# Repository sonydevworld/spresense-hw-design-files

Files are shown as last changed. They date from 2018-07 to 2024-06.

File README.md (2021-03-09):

# HW Informations.

Here you will find information about Spresense HW that you need if you would like to design your own boards.

| Product Name | User Friendly Name |
| --- |:---:|
| CXD5602PWBMAIN1 | Spresense main board |
| CXD5602PWBEXT1 | Spresense extension board |
| CXD5602PWBLM1 | Spresense LTE extension board|
| CXD5602PWBCAM1 | Spresense camera board |

The datasheets for the chipset is available from [Sony Semiconductor Solutions Corporation Website](https://www.sony-semicon.co.jp/e/products/smart-sensing/spresense/)

## Reference informations are here.

GNSS: GNSS chip antenna information <br>
Pin: Pin information <br>
main_board_addon_board: Add-on board design guideline <br>
Case: case design samples <br>

## License
These files are licensed under a [Creative Commons Attribution Share-Alike license](LICENSE.txt).

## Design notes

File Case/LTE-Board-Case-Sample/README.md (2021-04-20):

# The sample case for Spresense LTE extension board

Spresense LTE拡張 & Mainボード向けのケースのサンプルCADです。

 - LTE拡張ボード+Mainボードの組み合わせ
 - Mainボードのみ

で、ネジ止めできて使えます。

（ネジ情報）
https://developer.sony.com/develop/spresense/docs/hw_docs_ja.html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

ご自由にお使いください！

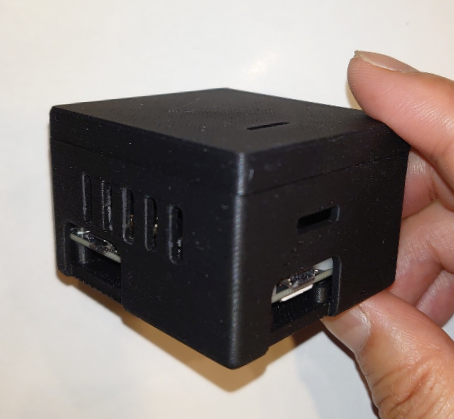
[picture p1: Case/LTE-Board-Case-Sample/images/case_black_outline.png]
black_outline


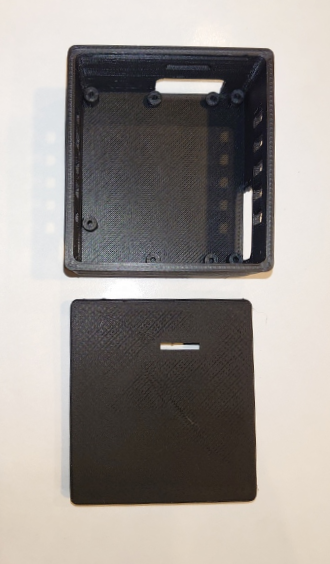
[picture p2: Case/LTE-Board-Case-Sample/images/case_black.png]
black


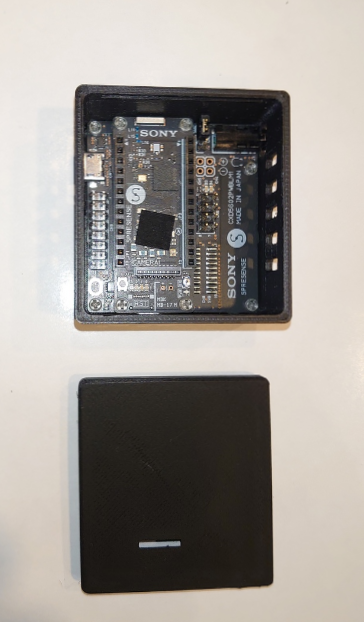
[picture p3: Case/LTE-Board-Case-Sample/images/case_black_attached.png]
black_attached


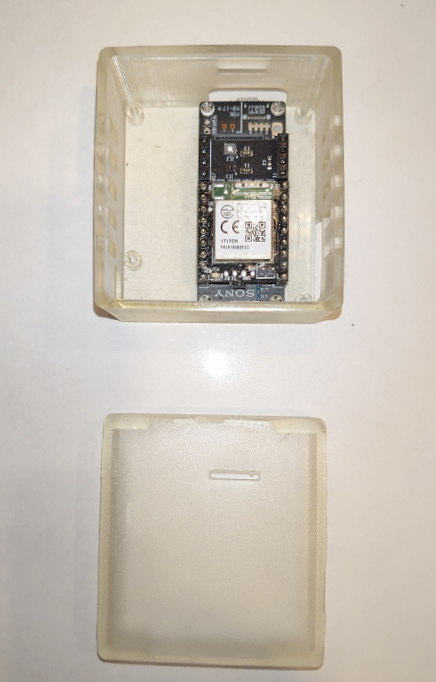
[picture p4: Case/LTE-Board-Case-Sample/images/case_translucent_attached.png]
translucent_attached


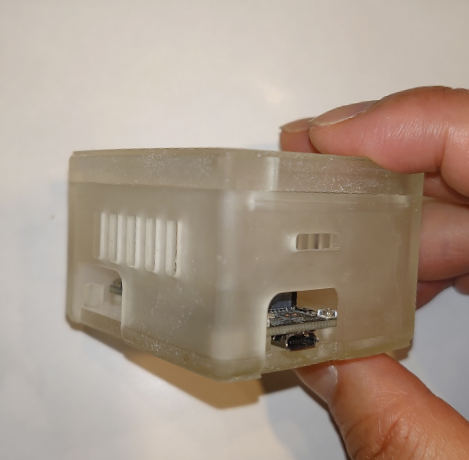
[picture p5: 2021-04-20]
Case/LTE-Board-Case-Sample/images/case_translucent_outline.png

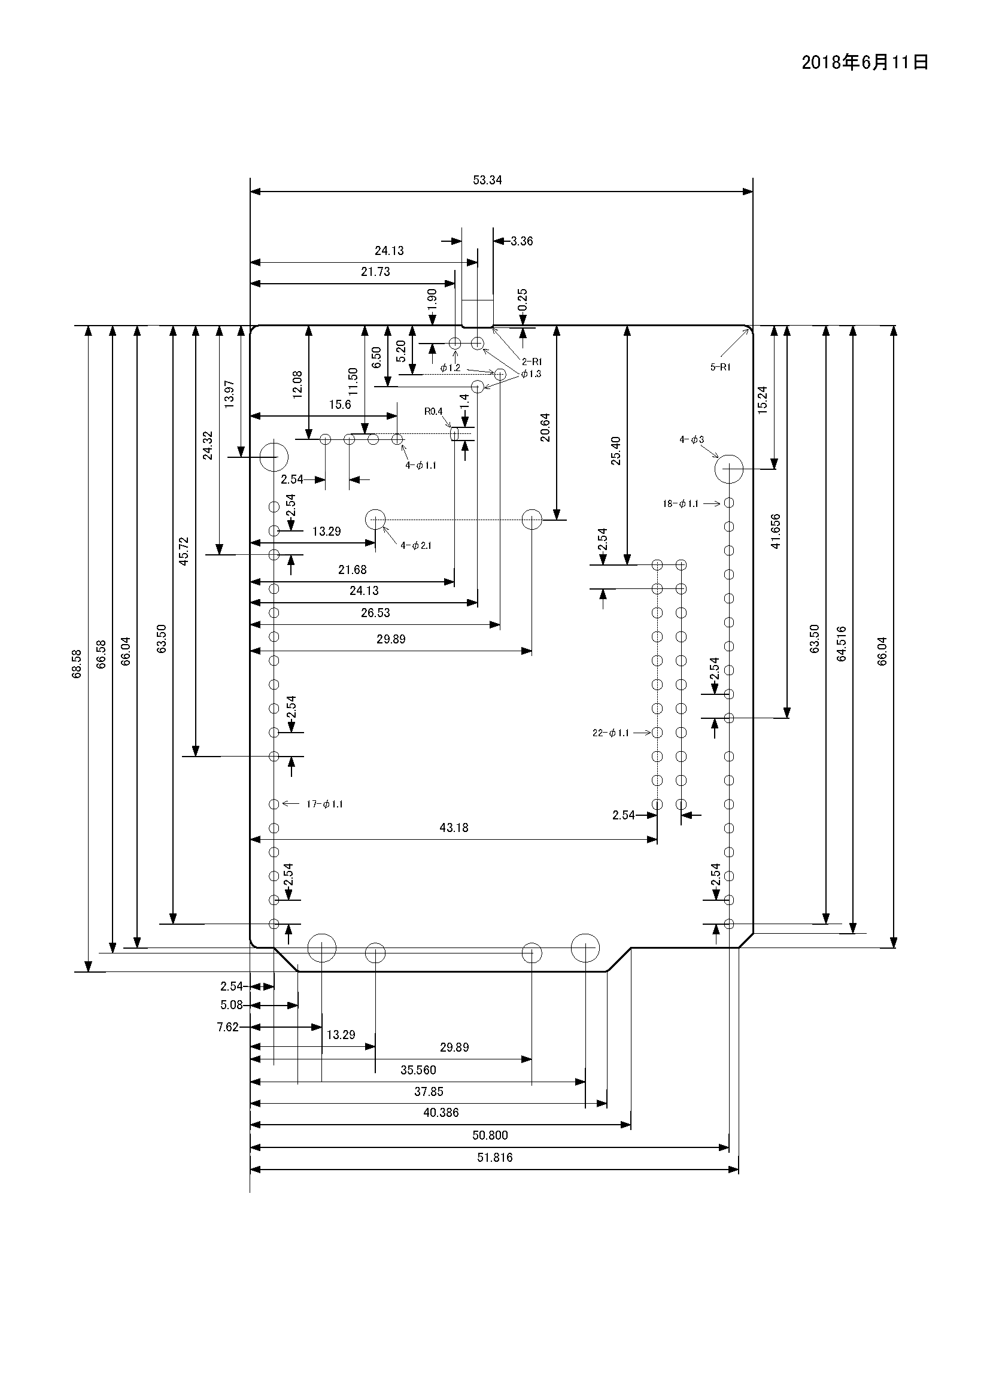
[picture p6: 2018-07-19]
CXD5602PWBEXT1/board_dimensions/CXD5602PWBEXT1_board_dimensions_ja.png

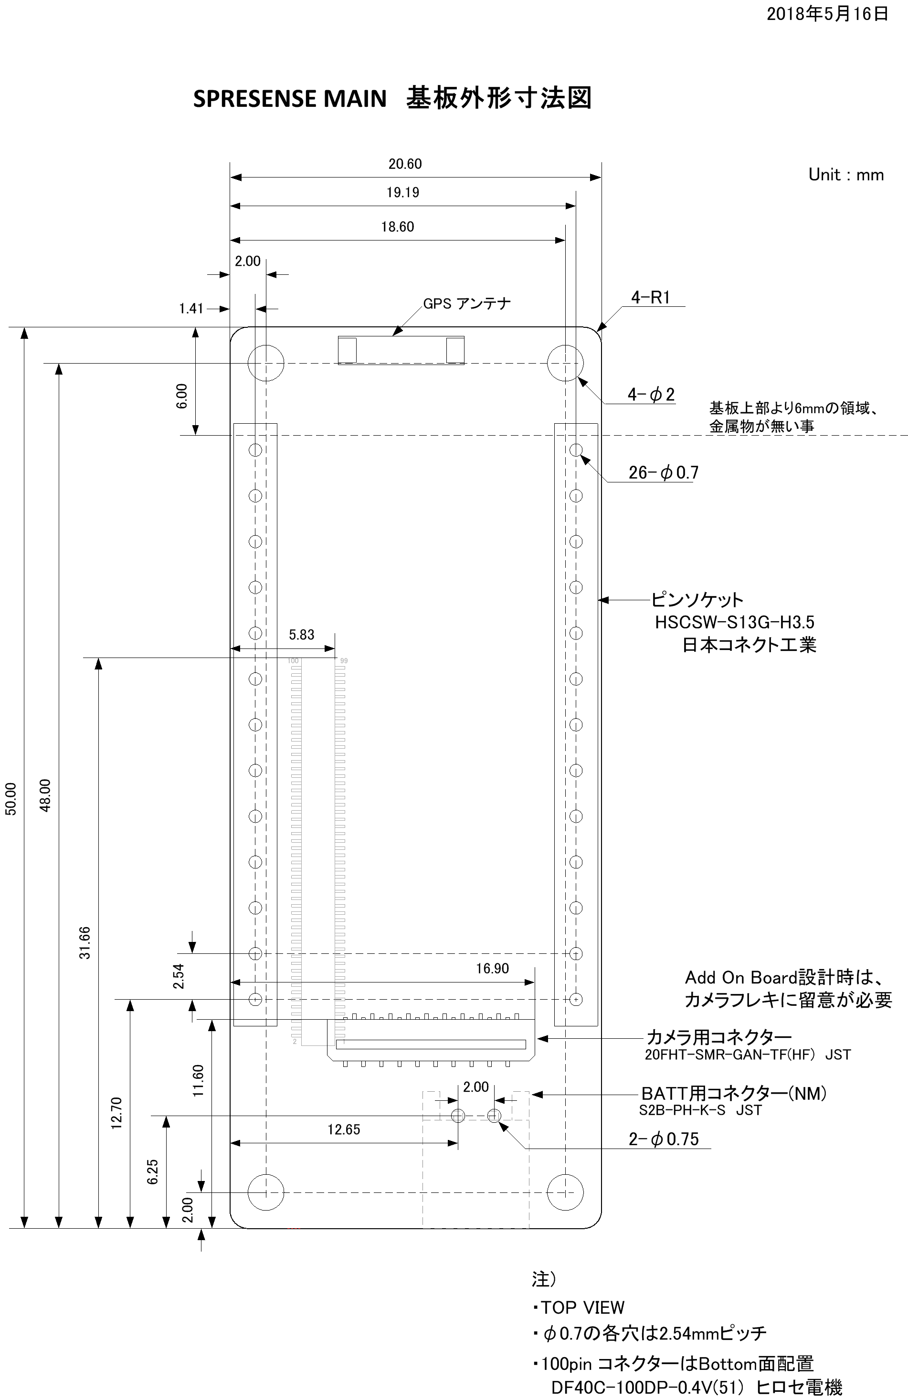
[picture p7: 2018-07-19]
CXD5602PWBMAIN1/board_dimensions/CXD5602PWBMAIN1_board_dimensions_ja.png

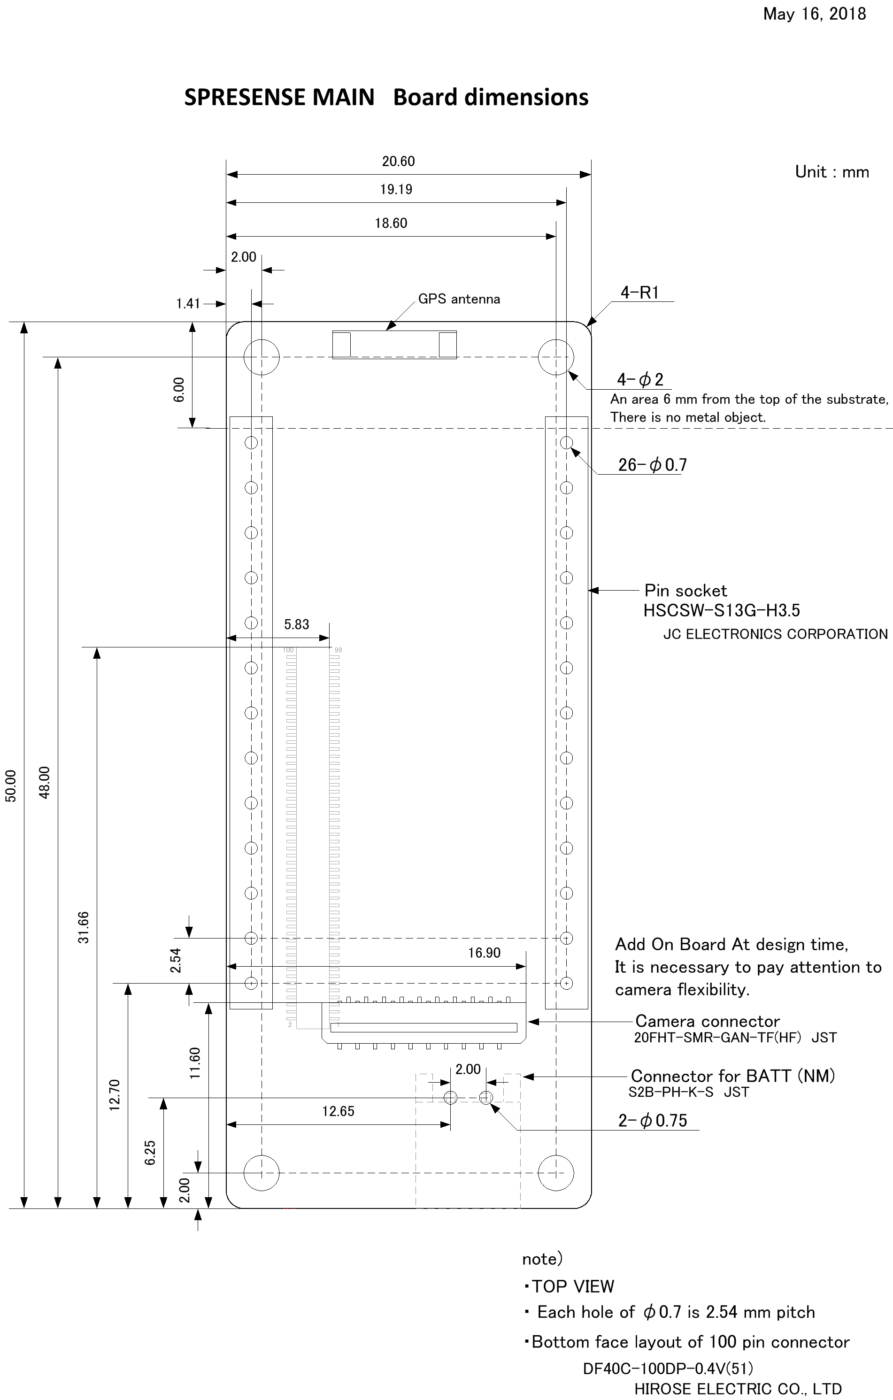
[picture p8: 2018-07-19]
CXD5602PWBMAIN1/board_dimensions/CXD5602PWBMAIN1_board_dimensions_en.png

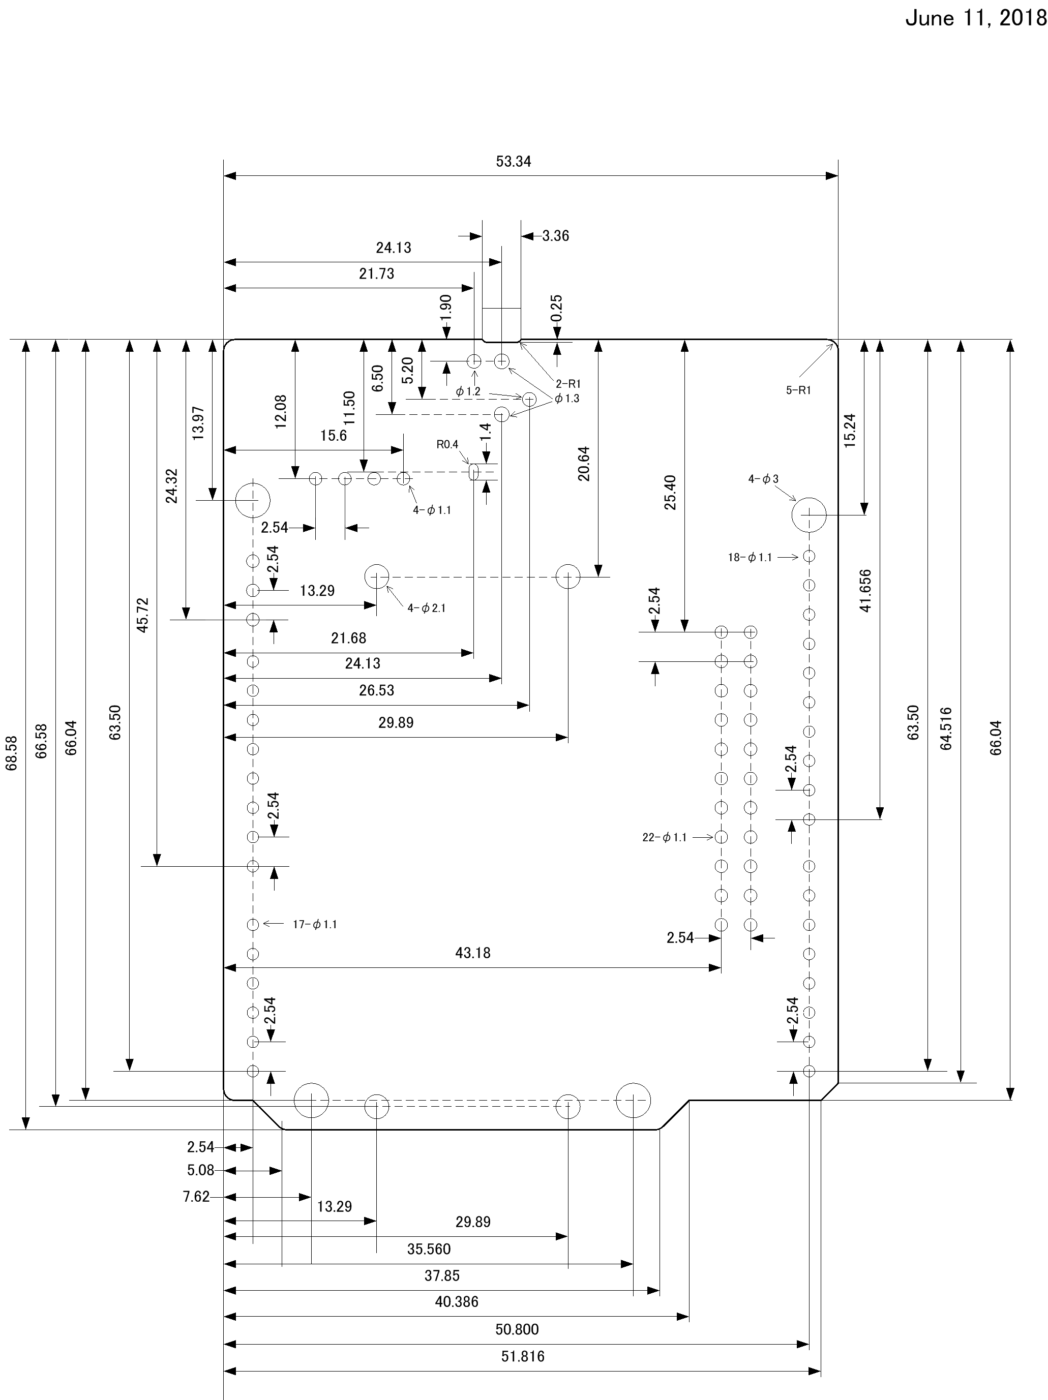
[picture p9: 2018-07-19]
CXD5602PWBEXT1/board_dimensions/en_drawing_20180611.png

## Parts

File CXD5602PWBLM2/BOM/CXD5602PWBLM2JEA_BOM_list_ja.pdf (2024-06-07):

CXD5602PWBLM2JEA BOM List | Sony Semiconductor Solutions
Qty | Ref | 名称 | Model | ベンダー
22 | C14,C27,C28,C30,C31,C32,C33,C34,C 35,C36,C37,C38,C39,C44,C45,C46,C5 0,C61,C64,C66,C67,C68 | セラミックコンデンサ 1uF (6.3V X5R 0603) | | 村田製作所
19 | C15,C16,C18,C19,C20,C21,C22,C23,C 29,C40,C41,C42,C43,C52,C54,C6,C62 ,C7,C8 | セラミックコンデンサ 0.1uF (16V X5R 0603) | | 村田製作所
2 | C25,C51 | セラミックコンデンサ 10uF（10V X5R 1608） | | 村田製作所
1 | C26 | セラミックコンデンサ 4700pF（25V X7R 0603) | | 村田製作所
1 | C55 | セラミックコンデンサ 15pF (50V C0G 0603) | | 村田製作所
2 | C56,C58 | セラミックコンデンサ 22uF (6.3V X5R 1608) | | 村田製作所
1 | CN1 | USB コネクタ (Micro-B) | UB-MC5BR3-SD204-4S-1 | 日本圧着端子製造
1 | CN10 | nano SIM コネクタ | FCD910-6M | TXGA
1 | CN11 | U.FL同軸コネクタ | U.FL-R-SMT-1 | ヒロセ電機
1 | CN2 | ピンヘッダー (2.54mm/3極) | HSAWW6-S03G-H2.5 | 日本コネクト工業
1 | CN3 | ボ-ドトゥボ-ドコネクタ(リセプタクル) 100極 | DF40HC(3.0)-100DS-0.4V （51） | ヒロセ電機
1 | CN6 | ピンヘッダー (2.54mm/2列/8極) | HSAWW6-D08G-H2.5 | 日本コネクト工業
1 | CN7 | MicroSD カードコネクタ | ST11S008V4HR2000 | 日本航空電子
1 | CN9 | ピンヘッダー (2.54mm/2列/16極) | HSAWW6-D16G-H2.5 | 日本コネクト工業
1 | CP1 | LTE モジュール | LBAD0XX1SC-602 | 村田製作所
3 | D1,D2,D5 | ショットキバリアダイオード | CUS15S30 | 東芝デバイス
1 | D3 | LED 青 (1005) | SMLP14BCNWT86N | ローム
1 | IC1 | LDO電圧レギュレータ (3.3V) | TCR3DF33 | 東芝デバイス
1 | IC10 | システムリセットIC | PST8416UL | ミネベアミツミ
1 | IC12 | DC/DCコンバーター | RP506K001C-TR | 日清紡マイクロデバイス
2 | IC13,IC14 | ロードスイッチ IC TCK111G | TCK111G | 東芝デバイス
1 | IC2 | LDO電圧レギュレータ (3.3V) | RP122K331D-TR | 日清紡マイクロデバイス
1 | IC3 | ワンゲート バスバッファ | TC7SZ126AFS | 東芝デバイス
1 | IC4 | ヘッドフォンアンプ | NJU72040V(TE2) | 日清紡マイクロデバイス
1 | IC5 | SDIO ロジックレベル変換付きポート拡張IC | TXS02612RTWR | テキサス・インスツルメン
3 | IC6,IC7,IC8 | 双方向ロジックレベル変換IC 4ch | LSF0204RUTR | テキサス・インスツルメン
1 | IC15 | ワンゲート バスバッファ | TC7SZ125AFS | 東芝デバイス
2 | IC16,IC9 | 双方向ロジックレベル変換IC 2ch | LSF0102DCTR | テキサス・インスツルメン
1 | J1 | ヘッドフォンジヤツク (4極) | 03-925R0-32BKA | エクセル電子
1 | L7 | チップインダクタ 4.7nH (2016) | DFE201612E-4R7M=P2 | 村田製作所
1 | Q1 | MOSFET Ｎ-ch | SSM6N58NU | 東芝デバイス
2 | Q2,Q4 | MOSFET Ｎ-ch | RUM002N02T2L | ローム

1 | Q3 | NPN デジタルトランジスタ | DTC044EMT2L | ローム
6 | R101,R37,R38,R39,R93,R95 | チｯプ抵抗 47KΩ (1/16W 1005 5%)
22 | R11,R18,R19,R22,R29,R3,R30,R34,R3 5,R36,R40,R44,R45,R49,R51,R6,R65,R 66,R89,R9,R98,R99 | チップ抵抗 0Ω（1005)
2 | R13,R15 | チｯプ抵抗 470KΩ (1/16W 1005 1%)
2 | R20,R21 | チｯプ抵抗 3.9KΩ (1/16W 1005 1%)
3 | R23,R24,R33 | チｯプ抵抗 2.2KΩ (1/16W 1005 5%)
4 | R25,R31,R32,R86 | チｯプ抵抗 100KΩ (1/16W 1005 5%)
1 | R27 | チｯプ抵抗 330KΩ (1/16W 1005 5%)
1 | R28 | チｯプ抵抗 4.7MΩ (1/16W 1005 5%)
1 | R4 | チｯプ抵抗 100KΩ (1/16W 1005 1%)
5 | R41,R42,R43,R48,R68 | チｯプ抵抗 470KΩ (1/16W 1005 5%)
1 | R5 | チｯプ抵抗 18KΩ (1/16W 1005 1%)
16 | R52,R53,R54,R56,R57,R58,R59,R60,R 61,R62,R70,R71,R79,R80,R87,R88 | チｯプ抵抗 1KΩ (1/16W 1005 5%)
1 | R63 | チｯプ抵抗 620KΩ (1/16W 1005 1%)
1 | R64 | チｯプ抵抗 110KΩ (1/16W 1005 1%)
1 | R69 | チｯプ抵抗 100Ω (1/16W 1005 5%)
1 | R7 | チｯプ抵抗 1MΩ (1/16W 1005 5%)
2 | R72,R81 | チｯプ抵抗 180KΩ (1/16W 1005 5%)
4 | R73,R77,R90,R92 | チｯプ抵抗 10KΩ (1/16W 1005 1%)
1 | R74 | チップ抵抗 0Ω（1608)
2 | R75,R76 | チｯプ抵抗 27KΩ (1/16W 1005 1%)
2 | R84,R85 | チｯプ抵抗 620KΩ (1/16W 1005 5%)
2 | R91,R94 | チｯプ抵抗 62KΩ (1/16W 1005 1%)
1 | S1 | プッシュスイッチ | SKRPADE010 | アルプスアルパイン
2 | VR1,VR2 | チｯプバリスタ (1005) | AVRL101A3R3FTA | TDK

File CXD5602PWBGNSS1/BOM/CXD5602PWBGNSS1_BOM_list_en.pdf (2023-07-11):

CXD5602PWBGNSS1W BOM List | Sony Semiconductor Solutions
Qty | Ref | Name | Model | Vender
2 | C1,C18 | Ceramic capacitor 1uF (6.3V X5R 0603)
11 | C10,C12,C14,C15,C16,C17,C19,C20, C22,C7,C8 | Ceramic capacitor 0.1uF (16V X5R 0603)
4 | C11,C13,C21,C23 | Ceramic capacitor 4.7uF (6.3V X5R 0603)
2 | C2,C9 | Ceramic capacitor 1000pF (25V X7R 0603)
2 | C3,C4 | Ceramic capacitor 100pF (50V C0G 0603)
1 | C5 | Ceramic capacitor 4.7pF (50V C0G 0603)
1 | C6 | Ceramic capacitor 3.3pF (50V C0G 0603)
2 | CN1,CN2 | Pin Socket (2.54mm pitch/13P) | HSCSW-S13G-L5.6 | JC Electronics
1 | D1 | Schottky diode | CUS10S30 | Toshiba Electronic Devices & Storage
1 | IC1 | Power Switch IC | XC8109AC10ER-G | TOREX SEMICONDUCTOR (https://product.torexsemi.com/ja/series/xc8109)
1 | IC2 | Load Switch IC | TCK107AG | Toshiba Electronic Devices & Storage
1 | IC3 | GNSS navigation IC | CXD5610GF-T2 | Sony Semiconductor Solutions
1 | J1 | U.FL coaxial connector | U.FL-R-SMT-1 | Hirose Electric
3 | L1,L7,L8 | Chip ferrite bead (0603) | BLM03AG121SN1 | Murata
2 | L10,L9 | Chip ferrite bead (0603) | BLM03AX121SN1D | Murata
1 | L2 | Chip inductor 33nH (1005) | LQG15HS33NJ02D | Murata
1 | L3 | Chip inductor 3.9nH (0603) | LQP03TN3N9B02D | Murata
1 | L4 | Chip inductor 9.1nH (0603) | LQP03TN9N1J02D | Murata
1 | L5 | Chip inductor 12nH (0603) | LQP03TN12NJ02D | Murata
1 | L6 | Chip inductor 6.8nH (0603) | LQP03TN6N8J02D | Murata
1 | R1 | Chip resistor 470KΩ (1/20W 0603 1%)
2 | R10,R12 | Chip resistor 0Ω(1005)
1 | R15 | Chip resistor 100KΩ (1/20W 0603 1%)

2 | R17,R19 | Chip resistor 1Ω (0.125W 1005 1%)
1 | R18 | Chip resistor 470Ω (1/20W 0603 1%)
3 | R2,R3,R4 | Chip resistor 47KΩ (1/20W 0603 1%)
2 | R6,R7 | Chip resistor 4.7KΩ (1/20W 0603 1%)
1 | RV1 | EMI filter (0603) | LXES03TBB1-141 | Murata
1 | SAW1 | SAW filter (GNSS) | SAWFZ1G17AB0E0A | Murata
1 | X1 | Crystal oscillator 26MHz (TCXO) | NT1612SA 26MHz | Nihon Dempa Kogyo
1 | X2 | Tuning fork crystal oscillator 32.768KHｚ | SH‑32R | Seiko Instruments

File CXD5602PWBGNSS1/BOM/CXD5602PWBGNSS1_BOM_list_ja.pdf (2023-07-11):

CXD5602PWBGNSS1W BOM List | Sony Semiconductor Solutions
Qty | Ref | 名称 | Model | ベンダー
2 | C1,C18 | Ceramic capacitor 1uF (6.3V X5R 0603)
11 | C10,C12,C14,C15,C16,C17,C19,C20, C22,C7,C8 | Ceramic capacitor 0.1uF (16V X5R 0603)
4 | C11,C13,C21,C23 | Ceramic capacitor 4.7uF (6.3V X5R 0603)
2 | C2,C9 | Ceramic capacitor 1000pF (25V X7R 0603)
2 | C3,C4 | Ceramic capacitor 100pF (50V C0G 0603)
1 | C5 | Ceramic capacitor 4.7pF (50V C0G 0603)
1 | C6 | Ceramic capacitor 3.3pF (50V C0G 0603)
2 | CN1,CN2 | ピンソケット (2.54mmピッチ/13極) | HSCSW-S13G-L5.6 | 日本コネクト工業
1 | D1 | ショットキバリアダイオード | CUS10S30 | 東芝デバイス＆ストレージ
1 | IC1 | 電源スイッチ IC | XC8109AC10ER-G | トレックス・セミコンダクター (https://product.torexsemi.com/ja/series/xc8109)
1 | IC2 | ロードスイッチIC | TCK107AG | 東芝デバイス＆ストレージ
1 | IC3 | GNSS測位IC | CXD5610GF-T2 | ソニーセミコンダクタソリューションズ
1 | J1 | U.FL同軸コネクタ | U.FL-R-SMT-1 | ヒロセ電機
3 | L1,L7,L8 | チップフェライトビーズ (0603) | BLM03AG121SN1 | Murata
2 | L10,L9 | チップフェライトビーズ (0603) | BLM03AX121SN1D | Murata
1 | L2 | Chip inductor 33nH (1005) | LQG15HS33NJ02D | Murata
1 | L3 | Chip inductor 3.9nH (0603) | LQP03TN3N9B02D | Murata
1 | L4 | Chip inductor 9.1nH (0603) | LQP03TN9N1J02D | Murata
1 | L5 | Chip inductor 12nH (0603) | LQP03TN12NJ02D | Murata
1 | L6 | Chip inductor 6.8nH (0603) | LQP03TN6N8J02D | Murata
1 | R1 | Chip resistor 470KΩ (1/20W 0603 1%)
2 | R10,R12 | Chip resistor 0Ω(1005)
1 | R15 | Chip resistor 100KΩ (1/20W 0603 1%)

2 | R17,R19 | Chip resistor 1Ω (0.125W 1005 1%)
1 | R18 | Chip resistor 470Ω (1/20W 0603 1%)
3 | R2,R3,R4 | Chip resistor 47KΩ (1/20W 0603 1%)
2 | R6,R7 | Chip resistor 4.7KΩ (1/20W 0603 1%)
1 | RV1 | EMIフィルタ (0603) | LXES03TBB1-141 | Murata
1 | SAW1 | SAWフィルタ (GNSS) | SAWFZ1G17AB0E0A | Murata
1 | X1 | 温度補償型水晶発振器 26MHｚ | NT1612SA 26MHz | 日本電波工業
1 | X2 | 音叉型水晶発振器 32.768KHｚ | SH‑32R | セイコーインスツル

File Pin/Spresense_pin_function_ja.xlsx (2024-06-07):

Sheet: ピンリスト
Main |  | Ext |  | Cam |  | LTE(LM1) |  | LTE(LM2) |  | 回路図上の名前 | ArduinoIDE 上の名称 | SDK上の名称 | SDK上の ピン番号 | タイプ | dir | 電圧 | 電源投入後 の状態 |  | Arduino起動後 |  | SDK起動後 |  | 接続先 | ピングループ |  | CXD5602GG ピン機能 |  |  |  | 最大絶対定格 電圧(V) | 拡張ボード上の機能 | 説明
Ref | ピン | Ref | ピン | Ref | ピン | Ref | ピン | Ref | ピン |  |  |  |  |  |  |  | dir | 初期値 | dir | 初期値 | dir | 初期値 |  | モード名 | 仕様書 | モード0 | モード1 | モード2 | モード3
JP1 | 1 |  |  |  |  |  |  |  |  | GND | － | － | － | Power | － | － | － | － | － | － | － | － | － | － | － | － | － | － | －
JP1 | 2 |  |  |  |  |  |  |  |  | UART2_TX | D01 | PIN_UART2_TXD | 67 | Digital | I/O | 1.8 | － | Hi-Z | － | Hi-Z | － | Hi-Z | CXD5602GG | UART2 | P1n | GPIO | UART2_TXD | － | GPIO | 2.5
JP1 | 3 |  |  |  |  |  |  |  |  | UART2_RX | D00 | PIN_UART2_RXD | 68 | Digital | I/O | 1.8 | － | Hi-Z | － | Hi-Z | － | Hi-Z | CXD5602GG | UART2 | P1n | GPIO | UART2_RXD | － | GPIO | 2.5
JP1 | 4 |  |  |  |  |  |  |  |  | UART2_RTS | D28 | PIN_UART2_RTS | 70 | Digital | I/O | 1.8 | － | Hi-Z | － | Hi-Z | － | Hi-Z | CXD5602GG | UART2 | P1n | GPIO | UART2_RTS | － | GPIO | 2.5
JP1 | 5 |  |  |  |  |  |  |  |  | UART2_CTS | D27 | PIN_UART2_CTS | 69 | Digital | I/O | 1.8 | － | Hi-Z | － | Hi-Z | － | Hi-Z | CXD5602GG | UART2 | P1n | GPIO | UART2_CTS | － | GPIO | 2.5
JP1 | 6 |  |  |  |  |  |  |  |  | I2S0_BCK | D26 | PIN_I2S0_BCK | 93 | Digital | I/O | 1.8 | － | Hi-Z | － | Hi-Z | － | Hi-Z | CXD5602GG | I2S0 | P1v | GPIO | I2S0_BCK | － | GPIO | 2.5
JP1 | 7 |  |  |  |  |  |  |  |  | I2S0_LRCK | D25 | PIN_I2S0_LRCK | 94 | Digital | I/O | 1.8 | － | Hi-Z | － | Hi-Z | － | Hi-Z | CXD5602GG | I2S0 | P1v | GPIO | I2S0_LRCK | － | GPIO | 2.5
JP1 | 8 |  |  |  |  |  |  |  |  | SPI5_CS_X | D24 | PIN_SPI5_CS_X | 76 | Digital | I/O | 1.8 | － | Hi-Z | － | Hi-Z | － | Hi-Z | CXD5602GG | EMMCA | P1p | GPIO | EMMC_CMD | SPI5_CS_X | GPIO | 2.5
JP1 | 9 |  |  |  |  |  |  |  |  | SPI5_SCK | D23 | PIN_SPI5_SCK | 75 | Digital | I/O | 1.8 | － | Hi-Z | － | Hi-Z | － | Hi-Z | CXD5602GG | EMMCA | P1p | GPIO | EMMC_CLK | SPI5_SCK | GPIO | 2.5
JP1 | 10 |  |  |  |  |  |  |  |  | 3.3V | － | － | － | Power | O | 3.3 | O | － | O | － | O | － | － | － | － | － | － | － | －
JP1 | 11 |  |  |  |  |  |  |  |  | 1.8V | － | － | － | Power | O | 1.8 | O | － | O | － | O | － | － | － | － | － | － | － | －
JP1 | 12 |  |  |  |  |  |  |  |  | SEN_IRQ | D22 | PIN_SEN_IRQ_IN | 37 | Digital | I/O | 1.8 | － | Hi-Z | － | Hi-Z | － | Hi-Z | CXD5602GG | SEN_IRQ_IN | P1e | GPIO | SEN_IRQ_IN | － | － | 2.5
JP1 | 13 |  |  |  |  |  |  |  |  | SEN_AIN4 | A2 | LPADC2 | － | Analog | I | ～0.7 | I | － | I | － | I | － | CXD5602GG |  | － | － | － | － | － | 1.05
JP2 | 1 |  |  |  |  |  |  |  |  | XRST | － | (SPR_RST_X) | － | Digital | O | 1.8 | － | Low | O | High | O | High | CXD5602GG | － | － | － | － | － | －
JP2 | 2 |  |  |  |  |  |  |  |  | 1.8V | － | － | － | Power | O | 1.8 | O | － | O | － | O | － | － | － | － | － | － | － | －
JP2 | 3 |  |  |  |  |  |  |  |  | 3.7V(4.0V) | － | － | － | Power | I/O | 3.6-4.4 | O | － | O | － | O | － | － | － | － | － | － | － | － | 7
JP2 | 4 |  |  |  |  |  |  |  |  | GPIO | D21 | PIN_EMMC_DATA3 | 80 | Digital | I/O | 1.8 | － | Hi-Z | － | Hi-Z | － | Hi-Z | CXD5602GG | EMMCB | P1q | GPIO | EMMC_DATA3 | － | GPIO | 2.5
JP2 | 5 |  |  |  |  |  |  |  |  | GPIO | D20 | PIN_EMMC_DATA2 | 79 | Digital | I/O | 1.8 | － | Hi-Z | － | Hi-Z | － | Hi-Z | CXD5602GG | EMMCB | P1q | GPIO | EMMC_DATA2 | － | GPIO | 2.5
JP2 | 6 |  |  |  |  |  |  |  |  | I2S0_DATA_IN | D19 | PIN_I2S0_DATA_IN | 95 | Digital | I/O | 1.8 | － | Hi-Z | － | Hi-Z | － | Hi-Z | CXD5602GG | I2S0 | P1v | GPIO | I2S0_DATA_IN | － | GPIO | 2.5
JP2 | 7 |  |  |  |  |  |  |  |  | I2S0_DATA_OUT | D18 | PIN_I2S0_DATA_OUT | 96 | Digital | I/O | 1.8 | － | Hi-Z | － | Hi-Z | － | Hi-Z | CXD5602GG | I2S0 | P1v | GPIO | I2S0_DATA_OUT | － | GPIO | 2.5
JP2 | 8 |  |  |  |  |  |  |  |  | SPR_SPI5_MISO | D17 | PIN_SPI5_MISO | 78 | Digital | I/O | 1.8 | － | Hi-Z | － | Hi-Z | － | Hi-Z | CXD5602GG | EMMCA | P1p | GPIO | EMMC_DATA1 | SPI5_MISO | GPIO | 2.5
JP2 | 9 |  |  |  |  |  |  |  |  | SPR_SPI5_MOSI | D16 | PIN_SPI5_MOSI | 77 | Digital | I/O | 1.8 | － | Hi-Z | － | Hi-Z | － | Hi-Z | CXD5602GG | EMMCA | P1p | GPIO | EMMC_DATA0 | SPI5_MOSI | GPIO | 2.5
JP2 | 10 |  |  |  |  |  |  |  |  | GND | － | － | － | Power | － | － | － | － | － | － | － | － | － | － | － | － | － | － | －
JP2 | 11 |  |  |  |  |  |  |  |  | I2C0_SCL | D15 | PIN_I2C0_BCK | 44 | Digital | I/O | 1.8 | － | High | I | High | I | High | CXD5602GG | I2C0 | P1j | GPIO | I2C0_BCK | － | － | 2.5
JP2 | 12 |  |  |  |  |  |  |  |  | I2C0_SDA | D14 | PIN_I2C0_BDT | 45 | Digital | I/O | 1.8 | － | High | I | High | I | High | CXD5602GG | I2C0 | P1j | GPIO | I2C0_BDT | － | － | 2.5
JP2 | 13 |  |  |  |  |  |  |  |  | SEN_AIN5 | A3 | LPADC3 | － | Analog | I | ～0.7 | I | － | I | － | I | － | CXD5602GG | － | － | － | － | － | － | 1.05
CN5 | 1 |  |  | CN1 | 1 |  |  |  |  | MCLK | － | － | － | Digital | O | 1.8 | － | － | O | Hi-Z | O | Hi-Z | 26MHz TCXO | － | － | － | － | － | － | 2.5
CN5 | 2 |  |  | CN1 | 2 |  |  |  |  | GND | － | － | － | Power | － | － | － | － | － | － | － | － | － | － | － | － | － | － | －
CN5 | 3 |  |  | CN1 | 3 |  |  |  |  | I2C_SDA | － | PIN_SPI0_MISO | 20 | Digital | I/O | 1.8 | － | High | － | High | I | High | CXD5602GG | I2C2 | P17 | GPIO | I2C2_BDT | SPI0_MISO | GPIO | 2.5
CN5 | 4 |  |  | CN1 | 4 |  |  |  |  | I2C_SCL | － | PIN_SPI0_MOSI | 19 | Digital | I/O | 1.8 | － | High | － | High | I | High | CXD5602GG | I2C2 | P17 | GPIO | I2C2_BCK | SPI0_MOSI | GPIO | 2.5
CN5 | 5 |  |  | CN1 | 5 |  |  |  |  | XRS | D35 | PIN_SDIO_DIR1_3 | 91 | Digital | I/O | 1.8 | － | Hi-Z | － | Hi-Z | － | Hi-Z | CXD5602GG | SDIOC | P1t | GPIO | SDIO_DIR1_3 | GPIO | GPIO | 2.5
CN5 | 6 |  |  | CN1 | 6 |  |  |  |  | PWDN | D34 | PIN_SDIO_DIR0 | 90 | Digital | I/O | 1.8 | － | Hi-Z | － | Hi-Z | － | Hi-Z | CXD5602GG | SDIOC | P1t | GPIO | SDIO_DIR0 | GPIO | GPIO | 2.5
CN5 | 7 |  |  | CN1 | 7 |  |  |  |  | LDO_EN | － | (ACP_GPO4) | － | Digital | O | 3.6-4.4 | O | Hi-Z | O | Low | O | Low | CXD5247GF | － | － | － | － | － | －
CN5 | 8 |  |  | CN1 | 8 |  |  |  |  | VDD_3.7V | － | － | － | Power | O | 3.6-4.4 | O | － | O | － | O | － | － | － | － | － | － | － | －
CN5 | 9 |  |  | CN1 | 9 |  |  |  |  | IS_DATA4 | － | PIN_IS_DATA4 | 63 | Digital | I/O | 1.8 | － | Hi-Z | － | Hi-Z | I | － | CXD5602GG | IS | P1m | GPIO | IS_DATA4 | GPIO | GPIO | 2.5
CN5 | 10 |  |  | CN1 | 10 |  |  |  |  | IS_DATA6 | － | PIN_IS_DATA6 | 65 | Digital | I/O | 1.8 | － | Hi-Z | － | Hi-Z | I | － | CXD5602GG | IS | P1m | GPIO | IS_DATA6 | GPIO | GPIO | 2.5
CN5 | 11 |  |  | CN1 | 11 |  |  |  |  | IS_DATA0 | － | PIN_IS_DATA0 | 59 | Digital | I/O | 1.8 | － | Hi-Z | － | Hi-Z | I | － | CXD5602GG | IS | P1m | GPIO | IS_DATA0 | GPIO | GPIO | 2.5
CN5 | 12 |  |  | CN1 | 12 |  |  |  |  | IS_DATA7 | － | PIN_IS_DATA7 | 66 | Digital | I/O | 1.8 | － | Hi-Z | － | Hi-Z | I | － | CXD5602GG | IS | P1m | GPIO | IS_DATA7 | GPIO | GPIO | 2.5
CN5 | 13 |  |  | CN1 | 13 |  |  |  |  | IS_DATA5 | － | PIN_IS_DATA5 | 64 | Digital | I/O | 1.8 | － | Hi-Z | － | Hi-Z | I | － | CXD5602GG | IS | P1m | GPIO | IS_DATA5 | GPIO | GPIO | 2.5
CN5 | 14 |  |  | CN1 | 14 |  |  |  |  | IS_DATA2 | － | PIN_IS_DATA2 | 61 | Digital | I/O | 1.8 | － | Hi-Z | － | Hi-Z | I | － | CXD5602GG | IS | P1m | GPIO | IS_DATA2 | GPIO | GPIO | 2.5
CN5 | 15 |  |  | CN1 | 15 |  |  |  |  | IS_HSYNC | － | PIN_IS_HSYNC | 58 | Digital | I/O | 1.8 | － | Hi-Z | － | Hi-Z | I | － | CXD5602GG | IS | P1m | GPIO | IS_HSYNC | GPIO | GPIO | 2.5
CN5 | 16 |  |  | CN1 | 16 |  |  |  |  | IS_DATA3 | － | PIN_IS_DATA3 | 62 | Digital | I/O | 1.8 | － | Hi-Z | － | Hi-Z | I | － | CXD5602GG | IS | P1m | GPIO | IS_DATA3 | GPIO | GPIO | 2.5
CN5 | 17 |  |  | CN1 | 17 |  |  |  |  | IS_VSYNC | － | PIN_IS_VSYNC | 57 | Digital | I/O | 1.8 | － | Hi-Z | － | Hi-Z | I | － | CXD5602GG | IS | P1m | GPIO | IS_VSYNC | GPIO | GPIO | 2.5
CN5 | 18 |  |  | CN1 | 18 |  |  |  |  | IS_DATA1 | － | PIN_IS_DATA1 | 60 | Digital | I/O | 1.8 | － | Hi-Z | － | Hi-Z | I | － | CXD5602GG | IS | P1m | GPIO | IS_DATA1 | GPIO | GPIO | 2.5
CN5 | 19 |  |  | CN1 | 19 |  |  |  |  | GND | － | － | － | Power | － | － | － | － | － | － | － | － | － | － | － | － | － | － | －
CN5 | 20 |  |  | CN1 | 20 |  |  |  |  | IS_CLK | － | PIN_IS_CLK | 56 | Digital | I | 1.8 | I | － | I | － | I | － | CXD5602GG | IS | P1m | GPIO | IS_CLK | GPIO | GPIO | 2.5
CN4[L] | 1 | CN4[L] | 1 |  |  | CN4[L] | 1 | CN4[L] | 1 | 3.3V_AU | － | － | － | Power | O | 3.3 | I | － | I | － | I | － | － | － | － | － | － | － | －
CN4[L] | 3 | CN4[L] | 3 |  |  | CN4[L] | 3 | CN4[L] | 3 | 3.3V_AU | － | － | － | Power | O | 3.3 | I | － | I | － | I | － | － | － | － | － | － | － | －
CN4[L] | 5 | CN4[L] | 5 |  |  | CN4[L] | 5 | CN4[L] | 5 | ACP_MICA | － | － | － | Analog | I | － | I | － | I | － | I | － | CXD5247GF | － | － | － | － | － | －
CN4[L] | 7 | CN4[L] | 7 |  |  | CN4[L] | 7 | CN4[L] | 7 | ACP_MICB | － | － | － | Analog | I | － | I | － | I | － | I | － | CXD5247GF | － | － | － | － | － | －
CN4[L] | 9 | CN4[L] | 9 |  |  | CN4[L] | 9 | CN4[L] | 9 | ACP_MICC | － | － | － | Analog | I | － | I | － | I | － | I | － | CXD5247GF | － | － | － | － | － | －
CN4[L] | 11 | CN4[L] | 11 |  |  | CN4[L] | 11 | CN4[L] | 11 | ACP_MICD | － | － | － | Analog | I | － | I | － | I | － | I | － | CXD5247GF | － | － | － | － | － | －
CN4[L] | 13 | CN4[L] | 13 |  |  | CN4[L] | 13 | CN4[L] | 13 | ACP_MICBIASA | － | － | － | Analog | O | 2 | O | － | O | － | O | － | CXD5247GF | － | － | － | － | － | －
CN4[L] | 15 | CN4[L] | 15 |  |  | CN4[L] | 15 | CN4[L] | 15 | ACP_MICBIASB | － | － | － | Analog | O | 2 | O | － | O | － | O | － | CXD5247GF | － | － | － | － | － | －
CN4[L] | 17 | CN4[L] | 17 |  |  | CN4[L] | 17 | CN4[L] | 17 | AGND_MIC | － | － | － | Power | － | － | － | － | － | － | － | － | － | － | － | － | － | － | －
CN4[L] | 19 | CN4[L] | 19 |  |  | CN4[L] | 19 | CN4[L] | 19 | SPR_I2C0_SCL | D15 | PIN_I2C0_BCK | 44 | Digital | I/O | 1.8 | － | High | I | High | I | High | CXD5602GG | I2C0 | P1j | GPIO | I2C0_BCK | － | － | 2.5
CN4[L] | 21 | CN4[L] | 21 |  |  | CN4[L] | 21 | CN4[L] | 21 | SPR_I2C0_SDA | D14 | PIN_I2C0_BDT | 45 | Digital | I/O | 1.8 | － | High | I | High | I | High | CXD5602GG | I2C0 | P1j | GPIO | I2C0_BDT | － | － | 2.5
CN4[L] | 23 | CN4[L] | 23 |  |  | CN4[L] | 23 | CN4[L] | 23 | SPR_SPI4_SCK | D13 | PIN_SPI4_SCK | 72 | Digital | I/O | 1.8 | － | Hi-Z | － | Hi-Z | － | Hi-Z | CXD5602GG | SPI4 | P1o | GPIO | SPI4_SCK | － | GPIO | 2.5
CN4[L] | 25 | CN4[L] | 25 |  |  | CN4[L] | 25 | CN4[L] | 25 | SPR_SPI4_MISO | D12 | PIN_SPI4_MISO | 74 | Digital | I/O | 1.8 | － | Hi-Z | － | Hi-Z | － | Hi-Z | CXD5602GG | SPI4 | P1o | GPIO | SPI4_MISO | － | GPIO | 2.5
CN4[L] | 27 | CN4[L] | 27 |  |  | CN4[L] | 27 | CN4[L] | 27 | SPR_SPI4_MOSI | D11 | PIN_SPI4_MOSI | 73 | Digital | I/O | 1.8 | － | Hi-Z | － | Hi-Z | － | Hi-Z | CXD5602GG | SPI4 | P1o | GPIO | SPI4_MOSI | － | GPIO | 2.5
CN4[L] | 29 | CN4[L] | 29 |  |  | CN4[L] | 29 | CN4[L] | 29 | SPR_SPI4_CS_X | D10 | PIN_SPI4_CS_X | 71 | Digital | I/O | 1.8 | － | Hi-Z | － | Hi-Z | － | Hi-Z | CXD5602GG | SPI4 | P1o | GPIO | SPI4_CS_X | － | GPIO | 2.5
CN4[L] | 31 | CN4[L] | 31 |  |  | CN4[L] | 31 | CN4[L] | 31 | SPR_PWM2 | D09 | PIN_PWM2 | 48 | Digital | I/O | 1.8 | － | Hi-Z | － | Hi-Z | － | Hi-Z | CXD5602GG | PWMB | P1l | GPIO | PWM2 | I2C1_BCK | － | 2.5
CN4[L] | 33 | CN4[L] | 33 |  |  | CN4[L] | 33 | CN4[L] | 33 | SPR_I2S0_LRCK | D25 | PIN_I2S0_LRCK | 94 | Digital | I/O | 1.8 | － | Hi-Z | － | Hi-Z | － | Hi-Z | CXD5602GG | I2S0 | P1v | GPIO | I2S0_LRCK | － | GPIO | 2.5
CN4[L] | 35 | CN4[L] | 35 |  |  | CN4[L] | 35 | CN4[L] | 35 | GND | － | － | － | Power | － | － | － | － | － | － | － | － | － | － | － | － | － | － | －
CN4[L] | 37 | CN4[L] | 37 |  |  | CN4[L] | 37 | CN4[L] | 37 | SPR_I2S0_DATA_OUT | D18 | PIN_I2S0_DATA_OUT | 96 | Digital | I/O | 1.8 | － | Hi-Z | － | Hi-Z | － | Hi-Z | CXD5602GG | I2S0 | P1v | GPIO | I2S0_DATA_OUT | － | GPIO | 2.5
CN4[L] | 39 | CN4[L] | 39 |  |  | CN4[L] | 39 | CN4[L] | 39 | SPR_PWM0 | D06 | PIN_PWM0 | 46 | Digital | I/O | 1.8 | － | Hi-Z | － | Hi-Z | － | Hi-Z | CXD5602GG | PWMA | P1k | GPIO | PWM0 | － | － | 2.5
CN4[L] | 41 | CN4[L] | 41 |  |  | CN4[L] | 41 | CN4[L] | 41 | SPR_PWM1 | D05 | PIN_PWM1 | 47 | Digital | I/O | 1.8 | － | Hi-Z | － | Hi-Z | － | Hi-Z | CXD5602GG | PWMA | P1k | GPIO | PWM1 | GPIO | － | 2.5
CN4[L] | 43 | CN4[L] | 43 |  |  | CN4[L] | 43 | CN4[L] | 43 | SPR_I2S0_DATA_IN | D19 | PIN_I2S0_DATA_IN | 95 | Digital | I/O | 1.8 | － | Hi-Z | － | Hi-Z | － | Hi-Z | CXD5602GG | I2S0 | P1v | GPIO | I2S0_DATA_IN | － | GPIO | 2.5
CN4[L] | 45 | CN4[L] | 45 |  |  | CN4[L] | 45 | CN4[L] | 45 | SPR_PWM3 | D03 | PIN_PWM3 | 49 | Digital | I/O | 1.8 | － | Hi-Z | － | Hi-Z | － | Hi-Z | CXD5602GG | PWMB | P1l | GPIO | PWM3 | I2C1_BDT | － | 2.5
CN4[L] | 47 | CN4[L] | 47 |  |  | CN4[L] | 47 | CN4[L] | 47 | SPR_I2S0_BCK | D26 | PIN_I2S0_BCK | 93 | Digital | I/O | 1.8 | － | Hi-Z | － | Hi-Z | － | Hi-Z | CXD5602GG | I2S0 | P1v | GPIO | I2S0_BCK | － | GPIO | 2.5
CN4[L] | 49 | CN4[L] | 49 |  |  | CN4[L] | 49 | CN4[L] | 49 | SPR_UART2_TX | D01 | PIN_UART2_TX | 67 | Digital | I/O | 1.8 | － | Hi-Z | － | Hi-Z | － | Hi-Z | CXD5602GG | UART2 | P1n | GPIO | UART2_TX | － | GPIO | 2.5
CN4[L] | 51 | CN4[L] | 51 |  |  | CN4[L] | 51 | CN4[L] | 51 | SPR_UART2_RX | D00 | PIN_UART2_RX | 68 | Digital | I/O | 1.8 | － | Hi-Z | － | Hi-Z | － | Hi-Z | CXD5602GG | UART2 | P1n | GPIO | UART2_RX | － | GPIO | 2.5
CN4[L] | 53 | CN4[L] | 53 |  |  | CN4[L] | 53 | CN4[L] | 53 | SPR_UART2_RTS | D28 | PIN_UART2_RTS | 70 | Digital | I/O | 1.8 | － | Hi-Z | － | Hi-Z | － | Hi-Z | CXD5602GG | UART2 | P1n | GPIO | UART2_RTS | － | GPIO | 2.5
CN4[L] | 55 | CN4[L] | 55 |  |  | CN4[L] | 55 | CN4[L] | 55 | SPR_UART2_CTS | D27 | PIN_UART2_CTS | 69 | Digital | I/O | 1.8 | － | Hi-Z | － | Hi-Z | － | Hi-Z | CXD5602GG | UART2 | P1n | GPIO | UART2_CTS | － | GPIO | 2.5
CN4[L] | 57 | CN4[L] | 57 |  |  | CN4[L] | 57 | CN4[L] | 57 | SPR_EMMC_CLK | D23 | PIN_EMMC_CLK | 75 | Digital | I/O | 1.8 | － | Hi-Z | － | Hi-Z | － | Hi-Z | CXD5602GG | EMMCＡ | P1p | GPIO | EMMC_CLK | SPI5_SCK | GPIO | 2.5
CN4[L] | 59 | CN4[L] | 59 |  |  | CN4[L] | 59 | CN4[L] | 59 | SPR_EMMC_CMD | D24 | PIN_EMMC_CMD | 76 | Digital | I/O | 1.8 | － | Hi-Z | － | Hi-Z | － | Hi-Z | CXD5602GG | EMMCＡ | P1p | GPIO | EMMC_CMD | SPI5_CS_X | GPIO | 2.5
CN4[L] | 61 | CN4[L] | 61 |  |  | CN4[L] | 61 | CN4[L] | 61 | SPR_EMMC_DATA0 | D16 | PIN_EMMC_DATA0 | 77 | Digital | I/O | 1.8 | － | Hi-Z | － | Hi-Z | － | Hi-Z | CXD5602GG | EMMCＡ | P1p | GPIO | EMMC_DATA0 | SPI5_MOSI | GPIO | 2.5
CN4[L] | 63 | CN4[L] | 63 |  |  | CN4[L] | 63 | CN4[L] | 63 | SPR_EMMC_DATA1 | D17 | PIN_EMMC_DATA1 | 78 | Digital | I/O | 1.8 | － | Hi-Z | － | Hi-Z | － | Hi-Z | CXD5602GG | EMMCＡ | P1p | GPIO | EMMC_DATA1 | SPI5_MISO | GPIO | 2.5
CN4[L] | 65 | CN4[L] | 65 |  |  | CN4[L] | 65 | CN4[L] | 65 | SPR_EMMC_DATA2 | D20 | PIN_EMMC_DATA2 | 79 | Digital | I/O | 1.8 | － | Hi-Z | － | Hi-Z | － | Hi-Z | CXD5602GG | EMMCＢ | P1q | GPIO | EMMC_DATA2 | － | GPIO | 2.5
CN4[L] | 67 | CN4[L] | 67 |  |  | CN4[L] | 67 | CN4[L] | 67 | SPR_EMMC_DATA3 | D21 | PIN_EMMC_DATA3 | 80 | Digital | I/O | 1.8 | － | Hi-Z | － | Hi-Z | － | Hi-Z | CXD5602GG | EMMCＢ | P1q | GPIO | EMMC_DATA3 | － | GPIO | 2.5
CN4[L] | 69 | CN4[L] | 69 |  |  | CN4[L] | 69 | CN4[L] | 69 | GND | － | － | － | Power | － | － | － | － | － | － | － | － | － | － | － | － | － | － | －
CN4[L] | 71 | CN4[L] | 71 |  |  | CN4[L] | 71 | CN4[L] | 71 | SPR_SPI2_SCK | D43 | PIN_SPI2_SCK | 28 | Digital | I/O | 1.8 | － | Hi-Z | － | Hi-Z | － | Hi-Z | CXD5602GG | SPI2A | P00 | GPIO | SPI2_SCK | UART0_RXD | I2C3_BDT | 2.5
CN4[L] | 73 | CN4[L] | 73 |  |  | CN4[L] | 73 | CN4[L] | 73 | SPR_SPI2_MISO | D08 | PIN_SPI2_MISO | 30 | Digital | I/O | 1.8 | － | Hi-Z | － | Hi-Z | － | Hi-Z | CXD5602GG | SPI2B | P01 | GPIO | SPI2_MISO | UART0_RTS | GPIO | 2.5
CN4[L] | 75 | CN4[L] | 75 |  |  | CN4[L] | 75 | CN4[L] | 75 | SPR_SPI2_MOSI | D04 | PIN_SPI2_MOSI | 29 | Digital | I/O | 1.8 | － | Hi-Z | － | Hi-Z | － | Hi-Z | CXD5602GG | SPI2B | P01 | GPIO | SPI2_MOSI | UART0_CTS | GPIO | 2.5
CN4[L] | 77 | CN4[L] | 77 |  |  | CN4[L] | 77 | CN4[L] | 77 | SPR_SPI2_CS_X | D42 | PIN_SPI2_CS_X | 27 | Digital | I/O | 1.8 | － | Hi-Z | － | Hi-Z | － | Hi-Z | CXD5602GG | SPI2A | P00 | GPIO | SPI2_CS_X | UART0_TXD | I2C3_BCK | 2.5
CN4[L] | 79 | CN4[L] | 79 |  |  | CN4[L] | 79 | CN4[L] | 79 | 1.8V | － | － | － | Power | O | 1.8 | O | － | O | － | O | － | － | － | － | － | － | －
CN4[L] | 81 | CN4[L] | 81 |  |  | CN4[L] | 81 | CN4[L] | 81 | SPR_SDIO_CMDDIR | D33 | PIN_SDIO_CMDDIR | 89 | Digital | I/O | 1.8 | － | Hi-Z | － | Hi-Z | O | Hi-Z | CXD5602GG | SDIOC | P1t | GPIO | SDIO_CMDDIR | GPIO | GPIO | 2.5
CN4[L] | 83 | CN4[L] | 83 |  |  | CN4[L] | 83 | CN4[L] | 83 | SPR_SDIO_CLK | D38 | PIN_SDIO_CLK | 81 | Digital | I/O | 1.8 | － | Hi-Z | － | Hi-Z | O | Low | CXD5602GG | SDIOA | P1u | GPIO | SDIO_CLK | SPI5_SCK | GPIO | 2.5
CN4[L] | 85 | CN4[L] | 85 |  |  | CN4[L] | 85 | CN4[L] | 85 | SPR_SDIO_CMD | － | PIN_SDIO_CMD | 82 | Digital | I/O | 1.8 | － | Hi-Z | － | Hi-Z | O | Hi-Z | CXD5602GG | SDIOA | P1r | GPIO | SDIO_CMD | SPI5_CS_X | GPIO | 2.5
CN4[L] | 87 | CN4[L] | 87 |  |  | CN4[L] | 87 | CN4[L] | 87 | SPR_SDIO_DATA0 | － | PIN_SDIO_DATA0 | 83 | Digital | I/O | 1.8 | － | Hi-Z | － | Hi-Z | O | Low | CXD5602GG | SDIOA | P1r | GPIO | SDIO_DATA0 | SPI5_MOSI | GPIO | 2.5
CN4[L] | 89 | CN4[L] | 89 |  |  | CN4[L] | 89 | CN4[L] | 89 | SPR_SDIO_DATA1 | － | PIN_SDIO_DATA1 | 84 | Digital | I/O | 1.8 | － | Hi-Z | － | Hi-Z | O | Low | CXD5602GG | SDIOA | P1r | GPIO | SDIO_DATA1 | SPI5_MISO | GPIO | 2.5
CN4[L] | 91 | CN4[L] | 91 |  |  | CN4[L] | 91 | CN4[L] | 91 | SPR_SDIO_DATA2 | － | PIN_SDIO_DATA2 | 85 | Digital | I/O | 1.8 | － | Hi-Z | － | Hi-Z | O | Low | CXD5602GG | SDIOA | P1r | GPIO | SDIO_DATA2 | GPIO | GPIO | 2.5
CN4[L] | 93 | CN4[L] | 93 |  |  | CN4[L] | 93 | CN4[L] | 93 | SPR_SDIO_DATA3 | － | PIN_SDIO_DATA3 | 86 | Digital | I/O | 1.8 | － | Hi-Z | － | Hi-Z | O | Low | CXD5602GG | SDIOA | P1r | GPIO | SDIO_DATA3 | GPIO | GPIO | 2.5
CN4[L] | 95 | CN4[L] | 95 |  |  | CN4[L] | 95 | CN4[L] | 95 | GND | － | － | － | Power | － | － | － | － | － | － | － | － | － | － | － | － | － | － | －
CN4[L] | 97 | CN4[L] | 97 |  |  | CN4[L] | 97 | CN4[L] | 97 | SPR_SDIO_WP | D37 | PIN_SDIO_WP | 88 | Digital | I/O | 1.8 | － | Hi-Z | － | Hi-Z | － | Hi-Z | CXD5602GG | SDIOB | P1s | GPIO | SDIO_WP | GPIO | GPIO | 2.5
CN4[L] | 99 | CN4[L] | 99 |  |  | CN4[L] | 99 | CN4[L] | 99 | GND | － | － | － | Power | － | － | － | － | － | － | － | － | － | － | － | － | － | － | －
CN4[R] | 2 | CN4[R] | 2 |  |  | CN4[R] | 2 | CN4[R] | 2 | 5V | － | － | － | Power | I/O | 5 | O | － | O | － | O | － | － | － | － | － | － | － | － | 6
CN4[R] | 4 | CN4[R] | 4 |  |  | CN4[R] | 4 | CN4[R] | 4 | 5V | － | － | － | Power | I/O | 5 | O | － | O | － | O | － | － | － | － | － | － | － | － | 6
CN4[R] | 6 | CN4[R] | 6 |  |  | CN4[R] | 6 | CN4[R] | 6 | ACP_SPAP | － | － | － | Analog | O | 3.3 | － | Hi-Z | － | Hi-Z | － | Hi-Z | CXD5247GF | － | － | － | － | － | －
CN4[R] | 8 | CN4[R] | 8 |  |  | CN4[R] | 8 | CN4[R] | 8 | ACP_SPAN | － | － | － | Analog | O | 3.3 | － | Hi-Z | － | Hi-Z | － | Hi-Z | CXD5247GF | － | － | － | － | － | －
CN4[R] | 10 | CN4[R] | 10 |  |  | CN4[R] | 10 | CN4[R] | 10 | ACP_SPBN | － | － | － | Analog | O | 3.3 | － | Hi-Z | － | Hi-Z | － | Hi-Z | CXD5247GF | － | － | － | － | － | －
CN4[R] | 12 | CN4[R] | 12 |  |  | CN4[R] | 12 | CN4[R] | 12 | ACP_SPBP | － | － | － | Analog | O | 3.3 | － | Hi-Z | － | Hi-Z | － | Hi-Z | CXD5247GF | － | － | － | － | － | －
CN4[R] | 14 | CN4[R] | 14 |  |  | CN4[R] | 14 | CN4[R] | 14 | AGND_DRV | － | － | － | Power | － | － | － | － | － | － | － | － | － | － | － | － | － | － | －
CN4[R] | 16 | CN4[R] | 16 |  |  | CN4[R] | 16 | CN4[R] | 16 | SPR_SWDIO | － | － | － | Digital | I/O | 1.8 | － | Hi-Z | － | Hi-Z | － | Hi-Z | CXD5602GG | － | － | － | － | － | － | 2.5
CN4[R] | 18 | CN4[R] | 18 |  |  | CN4[R] | 18 | CN4[R] | 18 | SPR_SWDCLK | － | － | － | Digital | I | 1.8 | I | Hi-Z | I | Hi-Z | I | Hi-Z | CXD5602GG | － | － | － | － | － | － | 2.5
CN4[R] | 20 | CN4[R] | 20 |  |  | CN4[R] | 20 | CN4[R] | 20 | ACP_CLK_DMIC | － | － | － | Digital | O | 1.8 | O | Hi-Z | O | Hi-Z | O | Hi-Z | CXD5247GF | － | － | － | － | － | －
CN4[R] | 22 | CN4[R] | 22 |  |  | CN4[R] | 22 | CN4[R] | 22 | XRS_PWON | － | － | － | Power | I/O | 3.3 | I/O | Low | I/O | Low | I/O | Low | CXD5247GF | － | － | － | － | － | － | 7
CN4[R] | 24 | CN4[R] | 24 |  |  | CN4[R] | 24 | CN4[R] | 24 | SPR_GNSS_1PPS_OUT | D44 | PIN_GNSS_1PPS_OUT | 6 | Digital | I/O | 1.8 | － | Hi-Z | － | Hi-Z | － | Hi-Z | CXD5602GG | GNSS_1PPS_OUT | P14 | GPIO | GNSS_1PPS_OUT | CPU_WDT | CPU_WDT (Open Drain) | 2.5
CN4[R] | 26 | CN4[R] | 26 |  |  | CN4[R] | 26 | CN4[R] | 26 | SPR_SEN_IRQ_IN | D22 | PIN_SEN_IRQ_IN | 37 | Digital | I/O | 1.8 | － | Hi-Z | － | Hi-Z | － | Hi-Z | CXD5602GG | SEN_IRQ_IN | P1e | SEN_IRQ_IN | SEN_IRQ_IN | SEN_IRQ_IN | SEN_IRQ_IN | 2.5
CN4[R] | 28 | CN4[R] | 28 |  |  | CN4[R] | 28 | CN4[R] | 28 | SPR_HIF_IRQ_OUT | D02 | PIN_HIF_IRQ_OUT | 31 | Digital | I/O | 1.8 | － | Hi-Z | － | Hi-Z | － | Hi-Z | CXD5602GG | HIFIRQ | P02 | GPIO | HIF_IRQ_OUT | HIF_IRQ_OUT (Open Drain) | GNSS_1PPS_OUT | 2.5
CN4[R] | 30 | CN4[R] | 30 |  |  | CN4[R] | 30 | CN4[R] | 30 | GND | － | － | － | Power | － | － | － | － | － | － | － | － | － | － | － | － | － | － | －
CN4[R] | 32 | CN4[R] | 32 |  |  | CN4[R] | 32 | CN4[R] | 32 | SPR_RST_X | － | － | － | Digital | O | 1.8 | － | Low | O | High | O | High | CXD5602GG | － | － | － | － | － | －
CN4[R] | 34 | CN4[R] | 34 |  |  | CN4[R] | 34 | CN4[R] | 34 | SPR_AP_CLK | D40 | PIN_AP_CLK | 5 | Digital | I/O | 1.8 | － | Hi-Z | － | Hi-Z | － | Hi-Z | CXD5602GG | AP_CLK | P13 | GPIO | AP_CLK | PMU_WDT | PMU_WDT (Open Drain) | 2.5
CN4[R] | 36 | CN4[R] | 36 |  |  | CN4[R] | 36 | CN4[R] | 36 | SPR_SEN_AIN2 | A0 | LPADC0 | － | Analog | I | 0.7 | I | － | I | － | I | － | CXD5602GG | － | － | － | － | － | － | 1.05
CN4[R] | 38 | CN4[R] | 38 |  |  | CN4[R] | 38 | CN4[R] | 38 | SPR_SEN_AIN3 | A1 | LPADC1 | － | Analog | I | 0.7 | I | － | I | － | I | － | CXD5602GG | － | － | － | － | － | － | 1.05
CN4[R] | 40 | CN4[R] | 40 |  |  | CN4[R] | 40 | CN4[R] | 40 | SPR_SEN_AIN4 | A2 | LPADC2 | － | Analog | I | 0.7 | I | － | I | － | I | － | CXD5602GG | － | － | － | － | － | － | 1.05
CN4[R] | 42 | CN4[R] | 42 |  |  | CN4[R] | 42 | CN4[R] | 42 | SPR_SEN_AIN5 | A3 | LPADC3 | － | Analog | I | 0.7 | I | － | I | － | I | － | CXD5602GG | － | － | － | － | － | － | 1.05
CN4[R] | 44 | CN4[R] | 44 |  |  | CN4[R] | 44 | CN4[R] | 44 | SPR_SEN_AIN0 | A4 | HPADC0 | － | Analog | I | 1.4 | I | － | I | － | I | － | CXD5602GG | － | － | － | － | － | － | 2.5
CN4[R] | 46 | CN4[R] | 46 |  |  | CN4[R] | 46 | CN4[R] | 46 | SPR_SEN_AIN1 | A5 | HPADC1 | － | Analog | I | 1.4 | I | － | I | － | I | － | CXD5602GG | － | － | － | － | － | － | 2.5
CN4[R] | 48 | CN4[R] | 48 |  |  | CN4[R] | 48 | CN4[R] | 48 | GND | － | － | － | Power | － | － | － | － | － | － | － | － | － | － | － | － | － | － | －
CN4[R] | 50 | CN4[R] | 50 |  |  | CN4[R] | 50 | CN4[R] | 50 | SPR_SPI3_CS1_X | D07 | PIN_SPI3_CS1_X | 39 | Digital | I/O | 1.8 | － | Hi-Z | － | Hi-Z | － | Hi-Z | CXD5602GG | SPI3_CS1_X | P1g | GPIO | SPI3_CS1_X | － | － | 2.5
CN4[R] | 52 | CN4[R] | 52 |  |  | CN4[R] | 52 | CN4[R] | 52 | SPR_SPI3_MOSI | D31 | PIN_SPI3_MOSI | 42 | Digital | I/O | 1.8 | － | Hi-Z | － | Hi-Z | － | Hi-Z | CXD5602GG | SPI3 | P1i | GPIO | SPI3_MOSI | － | － | 2.5
CN4[R] | 54 | CN4[R] | 54 |  |  | CN4[R] | 54 | CN4[R] | 54 | SPR_SPI3_SCK | D29 | PIN_SPI3_SCK | 41 | Digital | I/O | 1.8 | － | Hi-Z | － | Hi-Z | － | Hi-Z | CXD5602GG | SPI3 | P1i | GPIO | SPI3_SCK | － | － | 2.5
CN4[R] | 56 | CN4[R] | 56 |  |  | CN4[R] | 56 | CN4[R] | 56 | SPR_SPI3_MISO | D30 | PIN_SPI3_MISO | 43 | Digital | I/O | 1.8 | － | Hi-Z | － | Hi-Z | － | Hi-Z | CXD5602GG | SPI3 | P1i | GPIO | SPI3_MISO | － | － | 2.5
CN4[R] | 58 | CN4[R] | 58 |  |  | CN4[R] | 58 | CN4[R] | 58 | SPR_SPI3_CS0_X | D32 | PIN_SPI3_CS0_X | 38 | Digital | I/O | 1.8 | － | Hi-Z | － | Hi-Z | － | Hi-Z | CXD5602GG | SPI3_CS0_X | P1f | GPIO | SPI3_CS0_X | － | － | 2.5
CN4[R] | 60 | CN4[R] | 60 |  |  | CN4[R] | 60 | CN4[R] | 60 | SPR_RTC_IRQ_OUT | D41 | PIN_RTC_IRQ_OUT | 4 | Digital | I/O | 1.8 | － | Hi-Z | － | Hi-Z | － | Hi-Z | CXD5602GG | RTC_IRQ_OUT | P12 | GPIO | RTC_IRQ_OUT | RTC_IRQ_OUT (Open Drain) | GPIO | 2.5
CN4[R] | 62 | CN4[R] | 62 |  |  | CN4[R] | 62 | CN4[R] | 62 | SPR_USB_DM | － | － | － | Analog | I/O | 3.3 | － | － | － | － | － | － | CXD5602GG | － | － | － | － | － | － | 5.25
CN4[R] | 64 | CN4[R] | 64 |  |  | CN4[R] | 64 | CN4[R] | 64 | SPR_USB_DP | － | － | － | Analog | I/O | 3.3 | － | － | － | － | － | － | CXD5602GG | － | － | － | － | － | － | 5.25
CN4[R] | 66 | CN4[R] | 66 |  |  | CN4[R] | 66 | CN4[R] | 66 | SPR_GPS_EXTLD | D39 | PIN_HIF_GPIO0 | 32 | Digital | I/O | 1.8 | － | Hi-Z | － | Hi-Z | － | Hi-Z | CXD5602GG | HIF_GPIO0 | P03 | GPIO | GPIO | GPIO | GPS_EXTLD | 2.5
CN4[R] | 68 | CN4[R] | 68 |  |  | CN4[R] | 68 | CN4[R] | 68 | GND | － | － | － | Power | － | － | － | － | － | － | － | － | － | － | － | － | － | － | －
CN4[R] | 70 | CN4[R] | 70 |  |  | CN4[R] | 70 | CN4[R] | 70 | ACP_GPO5 | － | － | － | Digital | O | 3.6-4.4 | O | Hi-Z | O | Low | O | Low | CXD5247GF | － | － | － | － | － | －
CN4[R] | 72 | CN4[R] | 72 |  |  | CN4[R] | 72 | CN4[R] | 72 | ACP_GPO6 | － | － | － | Digital | O | 3.6-4.4 | O | Hi-Z | O | Low | O | Low | CXD5247GF | － | － | － | － | － | － |  | ヘッドフォンミュート | Lowでミュート
CN4[R] | 74 | CN4[R] | 74 |  |  | CN4[R] | 74 | CN4[R] | 74 | ACP_GPO7 | － | － | － | Digital | O | 3.6-4.4 | O | Hi-Z | O | Low | O | Low | CXD5247GF | － | － | － | － | － | －
CN4[R] | 76 | CN4[R] | 76 |  |  | CN4[R] | 76 | CN4[R] | 76 | ACP_VSYS | － | － | － | Power | I/O | 3.6-4.4 | I/O | － | I/O | － | I/O | － | － | － | － | － | － | － | － | 7
CN4[R] | 78 | CN4[R] | 78 |  |  | CN4[R] | 78 | CN4[R] | 78 | ACP_VSYS | － | － | － | Power | I/O | 3.6-4.4 | I/O | － | I/O | － | I/O | － | － | － | － | － | － | － | － | 7
CN4[R] | 80 | CN4[R] | 80 |  |  | CN4[R] | 80 | CN4[R] | 80 | GND | － | － | － | Power | － | － | － | － | － | － | － | － | － | － | － | － | － | － | －
CN4[R] | 82 | CN4[R] | 82 |  |  | CN4[R] | 82 | CN4[R] | 82 | SPR_SDIO_CD | D36 | PIN_SDIO_CD | 87 | Digital | I/O | 1.8 | － | Hi-Z | － | Hi-Z | I | High | CXD5602GG | SDIOB | P1s | GPIO | SDIO_CD | GPIO | GPIO | 2.5
CN4[R] | 84 | CN4[R] | 84 |  |  | CN4[R] | 84 | CN4[R] | 84 | SPR_I2C2_SDA | － | PIN_SPI0_MISO | 20 | Digital | I/O | 1.8 | － | High | － | High | I | High | CXD5602GG | SPI0B | P17 | GPIO | I2C2_BDT | SPI0_MISO | － | 2.5
CN4[R] | 86 | CN4[R] | 86 |  |  | CN4[R] | 86 | CN4[R] | 86 | SPR_I2C2_SCL | － | PIN_SPI0_MOSI | 19 | Digital | I/O | 1.8 | － | High | I/O | － | I | High | CXD5602GG | SPI0B | P17 | GPIO | I2C2_BCK | SPI0_MOSI | － | 2.5
CN4[R] | 88 | CN4[R] | 88 |  |  | CN4[R] | 88 | CN4[R] | 88 | ACP_GPO0 | － | － | － | Digital | O | 3.6-4.4 | O | Hi-Z | O | Hi-Z | O | Hi-Z | CXD5247GF | － | － | － | － | － | －
CN4[R] | 90 | CN4[R] | 90 |  |  | CN4[R] | 90 | CN4[R] | 90 | ACP_GPO1 | － | － | － | Digital | O | 3.6-4.4 | O | Hi-Z | O | Low | O | Low | CXD5247GF | － | － | － | － | － | － |  | オーディオ3.3V出力 | Highで出力
CN4[R] | 92 | CN4[R] | 92 |  |  | CN4[R] | 92 | CN4[R] | 92 | ACP_GPO2 | － | － | － | Digital | O | 3.6-4.4 | O | Hi-Z | O | Low | O | Low | CXD5247GF | － | － | － | － | － | － |  | LTE用電源出力 （LTE拡張ボードのみ） | Highで出力
CN4[R] | 94 | CN4[R] | 94 |  |  | CN4[R] | 94 | CN4[R] | 94 | ACP_GPO3 | － | － | － | Digital | O | 3.6-4.4 | O | Hi-Z | O | Low | O | Low | CXD5247GF | － | － | － | － | － | － |  | メインボード側からのLTE用電源出力 （LTE拡張ボードのみ） | Highで出力
CN4[R] | 96 | CN4[R] | 96 |  |  | CN4[R] | 96 | CN4[R] | 96 | SWOCLK | － | － | － | Digital | O | 1.8 | － | Hi-Z | － | Hi-Z | － | Hi-Z | CXD5602GG | － | － | － | － | － | － | 2.5
CN4[R] | 98 | CN4[R] | 98 |  |  | CN4[R] | 98 | CN4[R] | 98 | SWO | － | － | － | Digital | O | 1.8 | － | Hi-Z | － | Hi-Z | － | Hi-Z | CXD5602GG | － | － | － | － | － | － | 2.5
CN4[R] | 100 | CN4[R] | 100 |  |  | CN4[R] | 100 | CN4[R] | 100 | GND | － | － | － | Power | － | － | － | － | － | － | － | － | － | － | － | － | － | － | －
D7 |  |  |  |  |  |  |  |  |  | SPR_I2S1_BCK | LED0 | PIN_I2S1_BCK | 97 | Digital | I/O | 1.8 | － | Hi-Z | － | Hi-Z | － | Hi-Z | CXD5602GG | I2S1 | P1w | GPIO | I2S1_BCK | － | GPIO | 2.5
D6 |  |  |  |  |  |  |  |  |  | SPR_I2S1_LRCK | LED1 | PIN_I2S1_LRCK | 98 | Digital | I/O | 1.8 | － | Hi-Z | － | Hi-Z | － | Hi-Z | CXD5602GG | I2S1 | P1w | GPIO | I2S1_LRCK | － | GPIO | 2.5
D5 |  |  |  |  |  |  |  |  |  | SPR_I2S1_DATA_IN | LED2 | PIN_I2S1_DATA_IN | 99 | Digital | I/O | 1.8 | － | Hi-Z | － | Hi-Z | － | Hi-Z | CXD5602GG | I2S1 | P1w | GPIO | I2S1_DATA_IN | － | GPIO | 2.5
D4 |  |  |  |  |  |  |  |  |  | SPR_I2S1_DATA_OUT | LED3 | PIN_I2S1_DATA_OUT | 100 | Digital | I/O | 1.8 | － | Hi-Z | － | Hi-Z | － | Hi-Z | CXD5602GG | I2S1 | P1w | GPIO | I2S1_DATA_OUT | － | GPIO | 2.5
 |  | JP3 | 1 |  |  |  |  |  |  | NC | － | － | － | － | － | － | － | － | － | － | － | － | － | － | － | － | － | － | －
 |  | JP3 | 2 |  |  |  |  |  |  | VDD_LVS | － | － | － | Power | O | 5/3.3 | O | － | O | － | O | － | － | － | － | － | － | － | －
 |  | JP3 | 3 |  |  |  |  |  |  | XRS_PWON | － | － | － | Digital | I/O | 3.3 | I/O | － | I/O | － | I/O | － | － | － | － | － | － | － | － | 7
 |  | JP3 | 4 |  |  | CN9 | 5 | CN9 | 5 | 3.3V | － | － | － | Power | O | 3.3 | O | － | O | － | O | － | － | － | － | － | － | － | －
 |  | JP3 | 5 |  |  | CN9 | 1 | CN9 | 1 | MAIN_POWER | － | － | － | Power | I/O | 5 | I/O | － | I/O | － | I/O | － | － | － | － | － | － | － | － | 6
 |  | JP3 | 6 |  |  | CN9 | 2 | CN9 | 2 | GND | － | － | － | Power | － | － | － | － | － | － | － | － | － | － | － | － | － | － | －
 |  | JP3 | 7 |  |  | CN9 | 6 | CN9 | 6 | GND | － | － | － | Power | － | － | － | － | － | － | － | － | － | － | － | － | － | － | －
 |  | JP3 | 8 |  |  |  |  |  |  | 5V_IN_PIN | － | － | － | － | － | － | － | － | － | － | － | － | － | － | － | － | － | － | －
 |  | JP4 | 1 |  |  |  |  |  |  | SPR_SEN_AIN2 | A0 | LPADC0 | － | Analog | I | ～5 | I | － | I | － | I | － | CXD5602GG | － | － | SEN_AIN2 | SEN_AIN2 | SEN_AIN2 | SEN_AIN2 | 7.5
 |  | JP4 | 2 |  |  |  |  | CN6 | 2 | SPR_SEN_AIN3 | A1 | LPADC1 | － | Analog | I | ～5 | I | － | I | － | I | － | CXD5602GG | － | － | SEN_AIN3 | SEN_AIN3 | SEN_AIN3 | SEN_AIN3 | 7.5
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

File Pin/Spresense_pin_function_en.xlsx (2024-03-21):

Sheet: Pin List
Ref |  |  |  | Pin No. | Name on schematic | Name on ArduinoIDE | Name on SDK | Pin No. on SDK ピン番号 | Type | dir | Voltage | After turning on the power |  | After starting Arduino |  | After starting SDK |  | Connection | Pin group |  | CXD5602GG pin function |  |  |  | Maximum absolute rating Voltage(V) | Features on the extension board | explanation
Main | Ext | Cam | LTE |  |  |  |  |  |  |  |  | dir | Init val | dir | init val | dir | init val |  | Mode name | doc. | mode0 | mode1 | mode2 | mode3
JP1 |  |  |  | 1 | GND | － | － | － | Power | － | － | － | － | － | － | － | － | － | － | － | － | － | － | －
JP1 |  |  |  | 2 | UART2_TX | D01 | PIN_UART2_TXD | 67 | Digital | I/O | 1.8 | － | Hi-Z | － | Hi-Z | － | Hi-Z | CXD5602GG | UART2 | P1n | GPIO | UART2_TXD | － | GPIO | 2.5
JP1 |  |  |  | 3 | UART2_RX | D00 | PIN_UART2_RXD | 68 | Digital | I/O | 1.8 | － | Hi-Z | － | Hi-Z | － | Hi-Z | CXD5602GG | UART2 | P1n | GPIO | UART2_RXD | － | GPIO | 2.5
JP1 |  |  |  | 4 | UART2_RTS | D28 | PIN_UART2_RTS | 70 | Digital | I/O | 1.8 | － | Hi-Z | － | Hi-Z | － | Hi-Z | CXD5602GG | UART2 | P1n | GPIO | UART2_RTS | － | GPIO | 2.5
JP1 |  |  |  | 5 | UART2_CTS | D27 | PIN_UART2_CTS | 69 | Digital | I/O | 1.8 | － | Hi-Z | － | Hi-Z | － | Hi-Z | CXD5602GG | UART2 | P1n | GPIO | UART2_CTS | － | GPIO | 2.5
JP1 |  |  |  | 6 | I2S0_BCK | D26 | PIN_I2S0_BCK | 93 | Digital | I/O | 1.8 | － | Hi-Z | － | Hi-Z | － | Hi-Z | CXD5602GG | I2S0 | P1v | GPIO | I2S0_BCK | － | GPIO | 2.5
JP1 |  |  |  | 7 | I2S0_LRCK | D25 | PIN_I2S0_LRCK | 94 | Digital | I/O | 1.8 | － | Hi-Z | － | Hi-Z | － | Hi-Z | CXD5602GG | I2S0 | P1v | GPIO | I2S0_LRCK | － | GPIO | 2.5
JP1 |  |  |  | 8 | SPI5_CS_X | D24 | PIN_SPI5_CS_X | 76 | Digital | I/O | 1.8 | － | Hi-Z | － | Hi-Z | － | Hi-Z | CXD5602GG | EMMCA | P1p | GPIO | EMMC_CMD | SPI5_CS_X | GPIO | 2.5
JP1 |  |  |  | 9 | SPI5_SCK | D23 | PIN_SPI5_SCK | 75 | Digital | I/O | 1.8 | － | Hi-Z | － | Hi-Z | － | Hi-Z | CXD5602GG | EMMCA | P1p | GPIO | EMMC_CLK | SPI5_SCK | GPIO | 2.5
JP1 |  |  |  | 10 | 3.3V | － | － | － | Power | O | 3.3 | O | － | O | － | O | － | － | － | － | － | － | － | －
JP1 |  |  |  | 11 | 1.8V | － | － | － | Power | O | 1.8 | O | － | O | － | O | － | － | － | － | － | － | － | －
JP1 |  |  |  | 12 | SEN_IRQ | D22 | PIN_SEN_IRQ_IN | 37 | Digital | I/O | 1.8 | － | Hi-Z | － | Hi-Z | － | Hi-Z | CXD5602GG | SEN_IRQ_IN | P1e | GPIO | SEN_IRQ_IN | － | － | 2.5
JP1 |  |  |  | 13 | SEN_AIN4 | A2 | LPADC2 | － | Analog | I | ～0.7 | I | － | I | － | I | － | CXD5602GG |  | － | － | － | － | － | 1.05
JP2 |  |  |  | 1 | XRST | － | (SPR_RST_X) | － | Digital | O | 1.8 | － | Low | O | High | O | High | CXD5602GG | － | － | － | － | － | －
JP2 |  |  |  | 2 | 1.8V | － | － | － | Power | O | 1.8 | O | － | O | － | O | － | － | － | － | － | － | － | －
JP2 |  |  |  | 3 | 3.7V(4.0V) | － | － | － | Power | I/O | 3.6-4.4 | O | － | O | － | O | － | － | － | － | － | － | － | － | 7
JP2 |  |  |  | 4 | GPIO | D21 | PIN_EMMC_DATA3 | 80 | Digital | I/O | 1.8 | － | Hi-Z | － | Hi-Z | － | Hi-Z | CXD5602GG | EMMCB | P1q | GPIO | EMMC_DATA3 | － | GPIO | 2.5
JP2 |  |  |  | 5 | GPIO | D20 | PIN_EMMC_DATA2 | 79 | Digital | I/O | 1.8 | － | Hi-Z | － | Hi-Z | － | Hi-Z | CXD5602GG | EMMCB | P1q | GPIO | EMMC_DATA2 | － | GPIO | 2.5
JP2 |  |  |  | 6 | I2S0_DATA_IN | D19 | PIN_I2S0_DATA_IN | 95 | Digital | I/O | 1.8 | － | Hi-Z | － | Hi-Z | － | Hi-Z | CXD5602GG | I2S0 | P1v | GPIO | I2S0_DATA_IN | － | GPIO | 2.5
JP2 |  |  |  | 7 | I2S0_DATA_OUT | D18 | PIN_I2S0_DATA_OUT | 96 | Digital | I/O | 1.8 | － | Hi-Z | － | Hi-Z | － | Hi-Z | CXD5602GG | I2S0 | P1v | GPIO | I2S0_DATA_OUT | － | GPIO | 2.5
JP2 |  |  |  | 8 | SPR_SPI5_MISO | D17 | PIN_SPI5_MISO | 78 | Digital | I/O | 1.8 | － | Hi-Z | － | Hi-Z | － | Hi-Z | CXD5602GG | EMMCA | P1p | GPIO | EMMC_DATA1 | SPI5_MISO | GPIO | 2.5
JP2 |  |  |  | 9 | SPR_SPI5_MOSI | D16 | PIN_SPI5_MOSI | 77 | Digital | I/O | 1.8 | － | Hi-Z | － | Hi-Z | － | Hi-Z | CXD5602GG | EMMCA | P1p | GPIO | EMMC_DATA0 | SPI5_MOSI | GPIO | 2.5
JP2 |  |  |  | 10 | GND | － | － | － | Power | － | － | － | － | － | － | － | － | － | － | － | － | － | － | －
JP2 |  |  |  | 11 | I2C0_SCL | D15 | PIN_I2C0_BCK | 44 | Digital | I/O | 1.8 | － | High | I | High | I | High | CXD5602GG | I2C0 | P1j | GPIO | I2C0_BCK | － | － | 2.5
JP2 |  |  |  | 12 | I2C0_SDA | D14 | PIN_I2C0_BDT | 45 | Digital | I/O | 1.8 | － | High | I | High | I | High | CXD5602GG | I2C0 | P1j | GPIO | I2C0_BDT | － | － | 2.5
JP2 |  |  |  | 13 | SEN_AIN5 | A3 | LPADC3 | － | Analog | I | ～0.7 | I | － | I | － | I | － | CXD5602GG | － | － | － | － | － | － | 1.05
CN5 |  | CN1 |  | 1 | MCLK | － | － | － | Digital | O | 1.8 | － | － | O | Hi-Z | O | Hi-Z | 26MHz TCXO | － | － | － | － | － | － | 2.5
CN5 |  | CN1 |  | 2 | GND | － | － | － | Power | － | － | － | － | － | － | － | － | － | － | － | － | － | － | －
CN5 |  | CN1 |  | 3 | I2C_SDA | － | PIN_SPI0_MISO | 20 | Digital | I/O | 1.8 | － | High | － | High | I | High | CXD5602GG | I2C2 | P17 | GPIO | I2C2_BDT | SPI0_MISO | GPIO | 2.5
CN5 |  | CN1 |  | 4 | I2C_SCL | － | PIN_SPI0_MOSI | 19 | Digital | I/O | 1.8 | － | High | － | High | I | High | CXD5602GG | I2C2 | P17 | GPIO | I2C2_BCK | SPI0_MOSI | GPIO | 2.5
CN5 |  | CN1 |  | 5 | XRS | D35 | PIN_SDIO_DIR1_3 | 91 | Digital | I/O | 1.8 | － | Hi-Z | － | Hi-Z | － | Hi-Z | CXD5602GG | SDIOC | P1t | GPIO | SDIO_DIR1_3 | GPIO | GPIO | 2.5
CN5 |  | CN1 |  | 6 | PWDN | D34 | PIN_SDIO_DIR0 | 90 | Digital | I/O | 1.8 | － | Hi-Z | － | Hi-Z | － | Hi-Z | CXD5602GG | SDIOC | P1t | GPIO | SDIO_DIR0 | GPIO | GPIO | 2.5
CN5 |  | CN1 |  | 7 | LDO_EN | － | (ACP_GPO4) | － | Digital | O | 3.6-4.4 | O | Hi-Z | O | Low | O | Low | CXD5247GF | － | － | － | － | － | －
CN5 |  | CN1 |  | 8 | VDD_3.7V | － | － | － | Power | O | 3.6-4.4 | O | － | O | － | O | － | － | － | － | － | － | － | －
CN5 |  | CN1 |  | 9 | IS_DATA4 | － | PIN_IS_DATA4 | 63 | Digital | I/O | 1.8 | － | Hi-Z | － | Hi-Z | I | － | CXD5602GG | IS | P1m | GPIO | IS_DATA4 | GPIO | GPIO | 2.5
CN5 |  | CN1 |  | 10 | IS_DATA6 | － | PIN_IS_DATA6 | 65 | Digital | I/O | 1.8 | － | Hi-Z | － | Hi-Z | I | － | CXD5602GG | IS | P1m | GPIO | IS_DATA6 | GPIO | GPIO | 2.5
CN5 |  | CN1 |  | 11 | IS_DATA0 | － | PIN_IS_DATA0 | 59 | Digital | I/O | 1.8 | － | Hi-Z | － | Hi-Z | I | － | CXD5602GG | IS | P1m | GPIO | IS_DATA0 | GPIO | GPIO | 2.5
CN5 |  | CN1 |  | 12 | IS_DATA7 | － | PIN_IS_DATA7 | 66 | Digital | I/O | 1.8 | － | Hi-Z | － | Hi-Z | I | － | CXD5602GG | IS | P1m | GPIO | IS_DATA7 | GPIO | GPIO | 2.5
CN5 |  | CN1 |  | 13 | IS_DATA5 | － | PIN_IS_DATA5 | 64 | Digital | I/O | 1.8 | － | Hi-Z | － | Hi-Z | I | － | CXD5602GG | IS | P1m | GPIO | IS_DATA5 | GPIO | GPIO | 2.5
CN5 |  | CN1 |  | 14 | IS_DATA2 | － | PIN_IS_DATA2 | 61 | Digital | I/O | 1.8 | － | Hi-Z | － | Hi-Z | I | － | CXD5602GG | IS | P1m | GPIO | IS_DATA2 | GPIO | GPIO | 2.5
CN5 |  | CN1 |  | 15 | IS_HSYNC | － | PIN_IS_HSYNC | 58 | Digital | I/O | 1.8 | － | Hi-Z | － | Hi-Z | I | － | CXD5602GG | IS | P1m | GPIO | IS_HSYNC | GPIO | GPIO | 2.5
CN5 |  | CN1 |  | 16 | IS_DATA3 | － | PIN_IS_DATA3 | 62 | Digital | I/O | 1.8 | － | Hi-Z | － | Hi-Z | I | － | CXD5602GG | IS | P1m | GPIO | IS_DATA3 | GPIO | GPIO | 2.5
CN5 |  | CN1 |  | 17 | IS_VSYNC | － | PIN_IS_VSYNC | 57 | Digital | I/O | 1.8 | － | Hi-Z | － | Hi-Z | I | － | CXD5602GG | IS | P1m | GPIO | IS_VSYNC | GPIO | GPIO | 2.5
CN5 |  | CN1 |  | 18 | IS_DATA1 | － | PIN_IS_DATA1 | 60 | Digital | I/O | 1.8 | － | Hi-Z | － | Hi-Z | I | － | CXD5602GG | IS | P1m | GPIO | IS_DATA1 | GPIO | GPIO | 2.5
CN5 |  | CN1 |  | 19 | GND | － | － | － | Power | － | － | － | － | － | － | － | － | － | － | － | － | － | － | －
CN5 |  | CN1 |  | 20 | IS_CLK | － | PIN_IS_CLK | 56 | Digital | I | 1.8 | I | － | I | － | I | － | CXD5602GG | IS | P1m | GPIO | IS_CLK | GPIO | GPIO | 2.5
CN4[L] | CN4[L] |  | CN4[L] | 1 | 3.3V_AU | － | － | － | Power | O | 3.3 | I | － | I | － | I | － | － | － | － | － | － | － | －
CN4[L] | CN4[L] |  | CN4[L] | 3 | 3.3V_AU | － | － | － | Power | O | 3.3 | I | － | I | － | I | － | － | － | － | － | － | － | －
CN4[L] | CN4[L] |  | CN4[L] | 5 | ACP_MICA | － | － | － | Analog | I | － | I | － | I | － | I | － | CXD5247GF | － | － | － | － | － | －
CN4[L] | CN4[L] |  | CN4[L] | 7 | ACP_MICB | － | － | － | Analog | I | － | I | － | I | － | I | － | CXD5247GF | － | － | － | － | － | －
CN4[L] | CN4[L] |  | CN4[L] | 9 | ACP_MICC | － | － | － | Analog | I | － | I | － | I | － | I | － | CXD5247GF | － | － | － | － | － | －
CN4[L] | CN4[L] |  | CN4[L] | 11 | ACP_MICD | － | － | － | Analog | I | － | I | － | I | － | I | － | CXD5247GF | － | － | － | － | － | －
CN4[L] | CN4[L] |  | CN4[L] | 13 | ACP_MICBIASA | － | － | － | Analog | O | 2 | O | － | O | － | O | － | CXD5247GF | － | － | － | － | － | －
CN4[L] | CN4[L] |  | CN4[L] | 15 | ACP_MICBIASB | － | － | － | Analog | O | 2 | O | － | O | － | O | － | CXD5247GF | － | － | － | － | － | －
CN4[L] | CN4[L] |  | CN4[L] | 17 | AGND_MIC | － | － | － | Power | － | － | － | － | － | － | － | － | － | － | － | － | － | － | －
CN4[L] | CN4[L] |  | CN4[L] | 19 | SPR_I2C0_SCL | D15 | PIN_I2C0_BCK | 44 | Digital | I/O | 1.8 | － | High | I | High | I | High | CXD5602GG | I2C0 | P1j | GPIO | I2C0_BCK | － | － | 2.5
CN4[L] | CN4[L] |  | CN4[L] | 21 | SPR_I2C0_SDA | D14 | PIN_I2C0_BDT | 45 | Digital | I/O | 1.8 | － | High | I | High | I | High | CXD5602GG | I2C0 | P1j | GPIO | I2C0_BDT | － | － | 2.5
CN4[L] | CN4[L] |  | CN4[L] | 23 | SPR_SPI4_SCK | D13 | PIN_SPI4_SCK | 72 | Digital | I/O | 1.8 | － | Hi-Z | － | Hi-Z | － | Hi-Z | CXD5602GG | SPI4 | P1o | GPIO | SPI4_SCK | － | GPIO | 2.5
CN4[L] | CN4[L] |  | CN4[L] | 25 | SPR_SPI4_MISO | D12 | PIN_SPI4_MISO | 74 | Digital | I/O | 1.8 | － | Hi-Z | － | Hi-Z | － | Hi-Z | CXD5602GG | SPI4 | P1o | GPIO | SPI4_MISO | － | GPIO | 2.5
CN4[L] | CN4[L] |  | CN4[L] | 27 | SPR_SPI4_MOSI | D11 | PIN_SPI4_MOSI | 73 | Digital | I/O | 1.8 | － | Hi-Z | － | Hi-Z | － | Hi-Z | CXD5602GG | SPI4 | P1o | GPIO | SPI4_MOSI | － | GPIO | 2.5
CN4[L] | CN4[L] |  | CN4[L] | 29 | SPR_SPI4_CS_X | D10 | PIN_SPI4_CS_X | 71 | Digital | I/O | 1.8 | － | Hi-Z | － | Hi-Z | － | Hi-Z | CXD5602GG | SPI4 | P1o | GPIO | SPI4_CS_X | － | GPIO | 2.5
CN4[L] | CN4[L] |  | CN4[L] | 31 | SPR_PWM2 | D09 | PIN_PWM2 | 48 | Digital | I/O | 1.8 | － | Hi-Z | － | Hi-Z | － | Hi-Z | CXD5602GG | PWMB | P1l | GPIO | PWM2 | I2C1_BCK | － | 2.5
CN4[L] | CN4[L] |  | CN4[L] | 33 | SPR_I2S0_LRCK | D25 | PIN_I2S0_LRCK | 94 | Digital | I/O | 1.8 | － | Hi-Z | － | Hi-Z | － | Hi-Z | CXD5602GG | I2S0 | P1v | GPIO | I2S0_LRCK | － | GPIO | 2.5
CN4[L] | CN4[L] |  | CN4[L] | 35 | GND | － | － | － | Power | － | － | － | － | － | － | － | － | － | － | － | － | － | － | －
CN4[L] | CN4[L] |  | CN4[L] | 37 | SPR_I2S0_DATA_OUT | D18 | PIN_I2S0_DATA_OUT | 96 | Digital | I/O | 1.8 | － | Hi-Z | － | Hi-Z | － | Hi-Z | CXD5602GG | I2S0 | P1v | GPIO | I2S0_DATA_OUT | － | GPIO | 2.5
CN4[L] | CN4[L] |  | CN4[L] | 39 | SPR_PWM0 | D06 | PIN_PWM0 | 46 | Digital | I/O | 1.8 | － | Hi-Z | － | Hi-Z | － | Hi-Z | CXD5602GG | PWMA | P1k | GPIO | PWM0 | － | － | 2.5
CN4[L] | CN4[L] |  | CN4[L] | 41 | SPR_PWM1 | D05 | PIN_PWM1 | 47 | Digital | I/O | 1.8 | － | Hi-Z | － | Hi-Z | － | Hi-Z | CXD5602GG | PWMA | P1k | GPIO | PWM1 | GPIO | － | 2.5
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

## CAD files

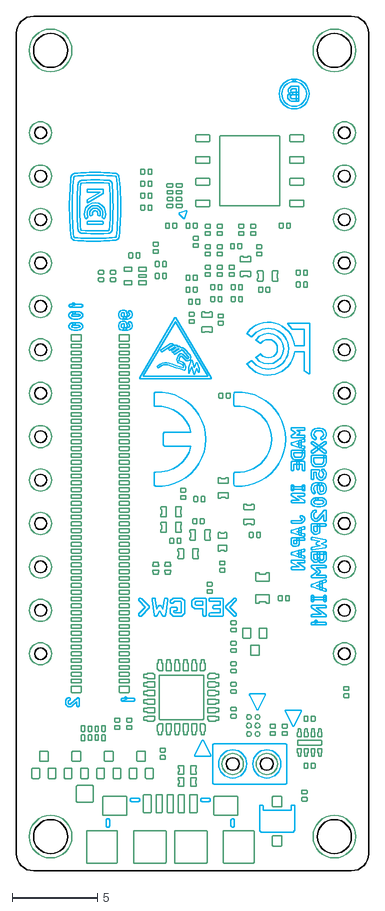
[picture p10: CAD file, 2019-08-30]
CXD5602PWBMAIN1/dxf/CXD5602PWBMAIN1_side_b.dxf
20.6 x 50.0

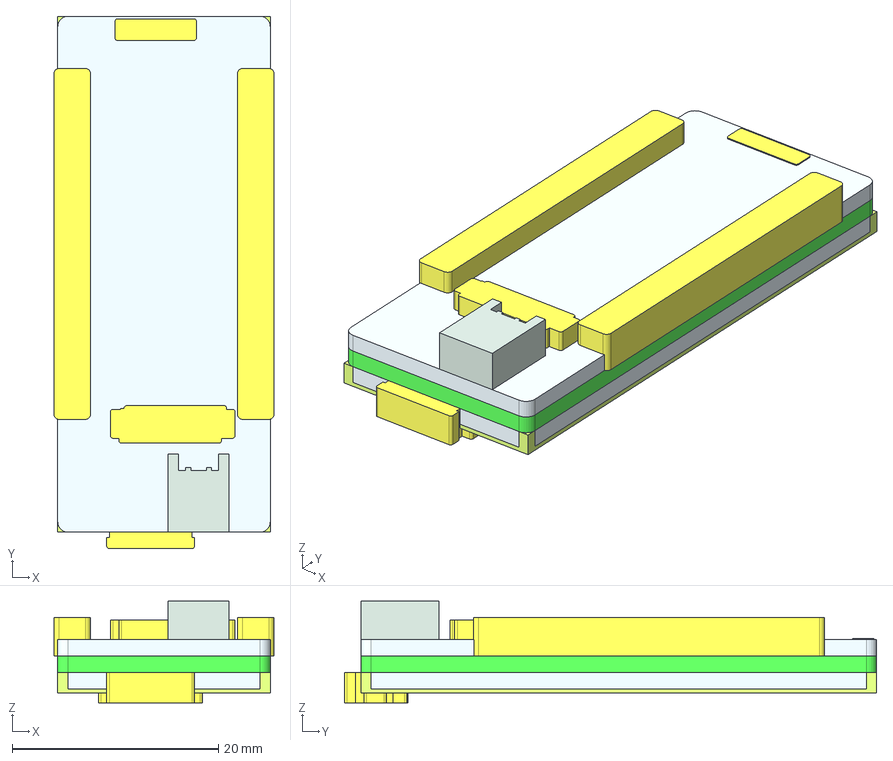
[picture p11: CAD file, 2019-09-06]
CXD5602PWBMAIN1/stp/CXD5602PWBMAIN1.stp
21.3 x 51.6 x 9.85 mm
111802811-std_001 x 7
112094111-std_001 x 31
111817311-std_001 x 13
111877711-std_001 x 5
112049111-std_001 x 8
148275521-std_001
112097911-std_001 x 2
111839511-std_001 x 4
111816811-std_001 x 12
181495811-std_001
111874311-std_001
111220091-std_001 x 2
111875311-std_001
111840311-std_001
111878111-std_001
650425601-std_001
650400201-std_001
650232501-pstd_001 x 4
179858621-std_001
179858311-std_001
148184421-std_001 x 5
148278211-std_001 x 2
148189411-std_001
148188911-std_001
140012521-std_001
148188711-std_001
124620211-std_001
140011721-std_001
140011921-std_001
672260201-std_001
672291901-std_001
672166001-std_001
124070391-std_001 x 8
121899081-std_001 x 7
169453591-std_001 x 9
124067691-std_001 x 2
124072691-std_001
125072911-std_001 x 4
124831111-std_001
124071891-std_001 x 3
124069991-std_001 x 2
124070991-std_001
655270001-std_001
655296201-std_001 x 4
124071091-std_001
124071491-std_001
124072291-std_001 x 3
124070791-std_001
125724811-std_001
124067991-std_001
124069591-std_001
156471811-std_001
182273321-std_001
184288111-std_001
184361711-pstd_001
184107811-std_001
184102311-std_001
180210511-std_001 x 2
180225121-std_001

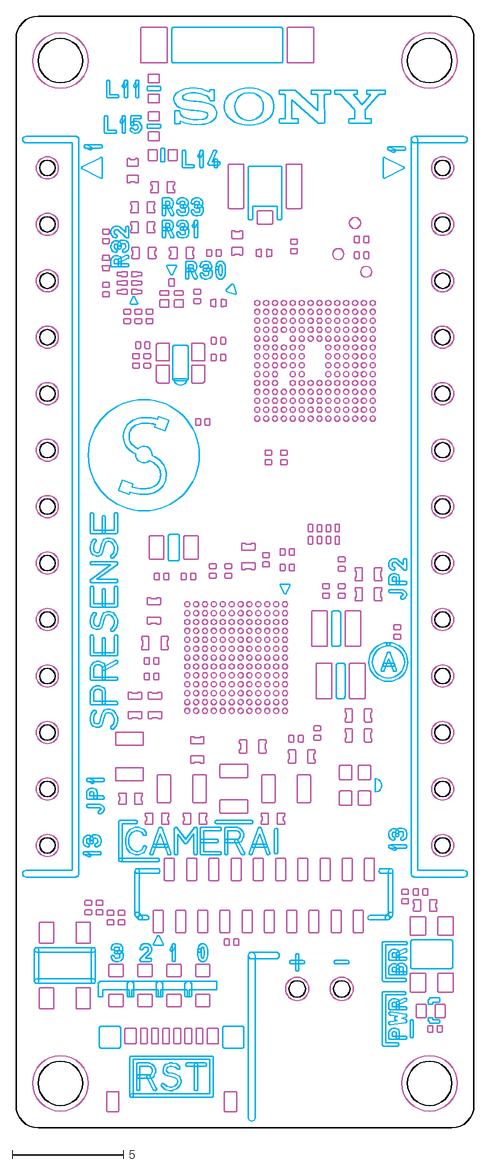
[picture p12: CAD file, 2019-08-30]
CXD5602PWBMAIN1/dxf/CXD5602PWBMAIN1_side_a.dxf
20.6 x 50.0

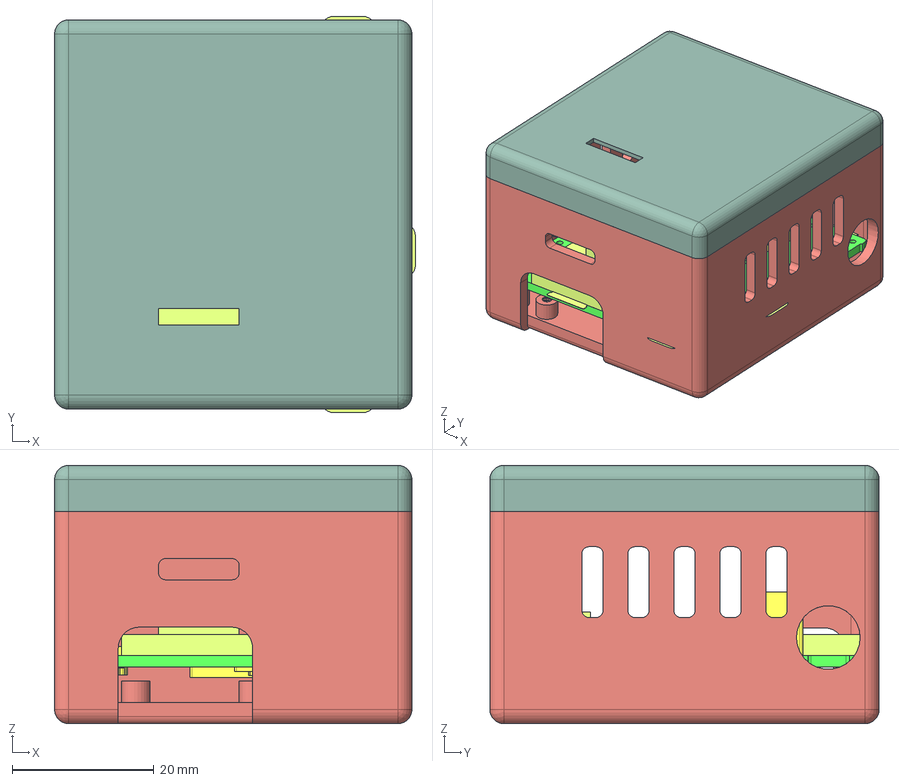
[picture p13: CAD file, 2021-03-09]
Case/LTE-Board-Case-Sample/step/LTE-Board-Case-Sample.step
51.0 x 56.0 x 36.5 mm
CXD5602PWBLM1 v1
lid

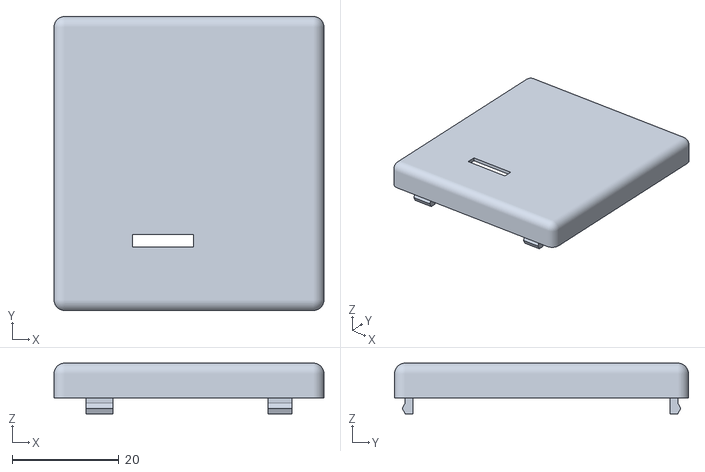
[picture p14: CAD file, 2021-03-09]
Case/LTE-Board-Case-Sample/stl/LTE-Board-Case-Sample_top.stl
50.5 x 55.0 x 9.50

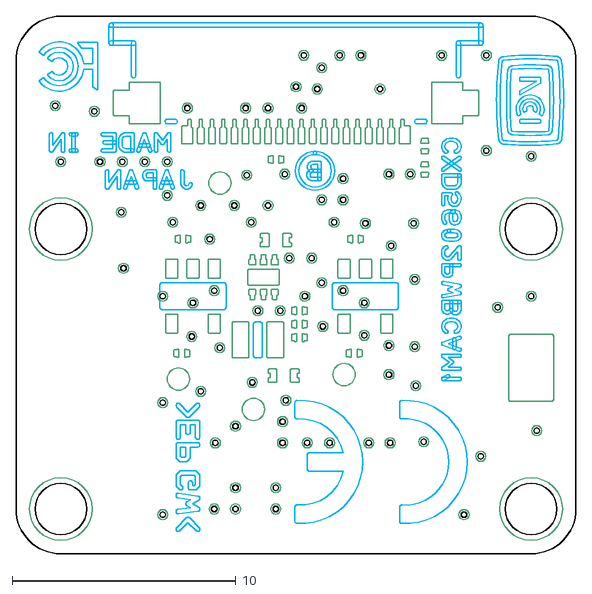
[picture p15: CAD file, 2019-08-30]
CXD5602PWBCAM1/dxf/CXD5602PWBCAM1_side_b.dxf
25.0 x 24.0

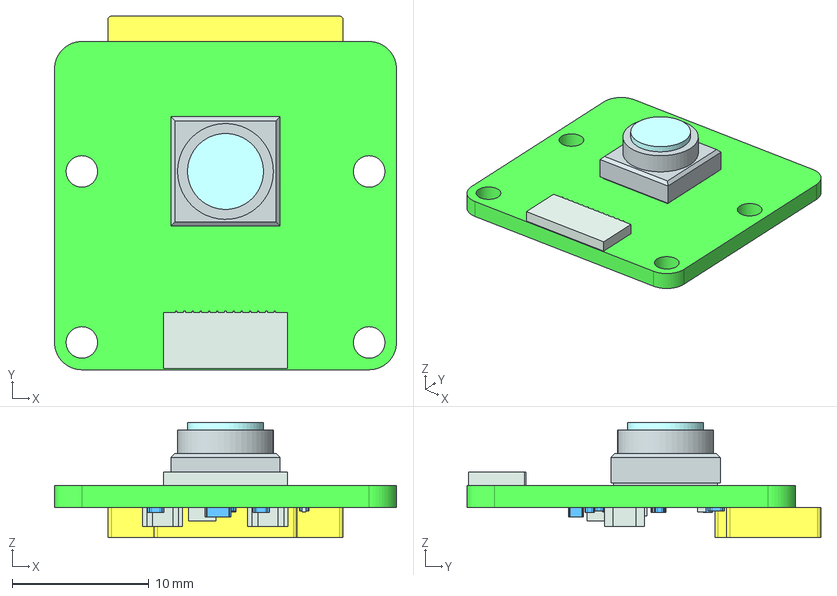
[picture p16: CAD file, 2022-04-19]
CXD5602PWBCAM1/stp/CXD5602PWBCAM1.stp
25.0 x 25.9 x 8.43 mm
148275521-std_001
124072191-std_005
124067991-std_004
111877311-std_002
184476711-std_001
111877311-std_004
672076001-std_001
124072191-std_004
124072191-std_006
124067991-std_001
124067991-std_003
20191003_camera_lens_001
124067991-std_002
124072191-std_008
111817311-std_001
672425501-std_001
111817311-std_003
672318801-std_001
124072191-std_001
124072191-std_003
124072191-std_007
111877311-std_003
111817311-std_002
111877311-std_001
111817311-std_004
148278211-std_001
124072191-std_002
111816811-std_002
111816811-std_004
111816811-std_005
111816811-std_008
111816811-std_010
111816811-std_012
111816811-std_003
111816811-std_006
111816811-std_001
111816811-std_007
111816811-std_009
111816811-std_011
111816811-std_013
111816811-std_014
111816811-std_015
111816811-std_016
111816811-std_017
111816811-std_018
111898411-std_004
111898411-std_001
111816811-std_019
111816811-std_020
111898411-std_002
111898411-std_003

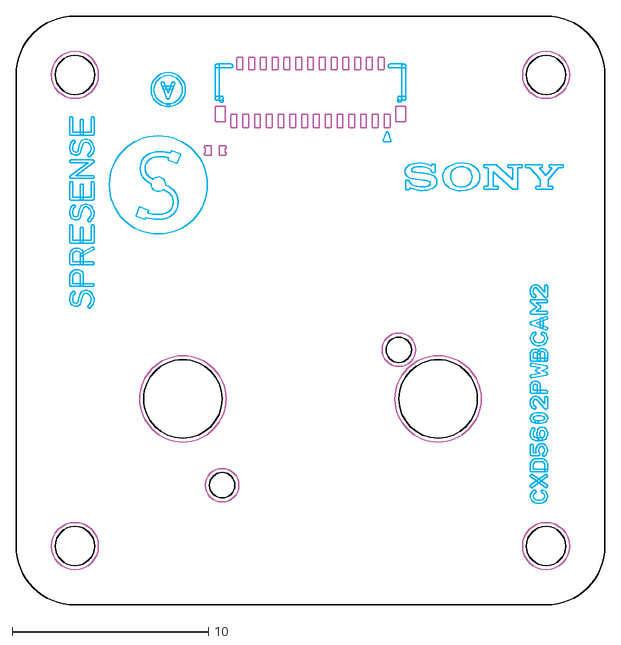
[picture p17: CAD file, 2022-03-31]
CXD5602PWBCAM2/dxf/CXD5602PWBCAM2_side_a.dxf
30.0 x 30.0

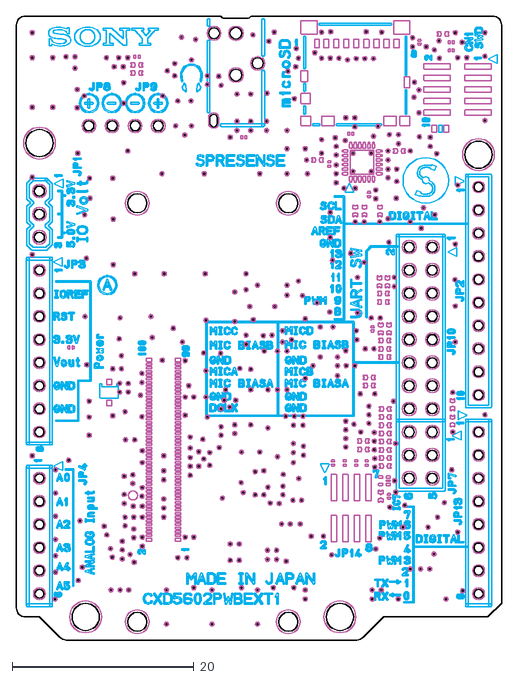
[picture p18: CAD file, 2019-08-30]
CXD5602PWBEXT1/dxf/CXD5602PWBEXT1_side_a.dxf
53.3 x 68.6

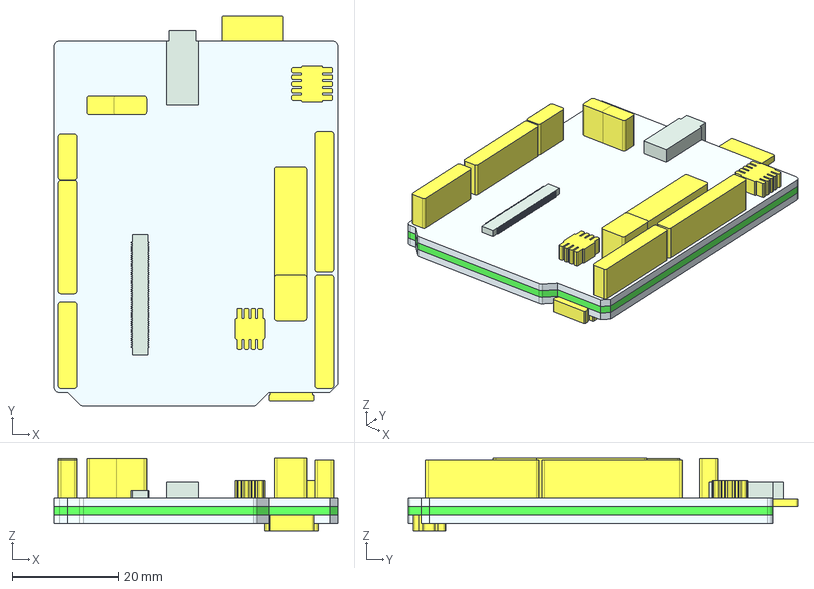
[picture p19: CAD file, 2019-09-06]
CXD5602PWBEXT1/stp/CXD5602PWBEXT1.stp
53.3 x 73.3 x 13.6 mm
112094111-std_001 x 25
111816811-std_001 x 16
112002911-std_001
111673211-std_001 x 2
112048411-std_001
111898431-std_001 x 2
111802811-std_001
650425601-std_001 x 3
125050911-std_001 x 2
121899081-std_001 x 35
125051911-std_001 x 7
121897381-std_001 x 3
123437521-std_001 x 4
123438121-std_001
671565001-std_001
672260201-std_001
672103001-std_001
121898081-std_001 x 3
121894181-std_001
121895381-std_001 x 2
121686491-std_001
125054811-std_001
125054211-std_001
121898581-std_001
121898981-std_001
121897781-std_001 x 4
125052911-std_001 x 2
655355001-std_001
121898381-std_001
121893381-std_001 x 4
655296201-std_001
125053811-std_001 x 4
184287911-std_001
184361811-pstd_001
181738011-std_001
125048711-std_001 x 2
180210511-std_001 x 2
671683601-std_001
672291201-std_001

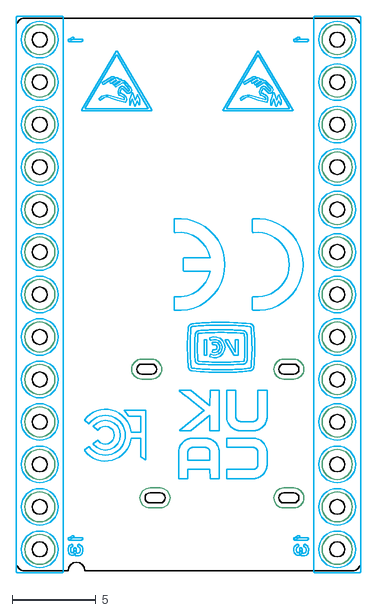
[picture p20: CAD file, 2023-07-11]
CXD5602PWBGNSS1/dxf/CXD5602PWBGNSS1_side_b.dxf
20.6 x 33.3

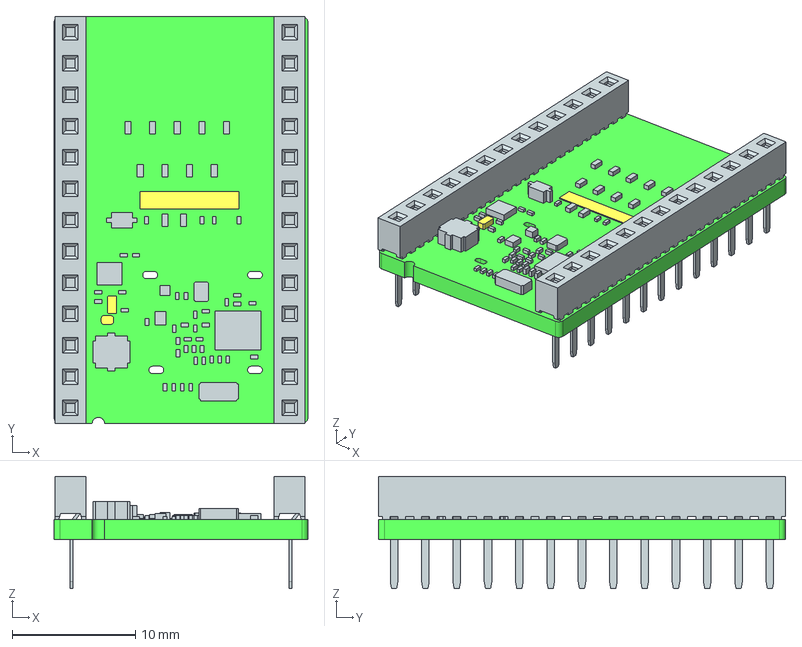
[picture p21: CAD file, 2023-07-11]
CXD5602PWBGNSS1/stp/CXD5602PWBGNSS1.stp
20.6 x 33.0 x 9.10 mm
112094111-std x 11
112230611-std x 4
101583711-std
111816811-std x 2
111802811-std x 2
111878811-std x 2
111882611-std
111875311-std
650425601-std
181838111-std
148125821-std x 3
148187911-std
148188811-std
148189011-std
148188511-std
148274121-std x 2
690310701-std
672343701-std
875611571-std
121899081-std x 8
125728511-std
124829711-std x 2
125722911-std
125730111-std
124071891-std x 3
125054311-std
124070391-std x 2
101679511-pstd x 2
101583611-std
101679611-std

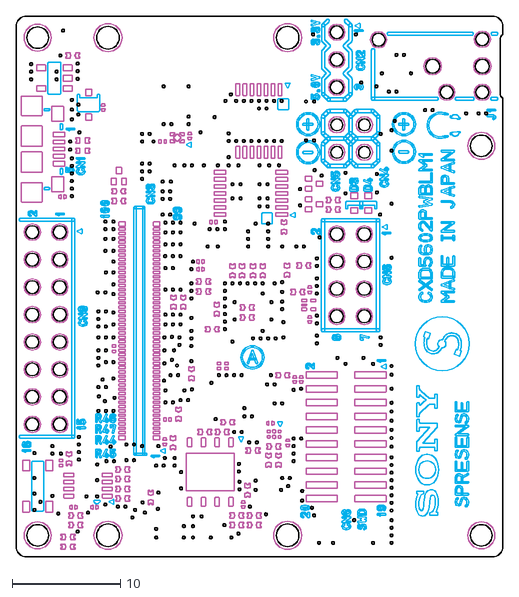
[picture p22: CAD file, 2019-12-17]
CXD5602PWBLM1/dxf/CXD5602PWBLM1_side_a.dxf
45.0 x 50.0

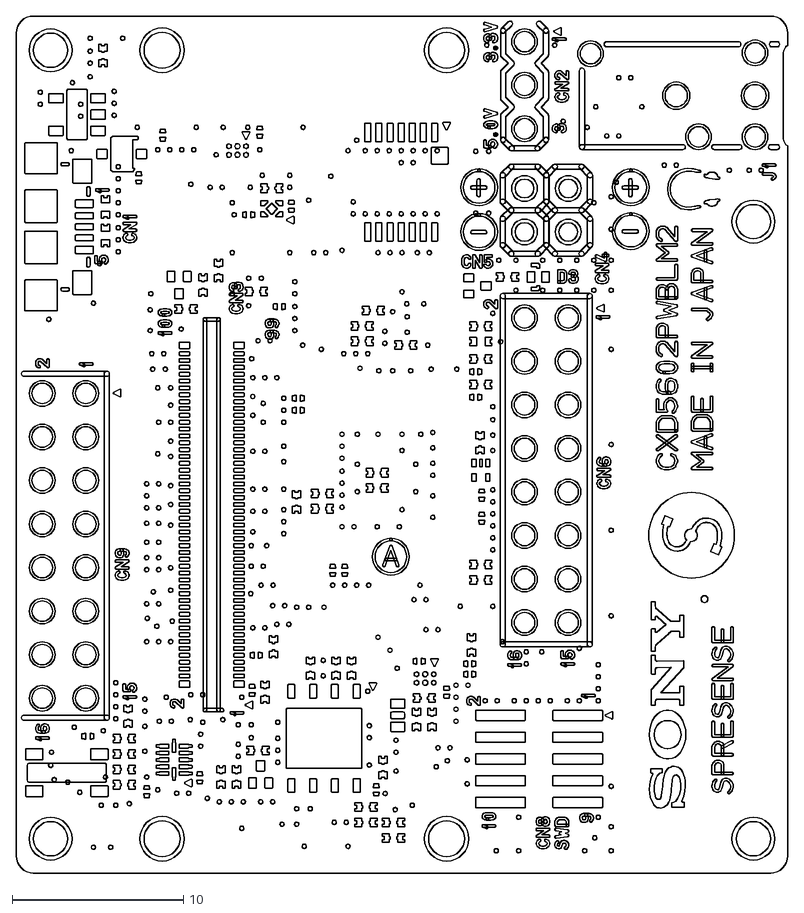
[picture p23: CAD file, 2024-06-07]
CXD5602PWBLM2/dxf/CXD5602PWBLM2_side_a.dxf
45.0 x 50.0

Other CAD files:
Case/LTE-Board-Case-Sample/stl/LTE-Board-Case-Sample_bottom.stl
CXD5602PWBCAM1/dxf/CXD5602PWBCAM1_side_a.dxf
CXD5602PWBCAM2/dxf/CXD5602PWBCAM2_side_b.dxf
CXD5602PWBEXT1/dxf/CXD5602PWBEXT1_side_b.dxf
CXD5602PWBGNSS1/dxf/CXD5602PWBGNSS1_side_a.dxf
CXD5602PWBLM1/dxf/CXD5602PWBLM1_side_b.dxf
CXD5602PWBLM2/dxf/CXD5602PWBLM2_side_b.dxf

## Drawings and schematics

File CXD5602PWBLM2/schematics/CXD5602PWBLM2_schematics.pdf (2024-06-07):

# I/O Power SW JP

# MICRO USB CN TYPE-B

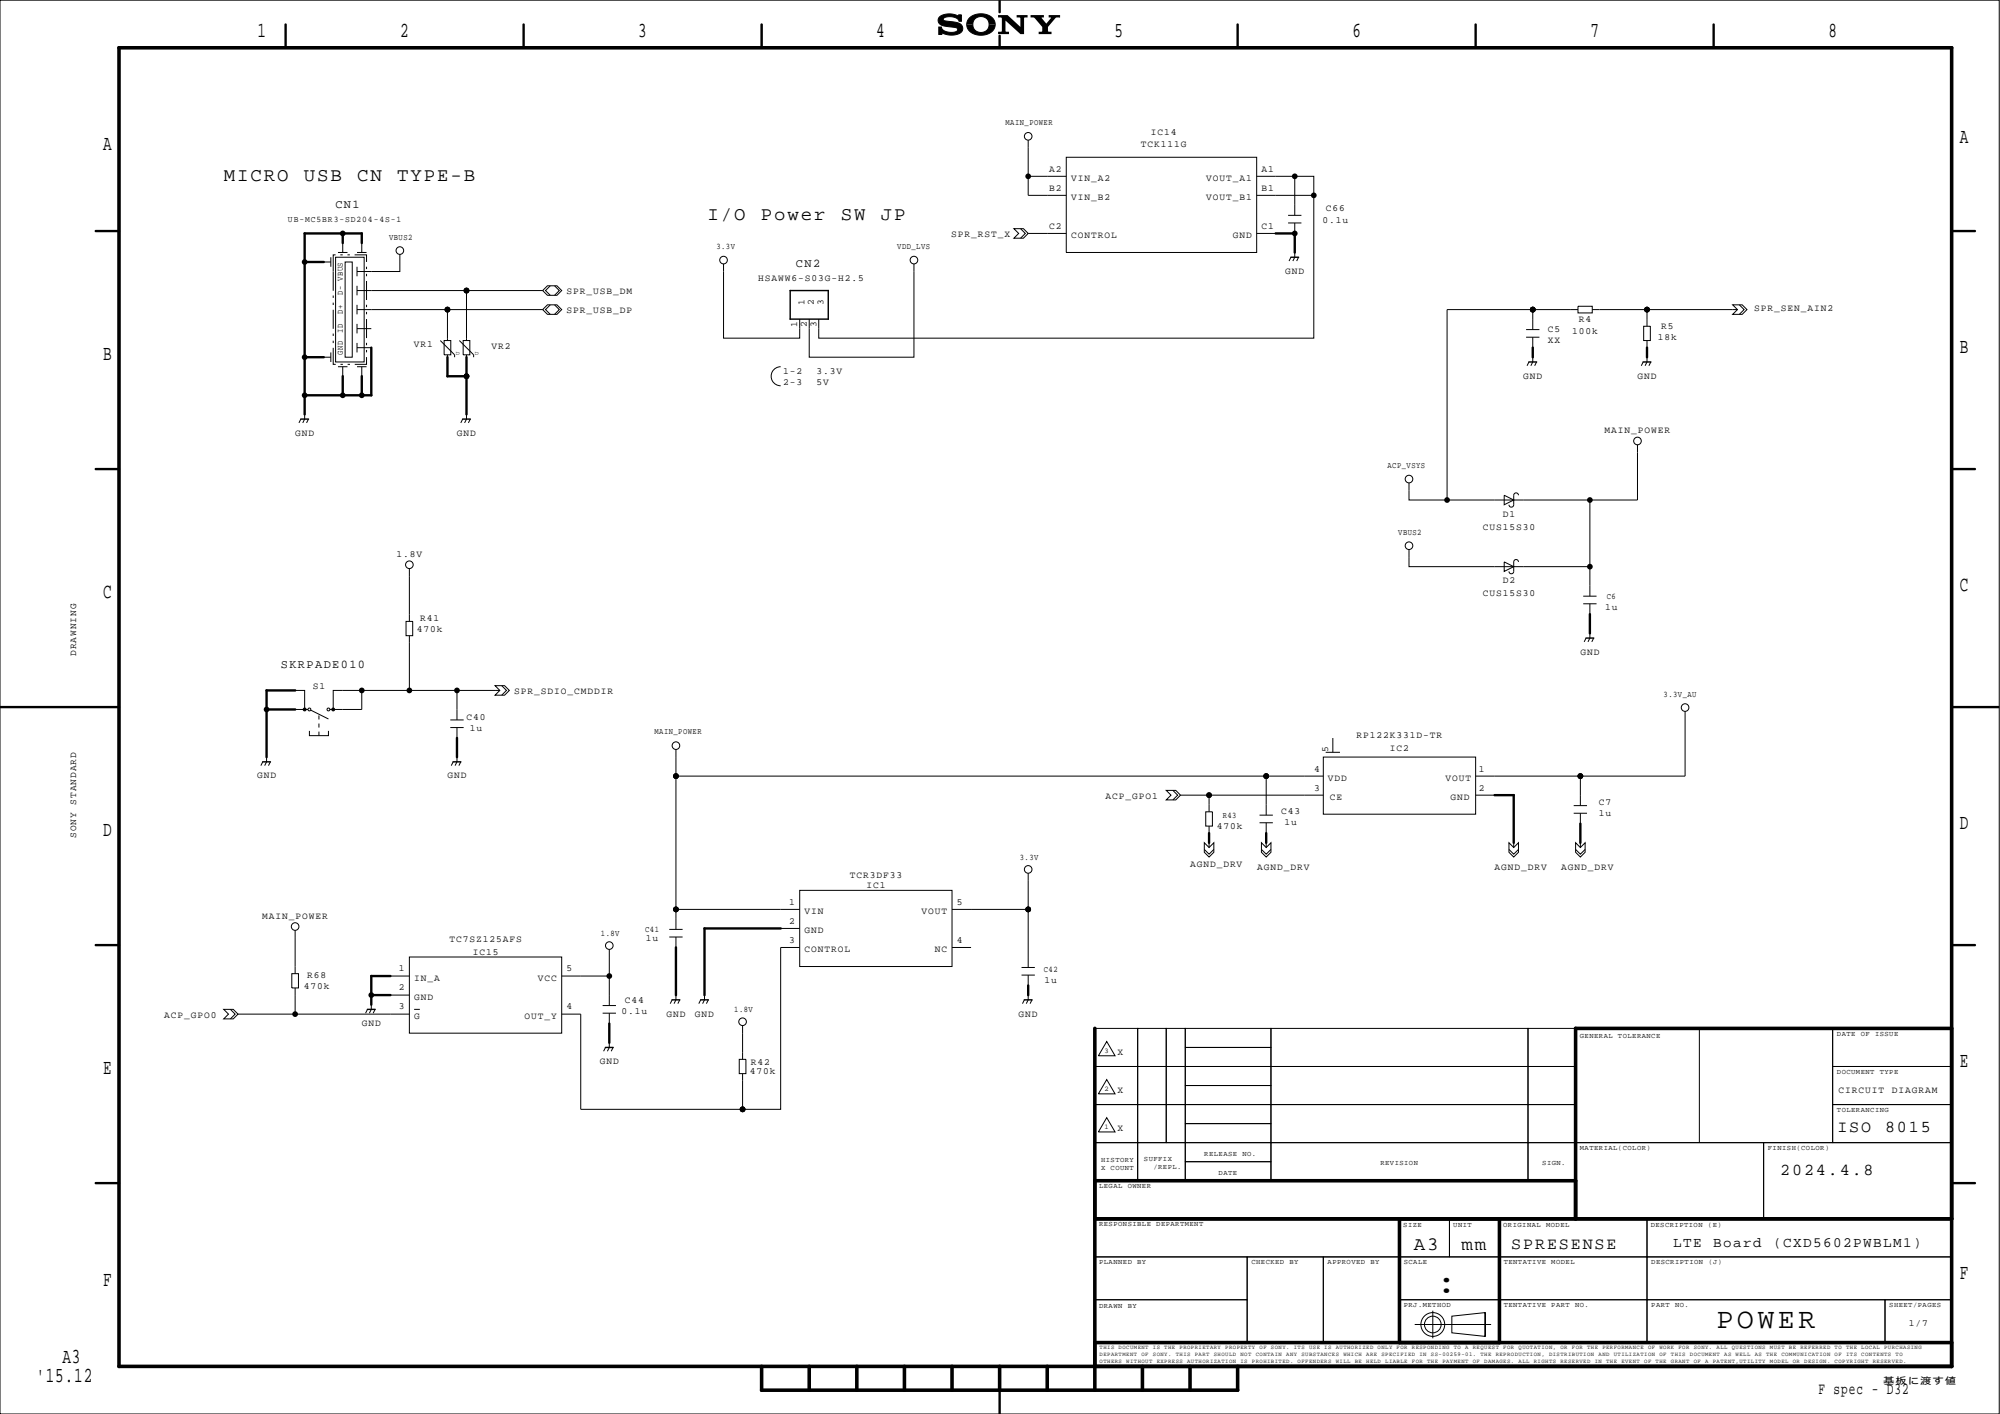
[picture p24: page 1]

THIS DOCUMENT IS THE PROPRIETARY PROPERTY OF SONY. ITS USE IS AUTHORIZED ONLY FOR RESPONDING TO A REQUEST FOR QUOTATION, OR FOR THE PERFORMANCE OF WORK FOR SONY. ALL QUESTIONS MUST BE REFERRED TO THE LOCAL PURCHASING
DEPARTMENT OF SONY. THIS PART SHOULD NOT CONTAIN ANY SUBSTANCES WHICH ARE SPECIFIED IN SS-00259-01. THE REPRODUCTION, DISTRIBUTION AND UTILIZATION OF THIS DOCUMENT AS WELL AS THE COMMUNICATION OF ITS CONTENTS TO
OTHERS WITHOUT EXPRESS AUTHORIZATION IS PROHIBITED. OFFENDERS WILL BE HELD LIABLE FOR THE PAYMENT OF DAMAGES. ALL RIGHTS RESERVED IN THE EVENT OF THE GRANT OF A PATENT,UTILITY MODEL OR DESIGN. COPYRIGHT RESERVED.

CN3

# BtoB CN

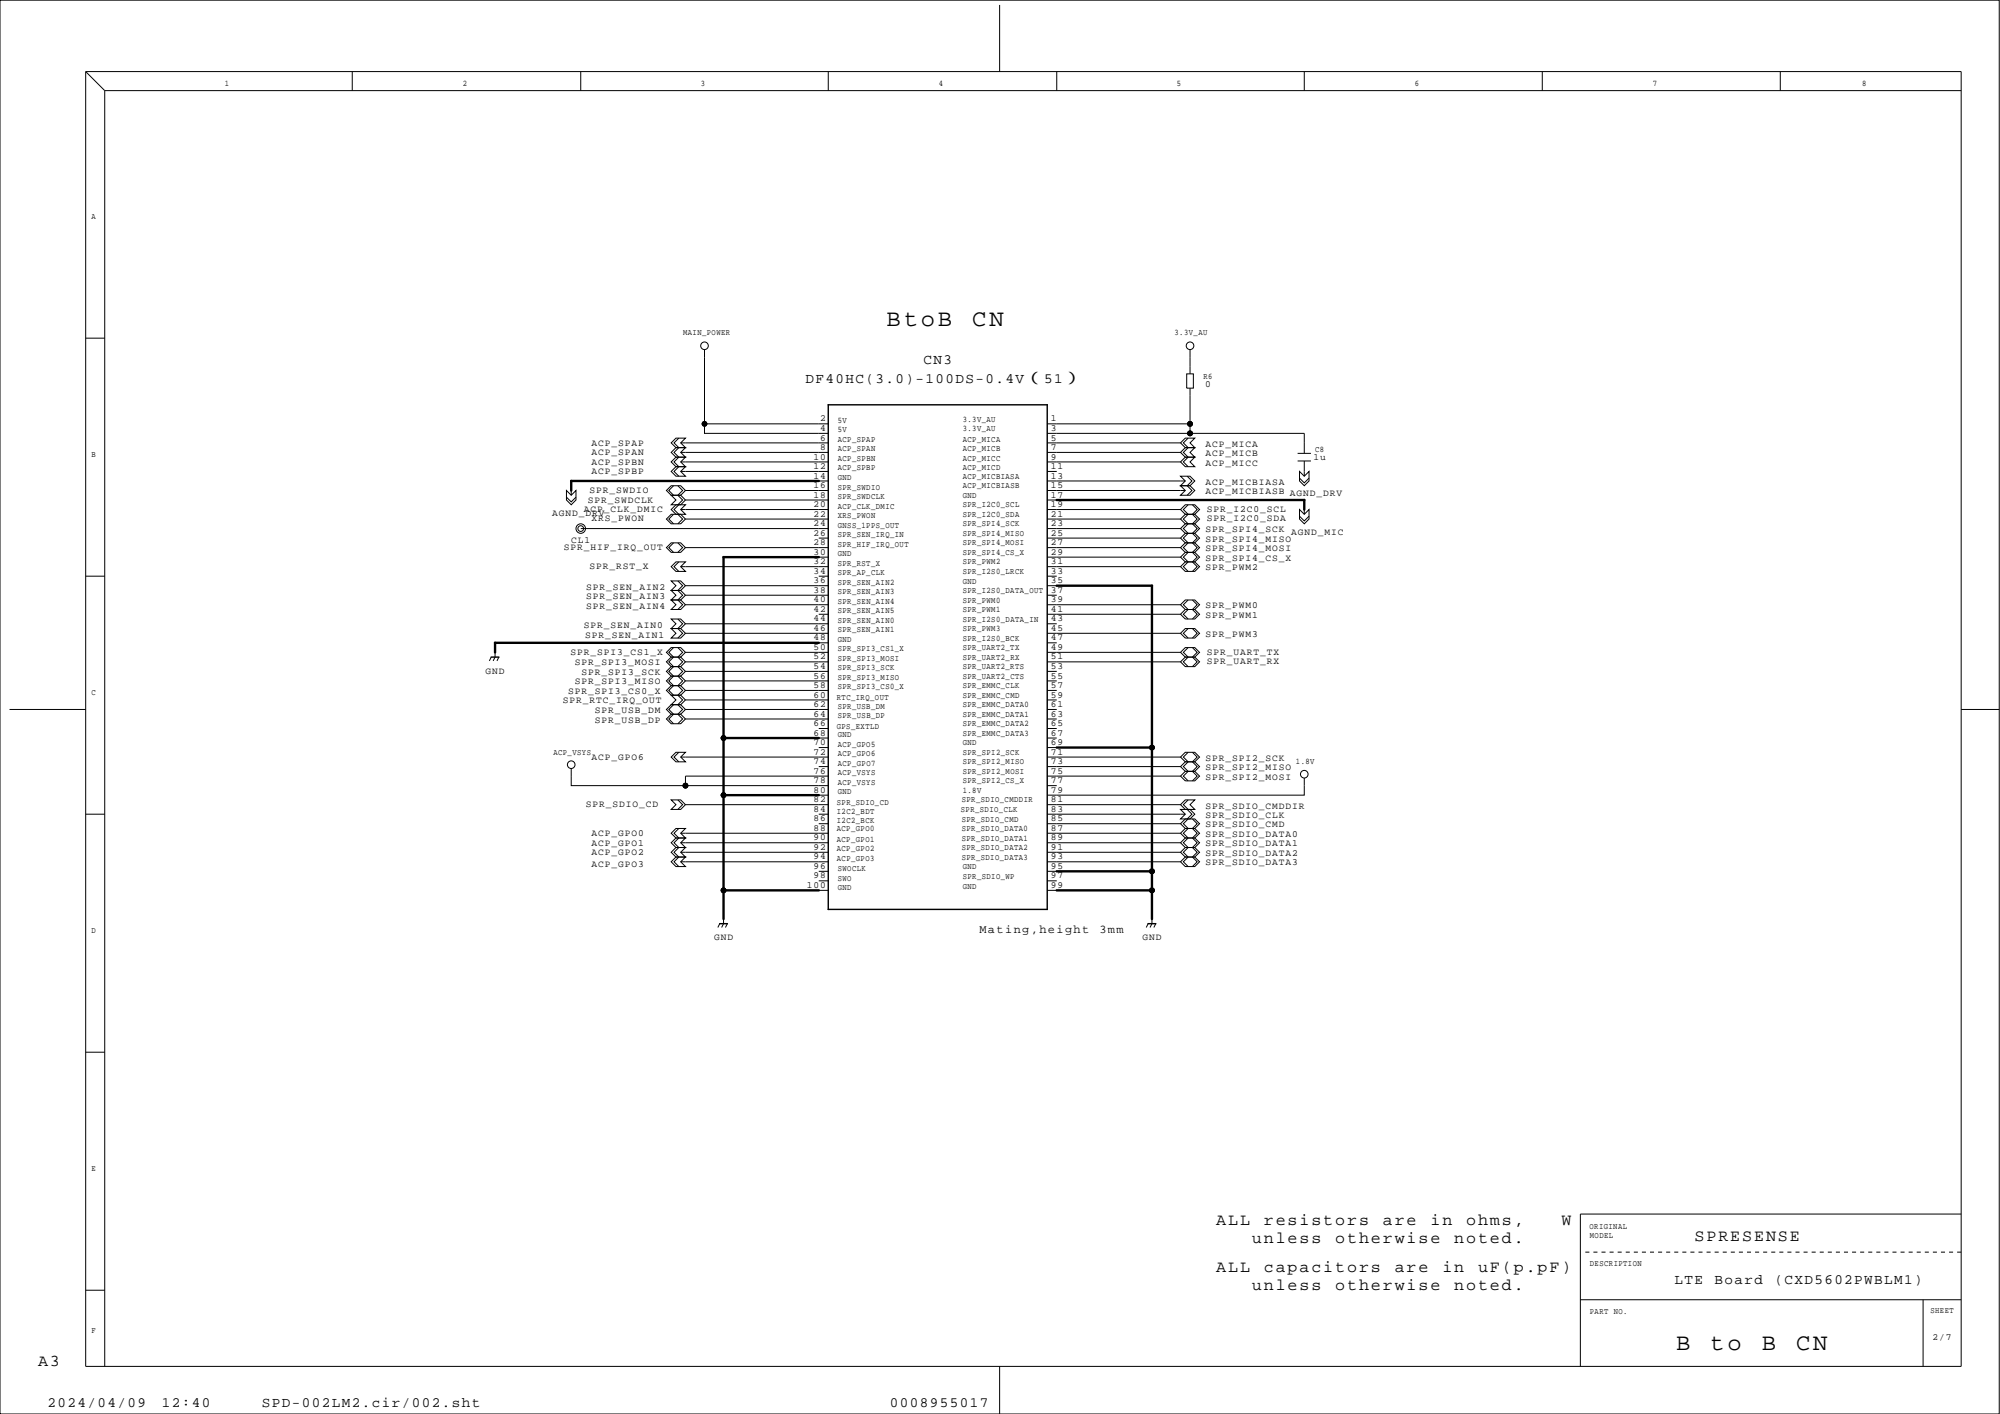
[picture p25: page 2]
SHEET; ORIGINAL; MODEL; DESCRIPTION; SPRESENSE; LTE Board (CXD5602PWBLM1); ALL resistors are in ohms,; SPD-002LM2.cir/002.sht; ACP_MICB; SPR_SWDCLK; ACP_MICA; SPR_SDIO_CD; SPR_RTC_IRQ_OUT; ACP_MICC; SPR_SEN_AIN2; SPR_SDIO_CMDDIR; SPR_SEN_AIN0 SPR_SEN_AIN1; ACP_GPO2; ACP_CLK_DMIC; ACP_MICBIASA; ACP_GPO3; ACP_GPO1; ACP_GPO6; SPR_SDIO_CLK; ACP_SPBP; ACP_MICBIASB; AGND_MIC; AGND_DRV; ACP_GPO0; ACP_SPAP ACP_SPAN ACP_SPBN; SPR_RST_X; SPR_SDIO_DATA0; SPR_SPI3_CS0_X; SPR_SPI3_MISO; SPR_SPI3_SCK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

unless otherwise noted.
ALL capacitors are in uF(p.pF)

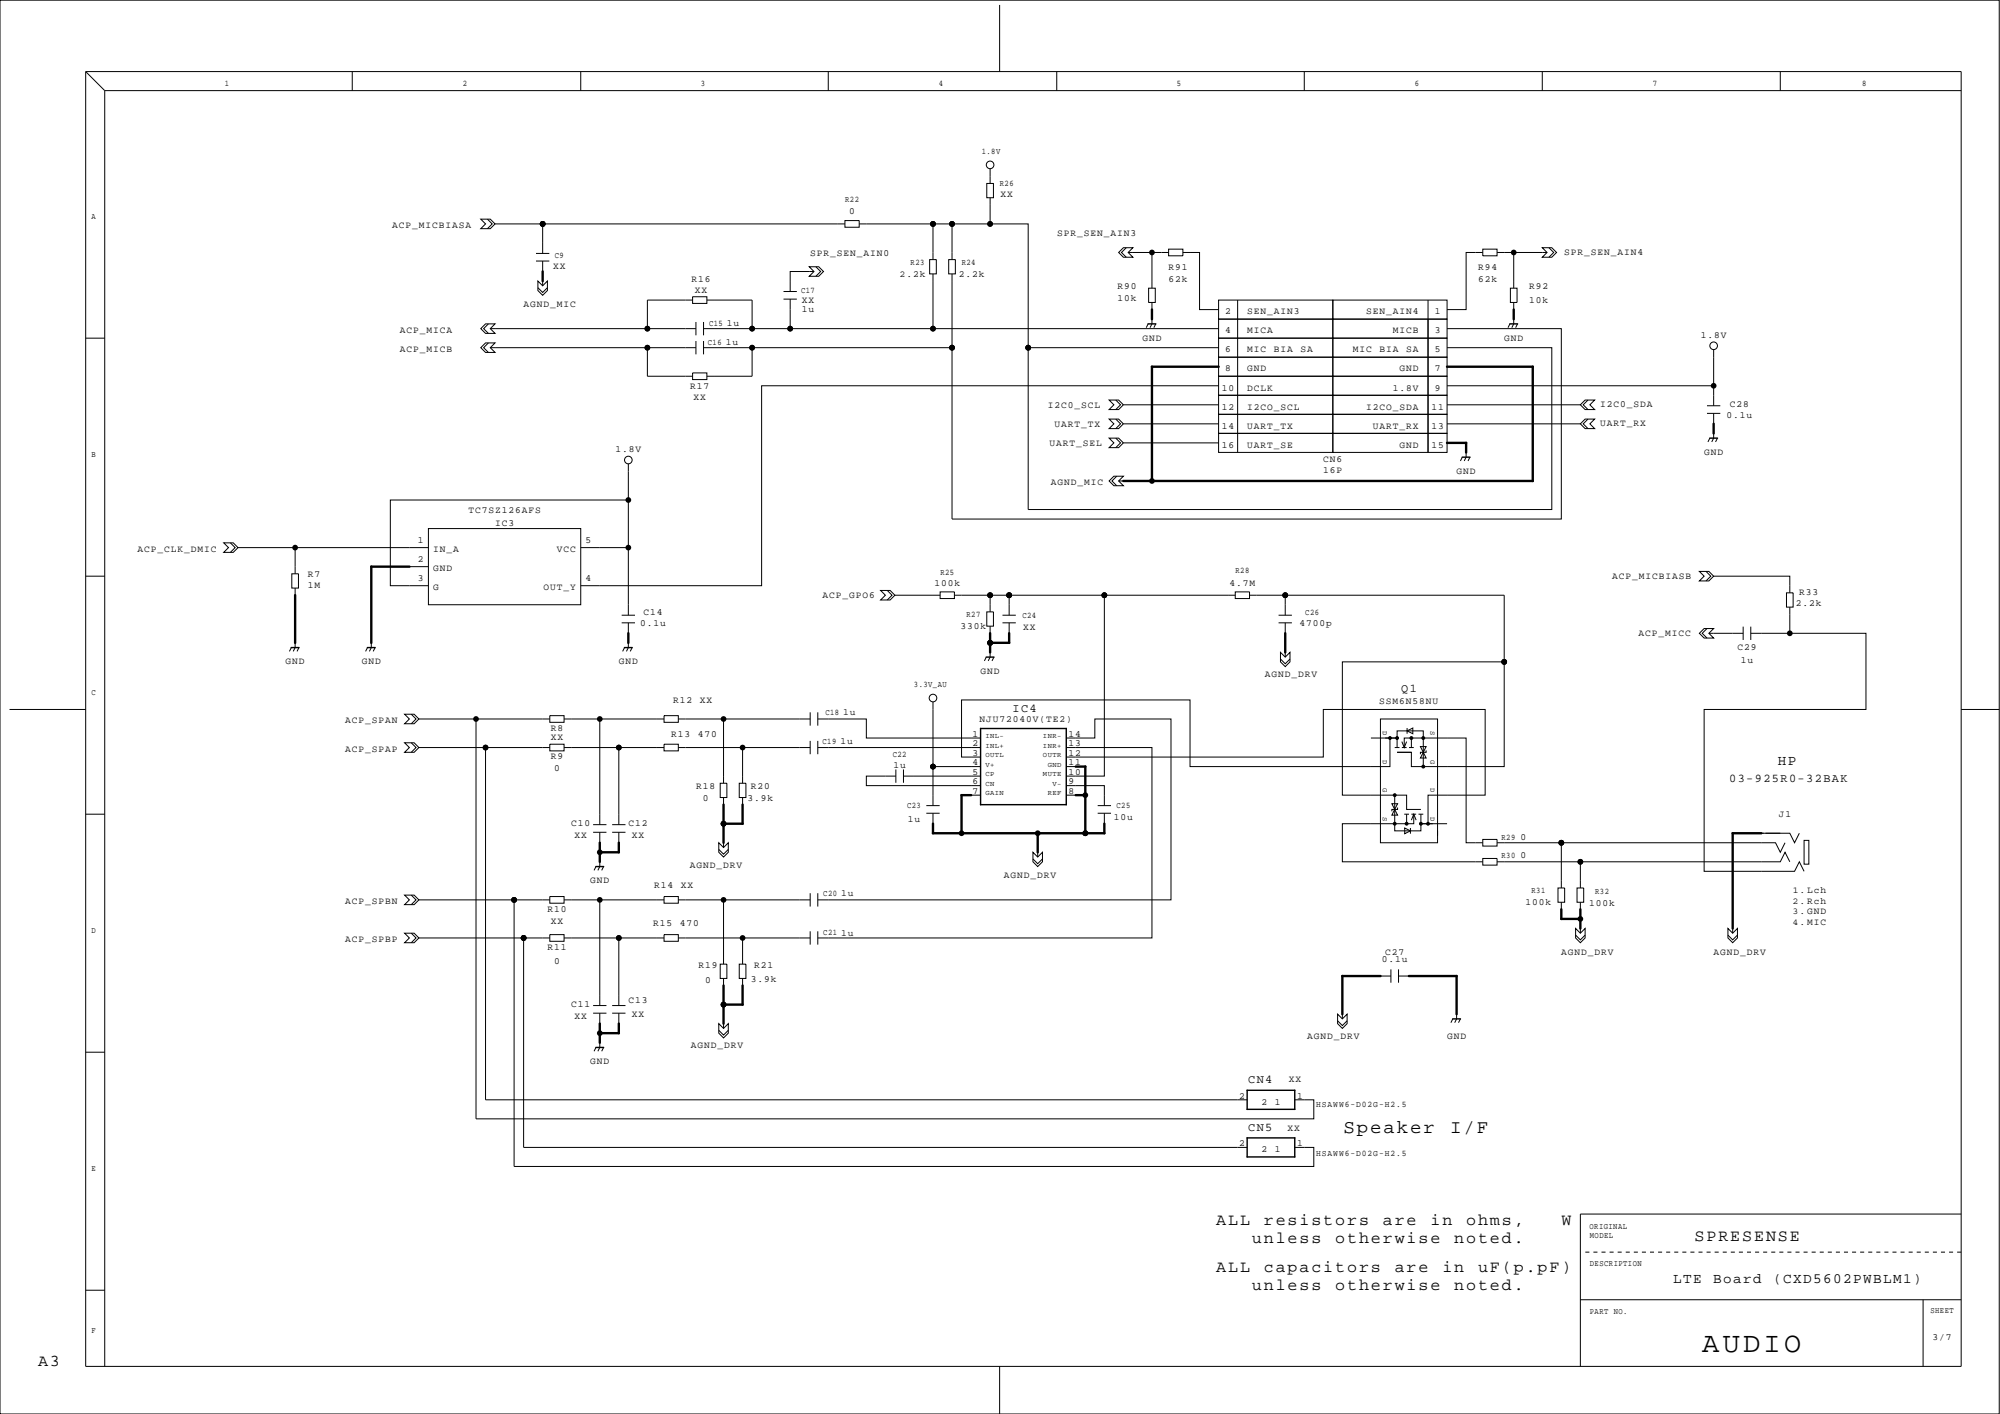
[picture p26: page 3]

2 | SEN_AIN3 | SEN_AIN4 | 1
4 | MICA | MICB | 3

8 | GND | | 7GND
10 | DCLK | 1.8V | 9
12 | I2CO_SCL | I2CO_SDA | 11
14 | UART_TX | UART_RX | 13
16 | UART_SE | | 15GND

unless otherwise noted.
ALL capacitors are in uF(p.pF)

# ST11S008V4HR2000

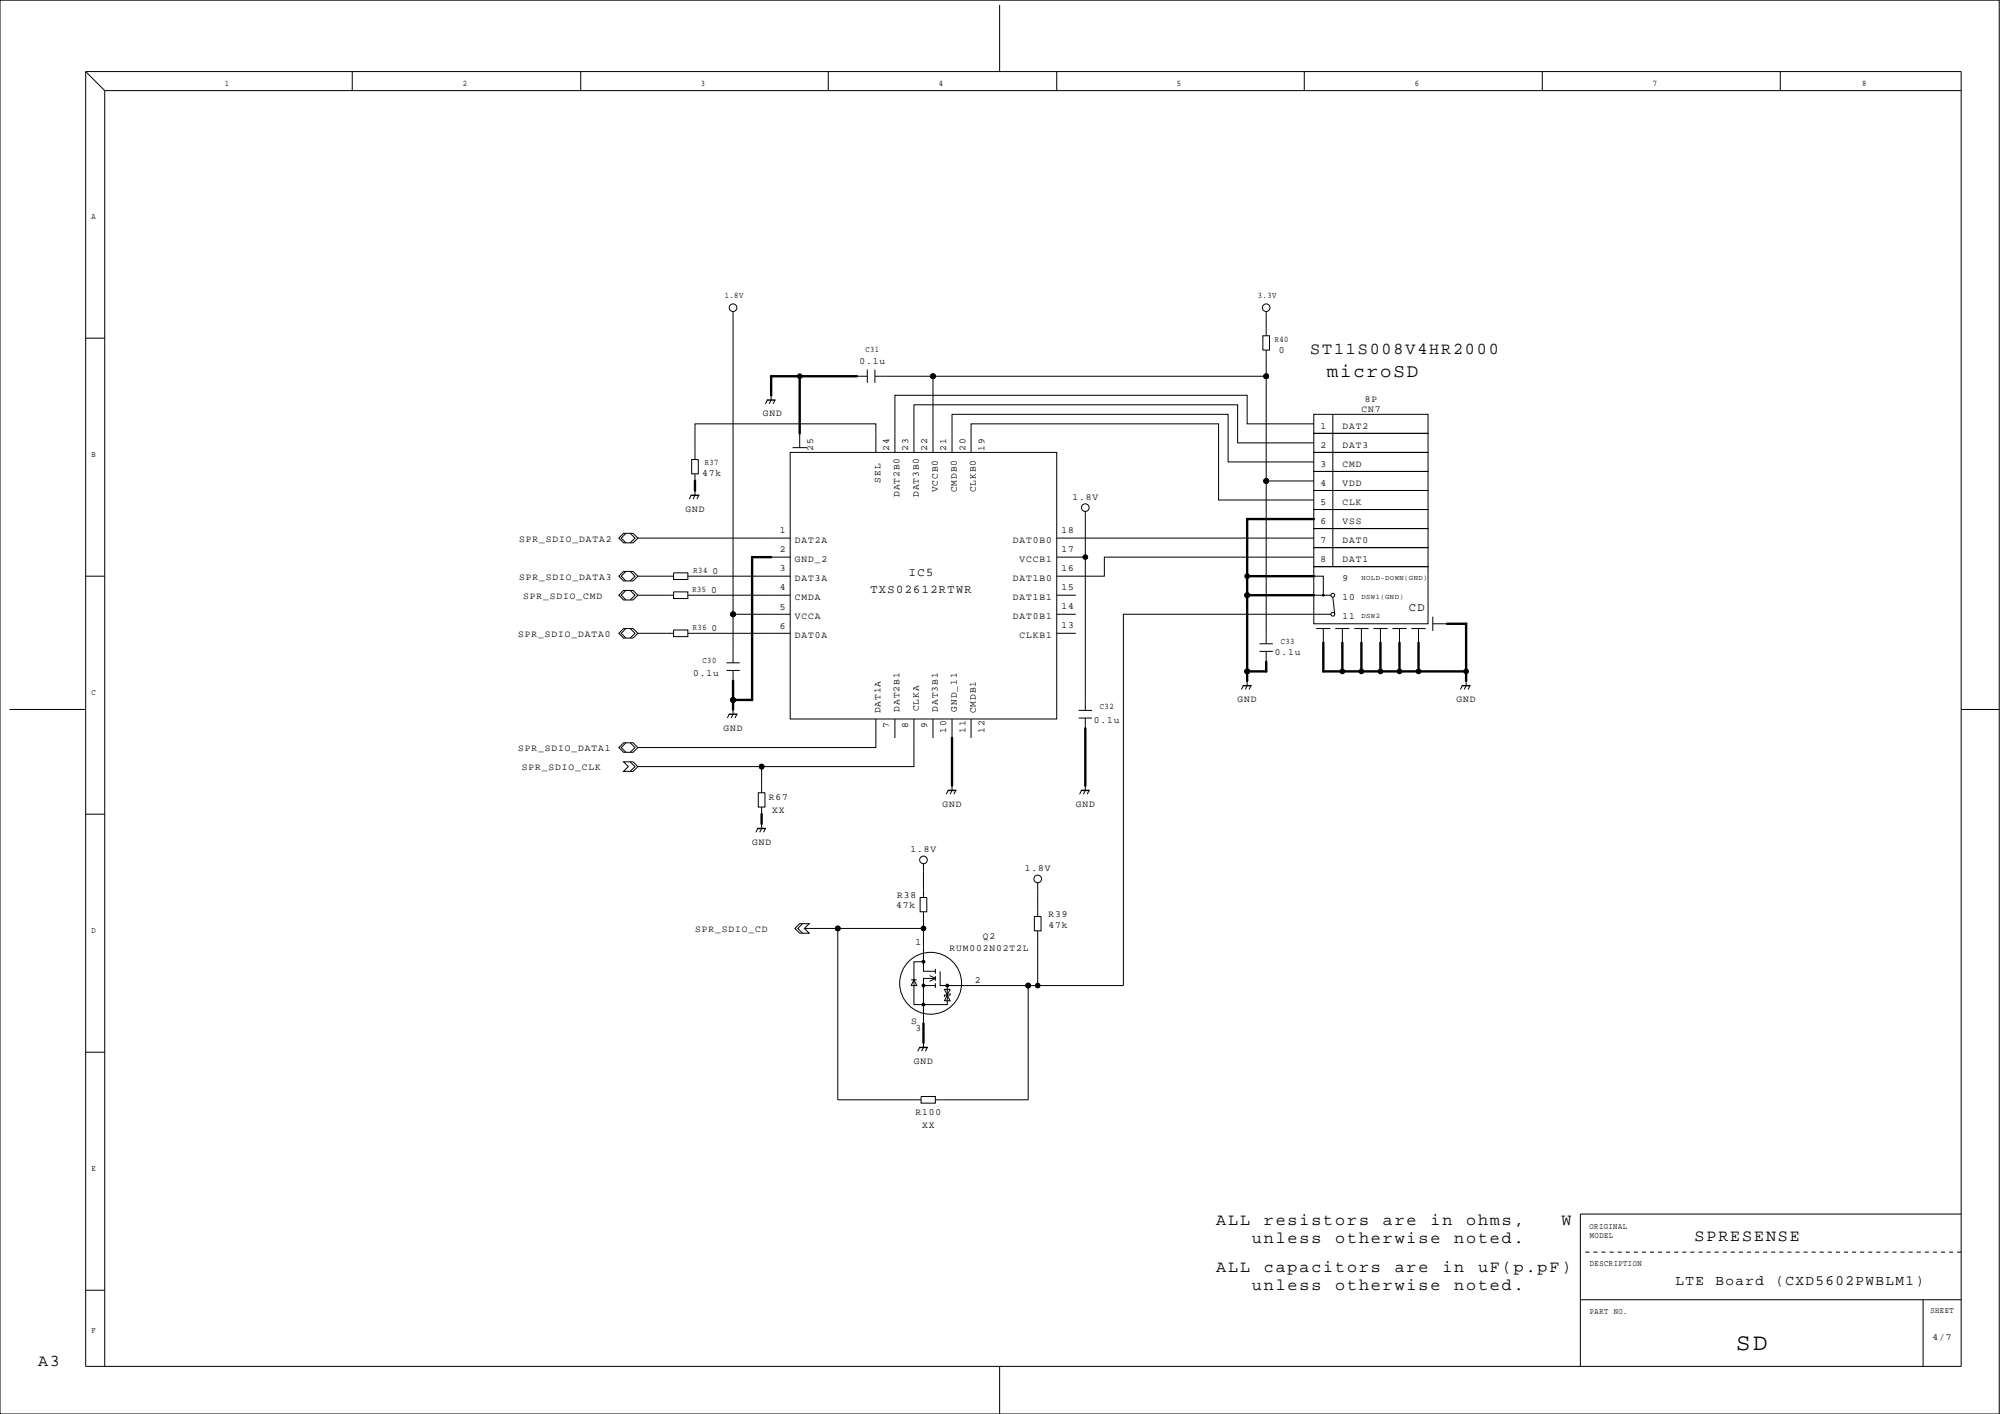
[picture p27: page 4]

1 | DAT2
2 | DAT3

4 | VDD
5 | CLK
6 | VSS
7 | DAT0
8 | DAT1

unless otherwise noted.
ALL capacitors are in uF(p.pF)

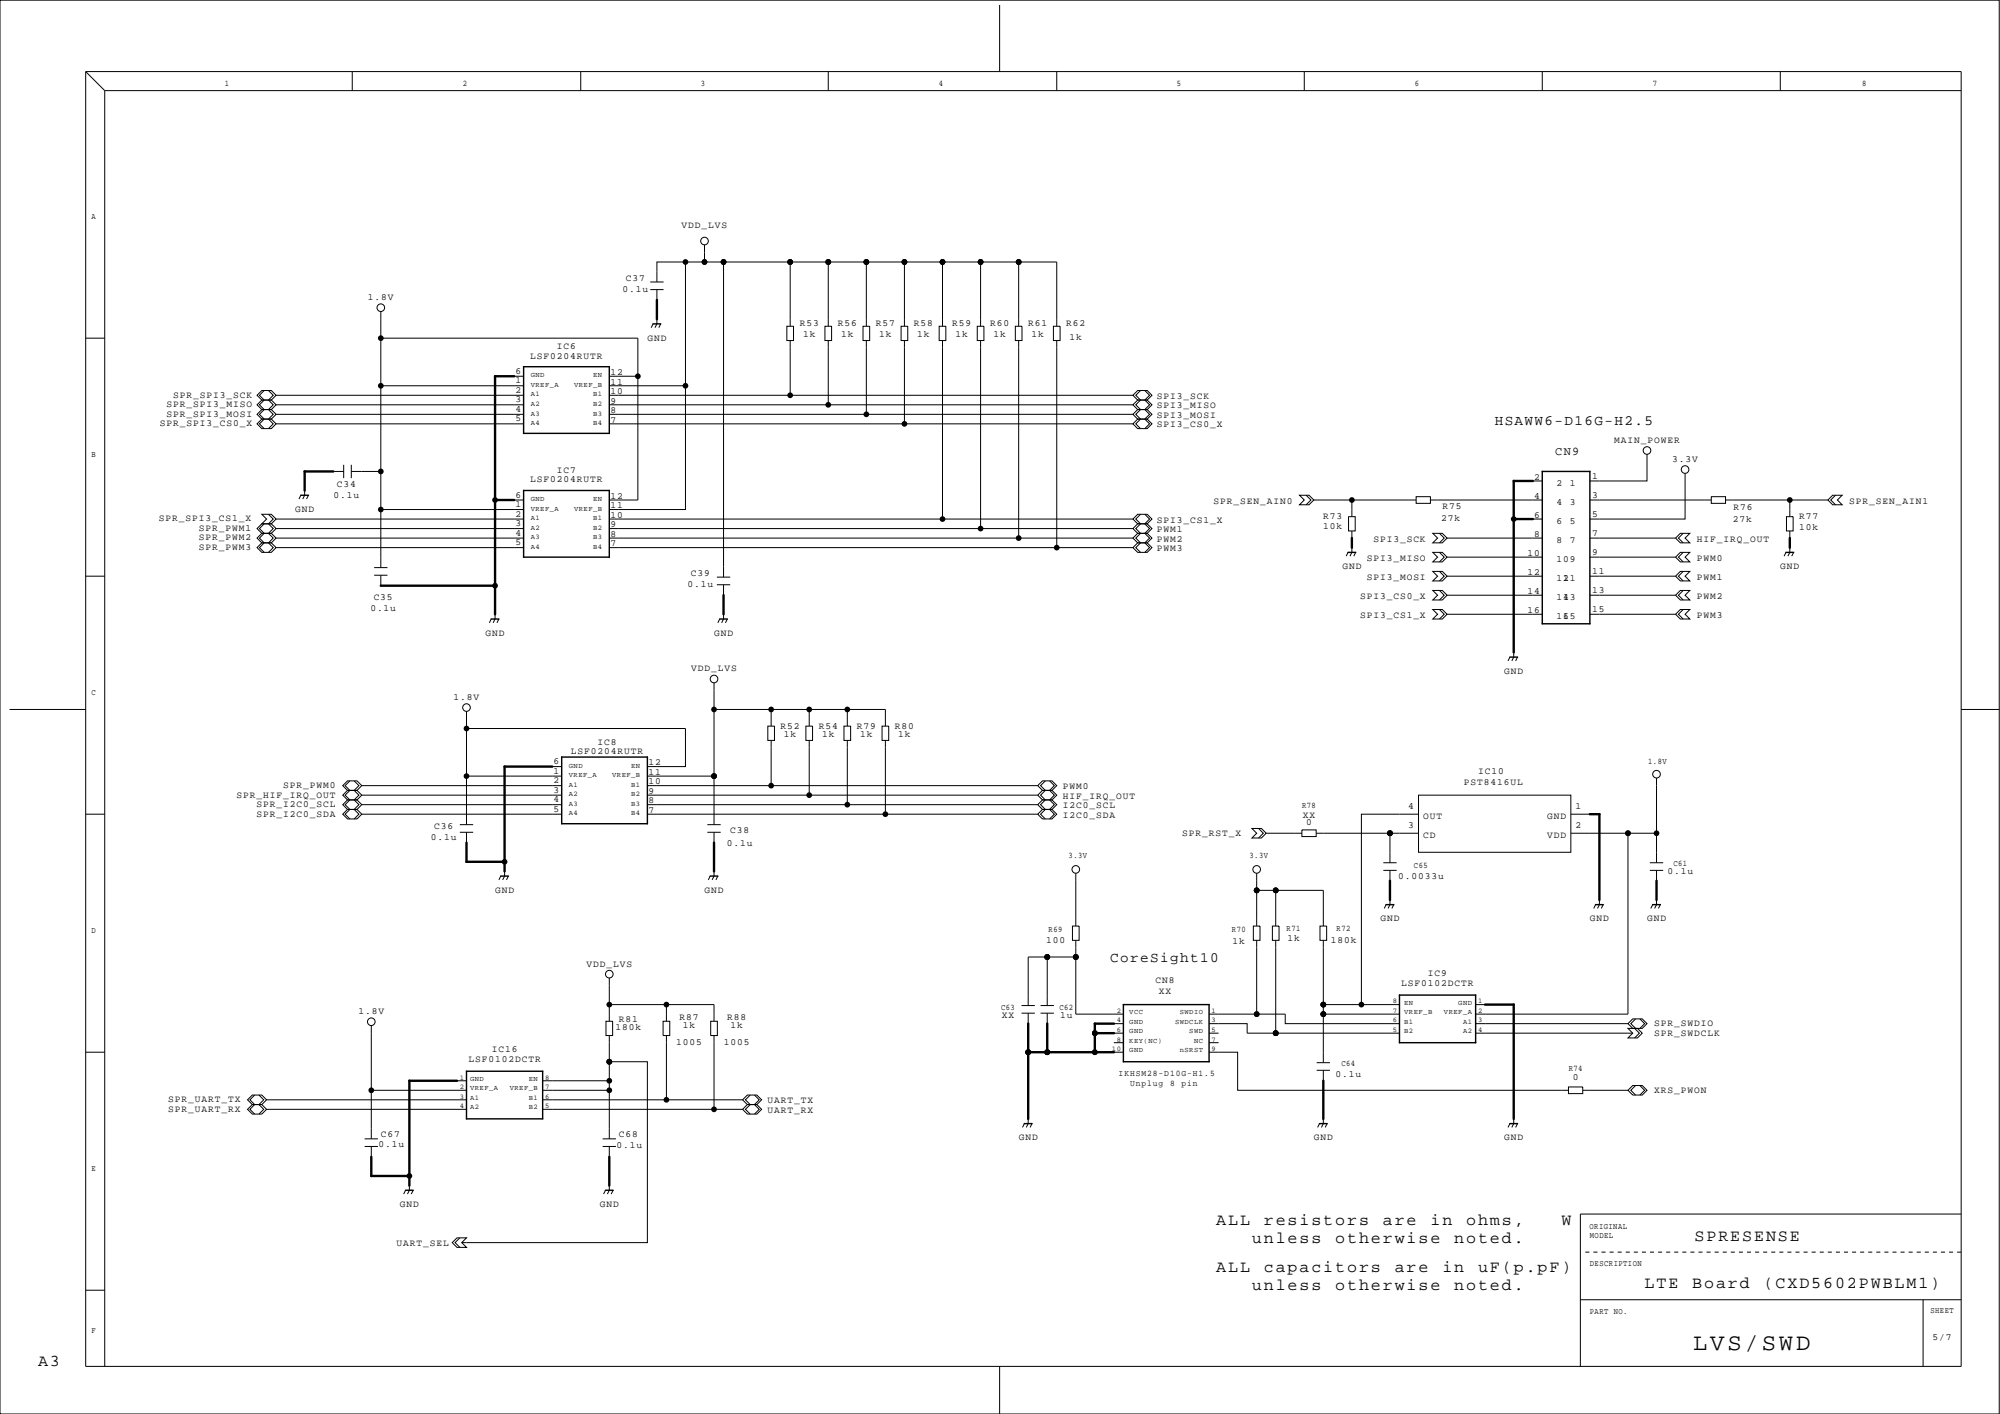
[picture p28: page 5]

unless otherwise noted.
ALL capacitors are in uF(p.pF)

# LBAD01XX1SC

CP1

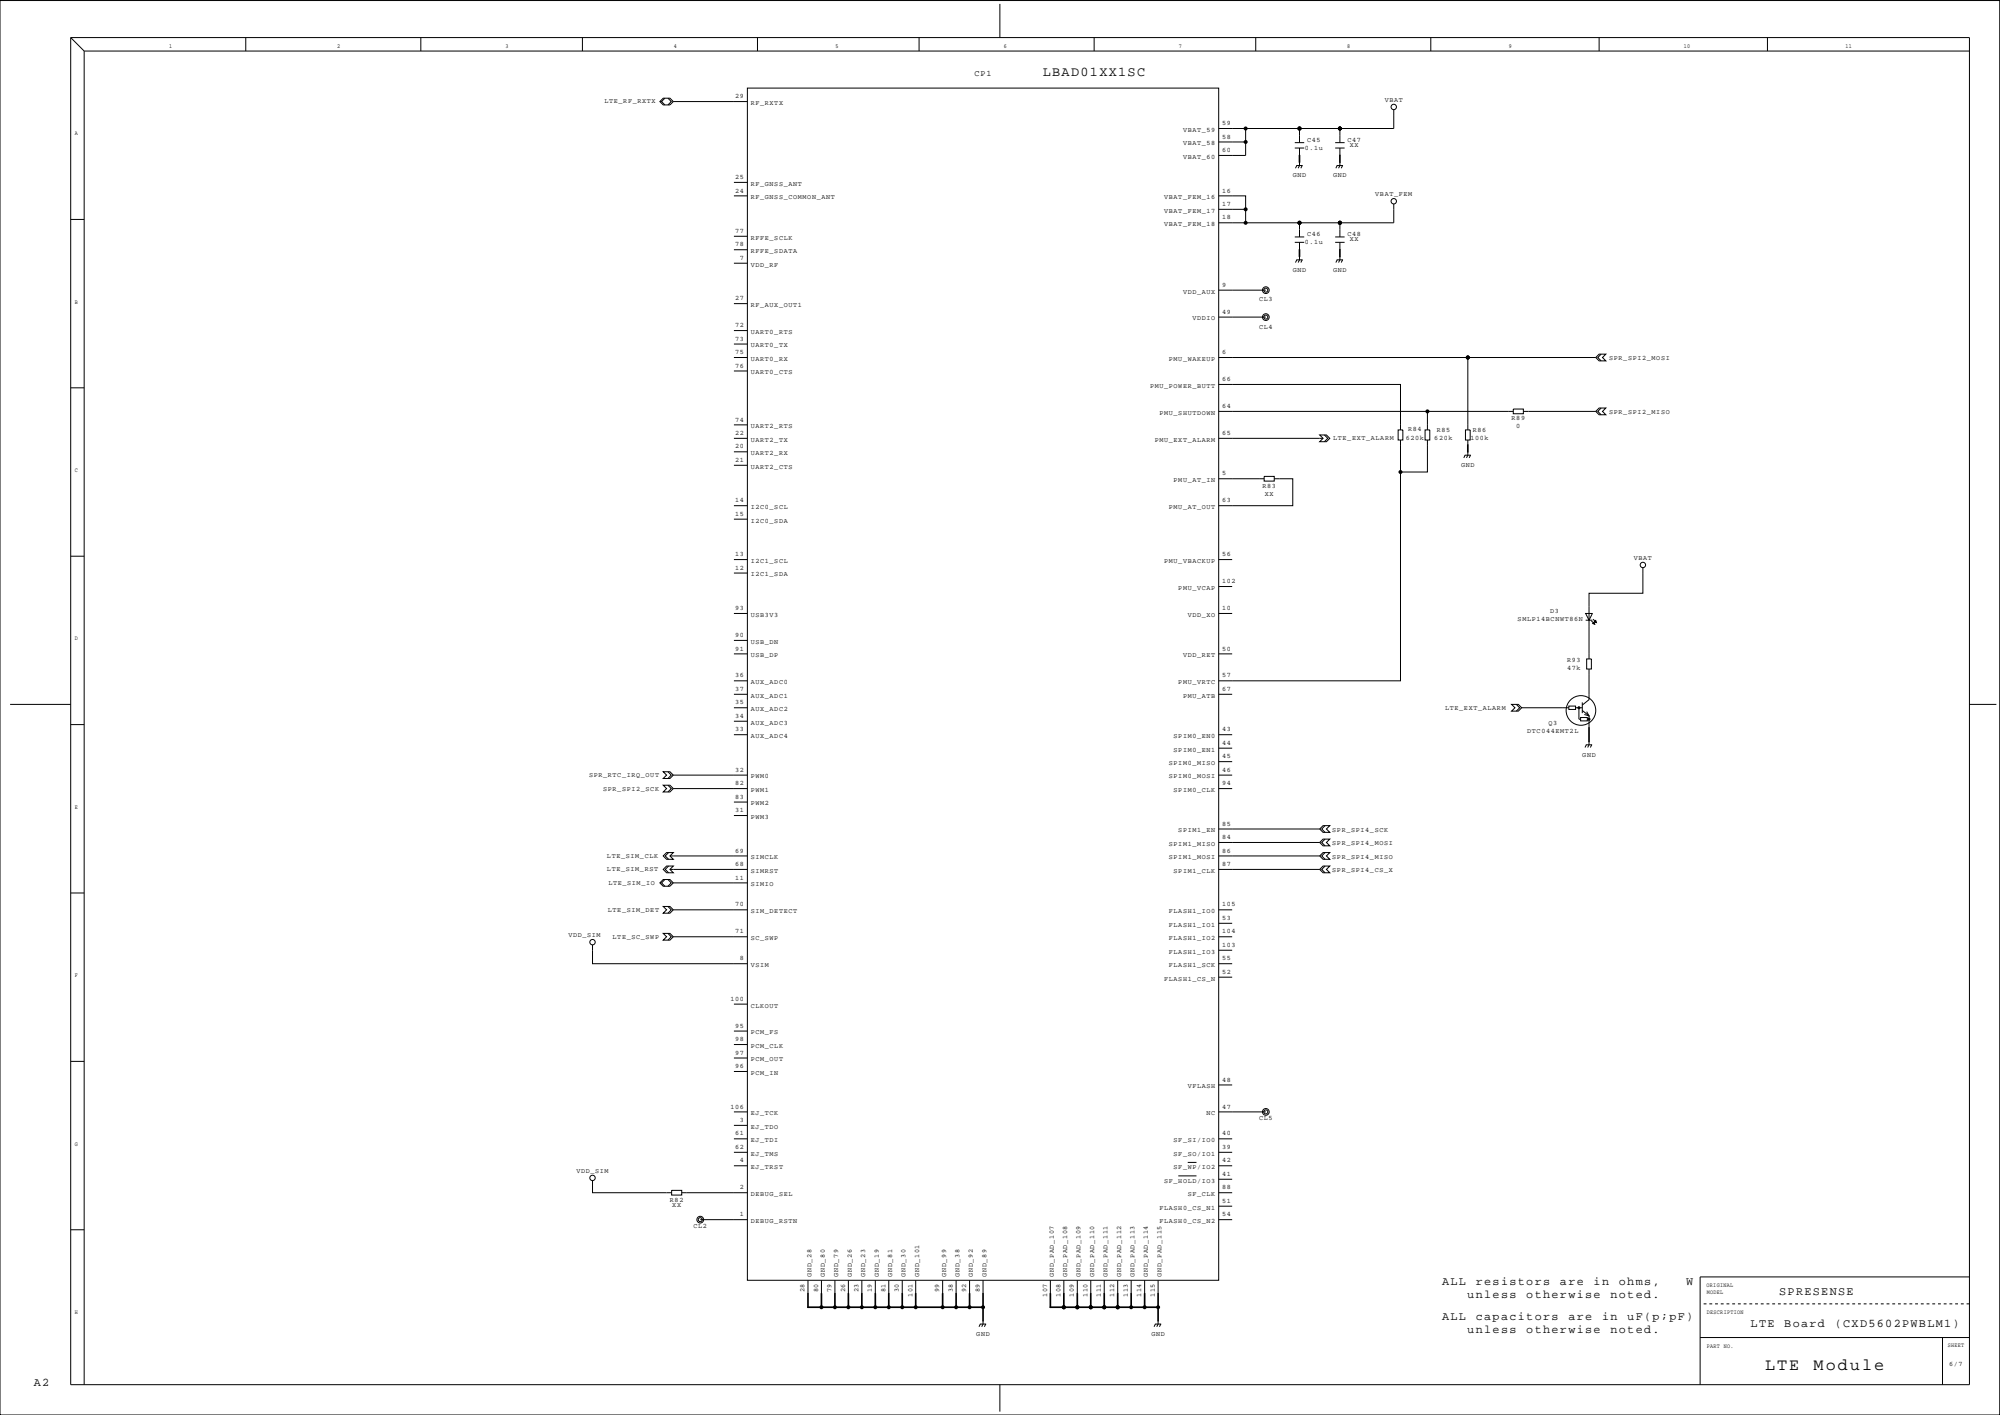
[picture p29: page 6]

unless otherwise noted.
ALL capacitors are in uF(p;pF)

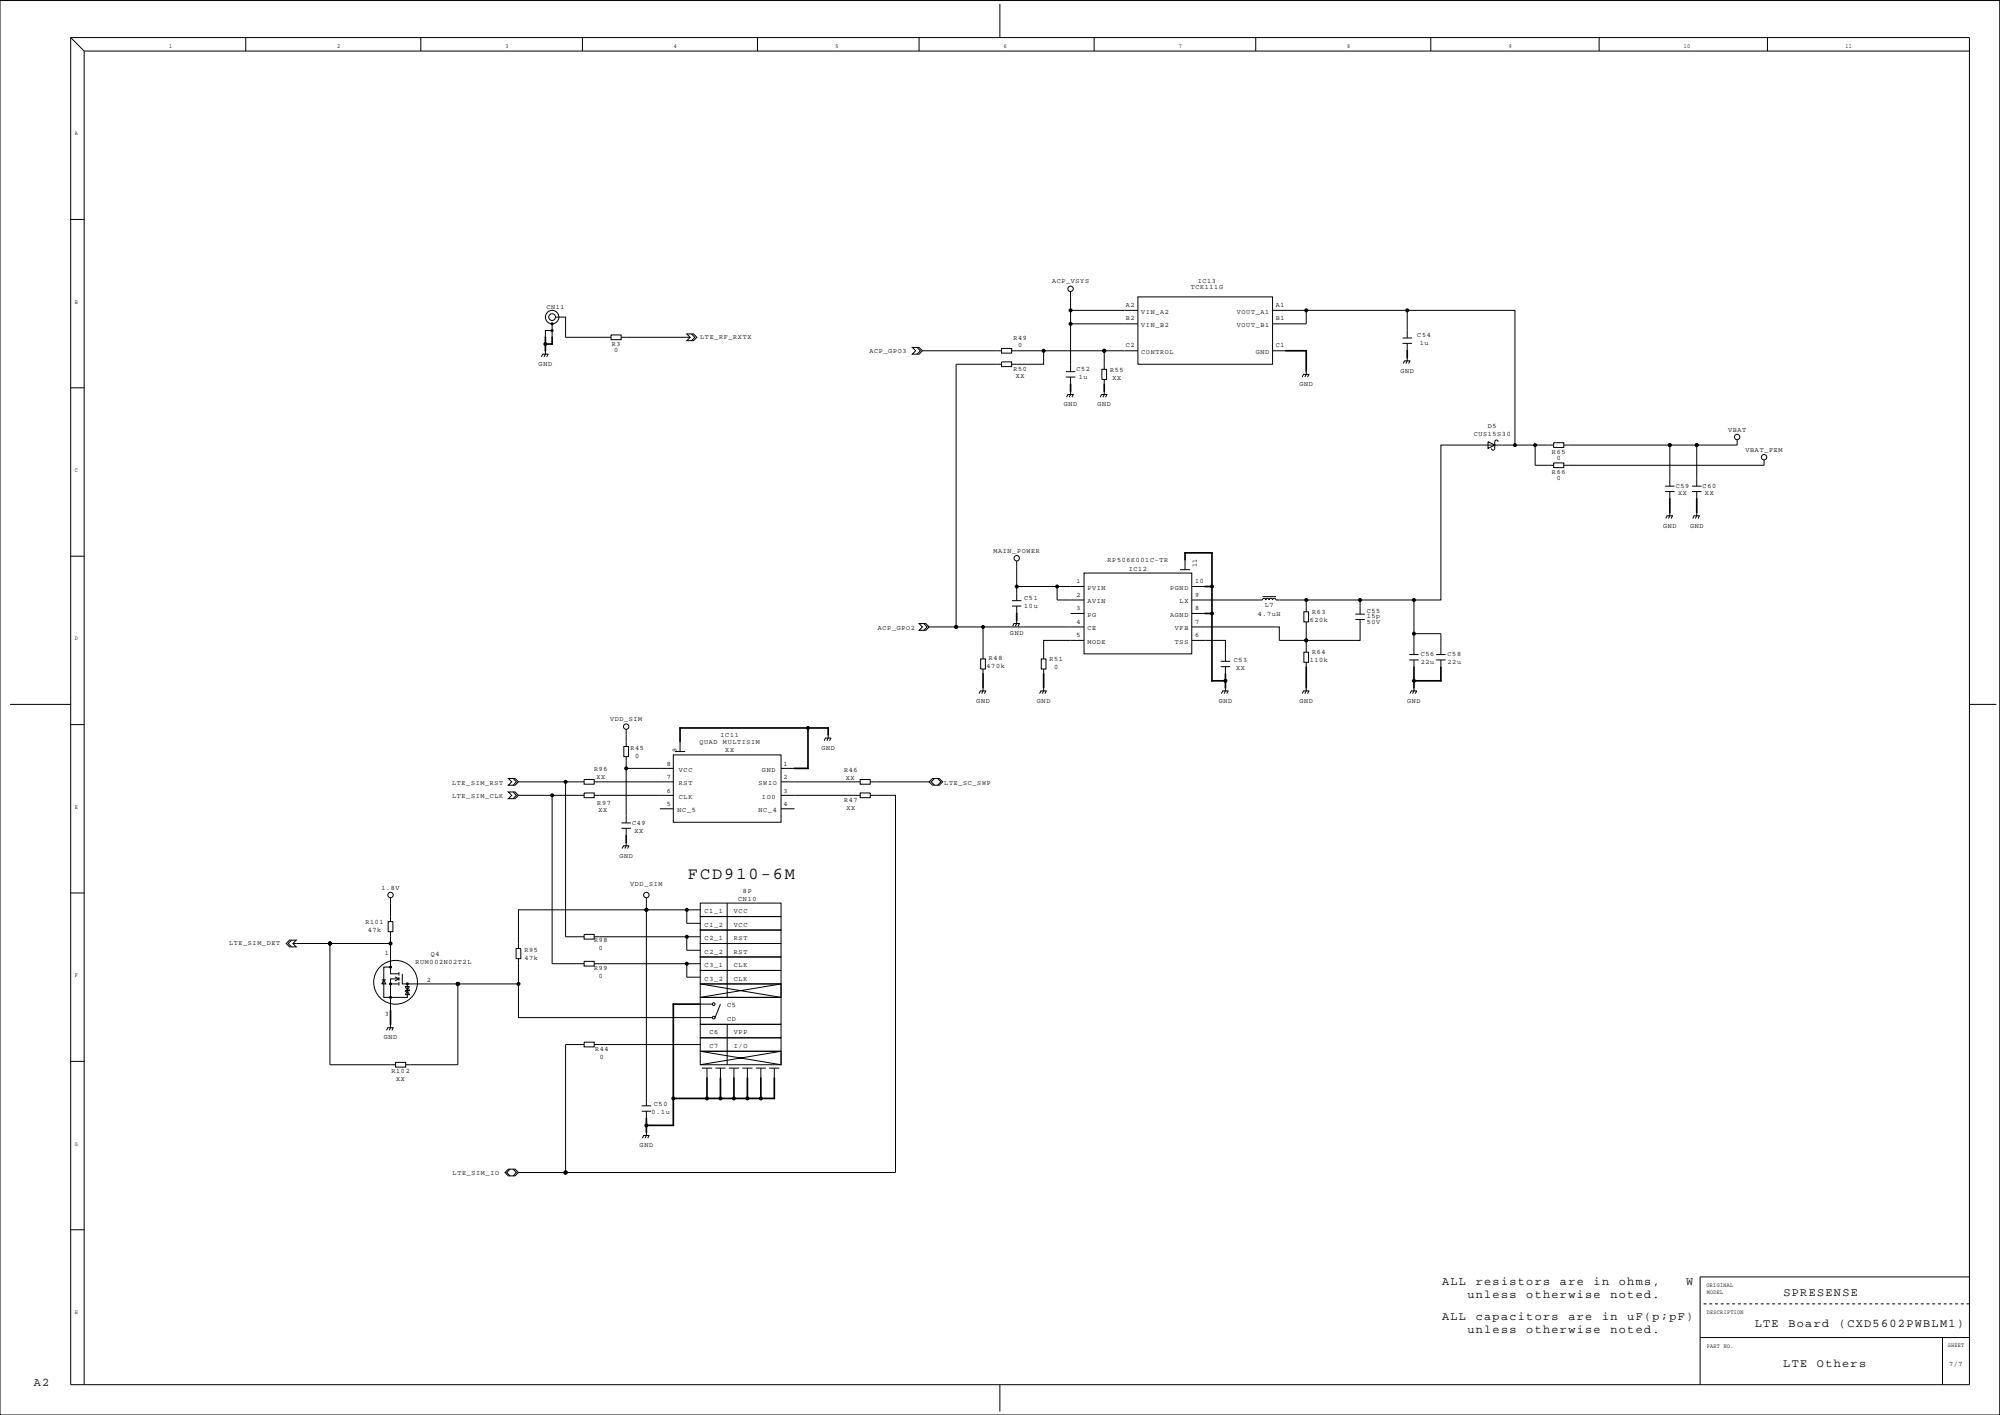
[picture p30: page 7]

C1_1 | VCC
C1_2 | VCC
C2_1 | RST
C2_2 | RST
C3_1 | CLK
C3_2 | CLK

C6 | VPP
C7 | I/O

unless otherwise noted.
ALL capacitors are in uF(p;pF)

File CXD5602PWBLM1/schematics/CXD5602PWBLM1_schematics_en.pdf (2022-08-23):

# I/O Power SW JP

# MICRO USB CN TYPE-B

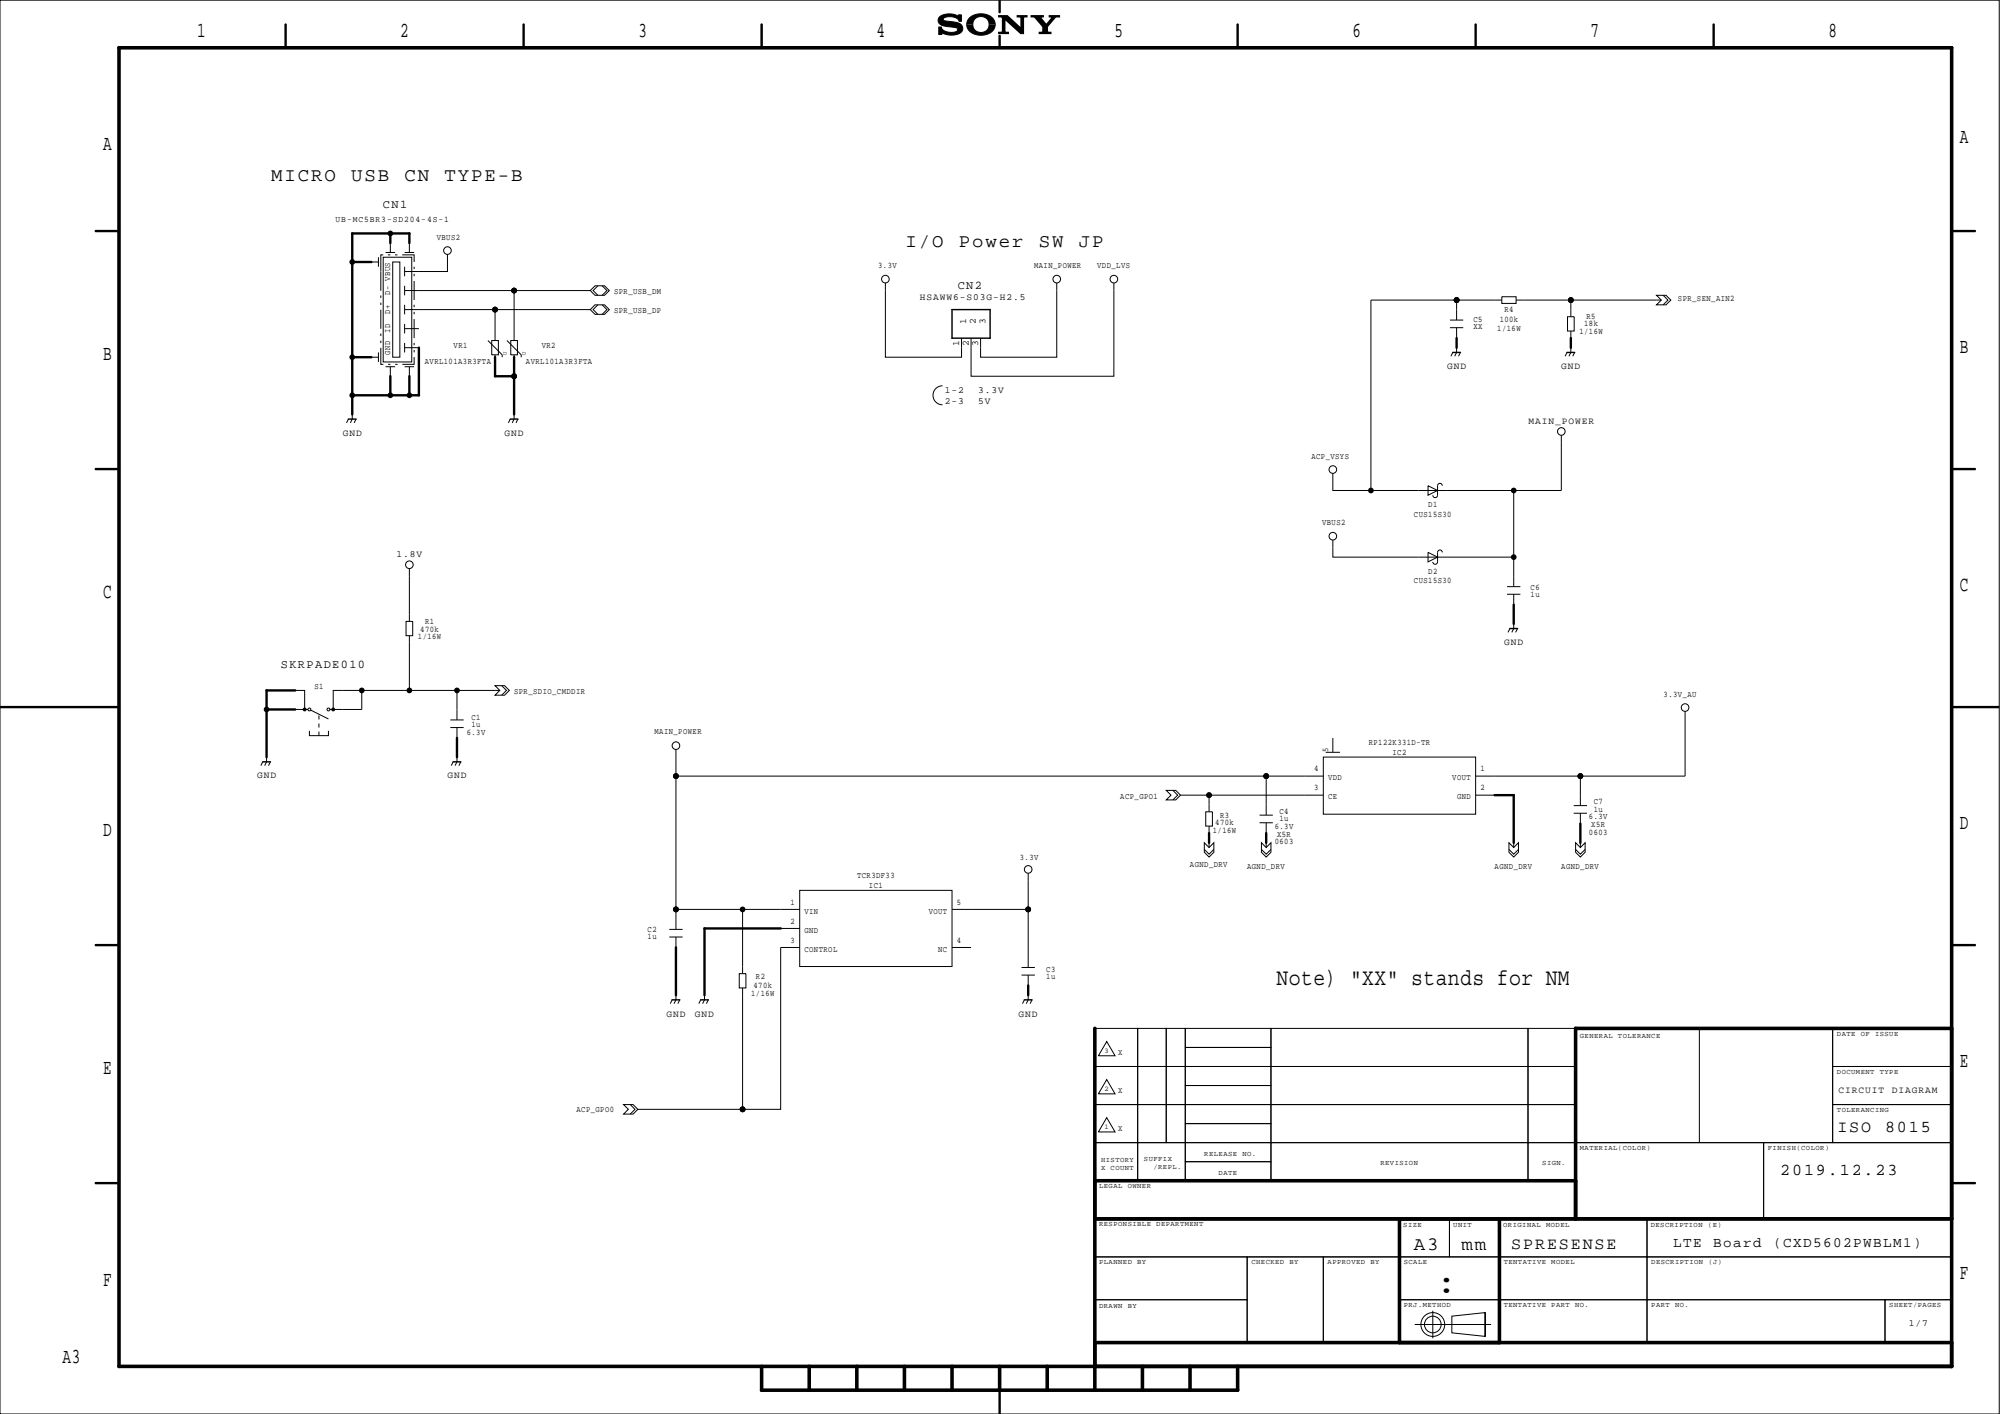
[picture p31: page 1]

Note) "XX" stands for NM

CN3

# BtoB CN

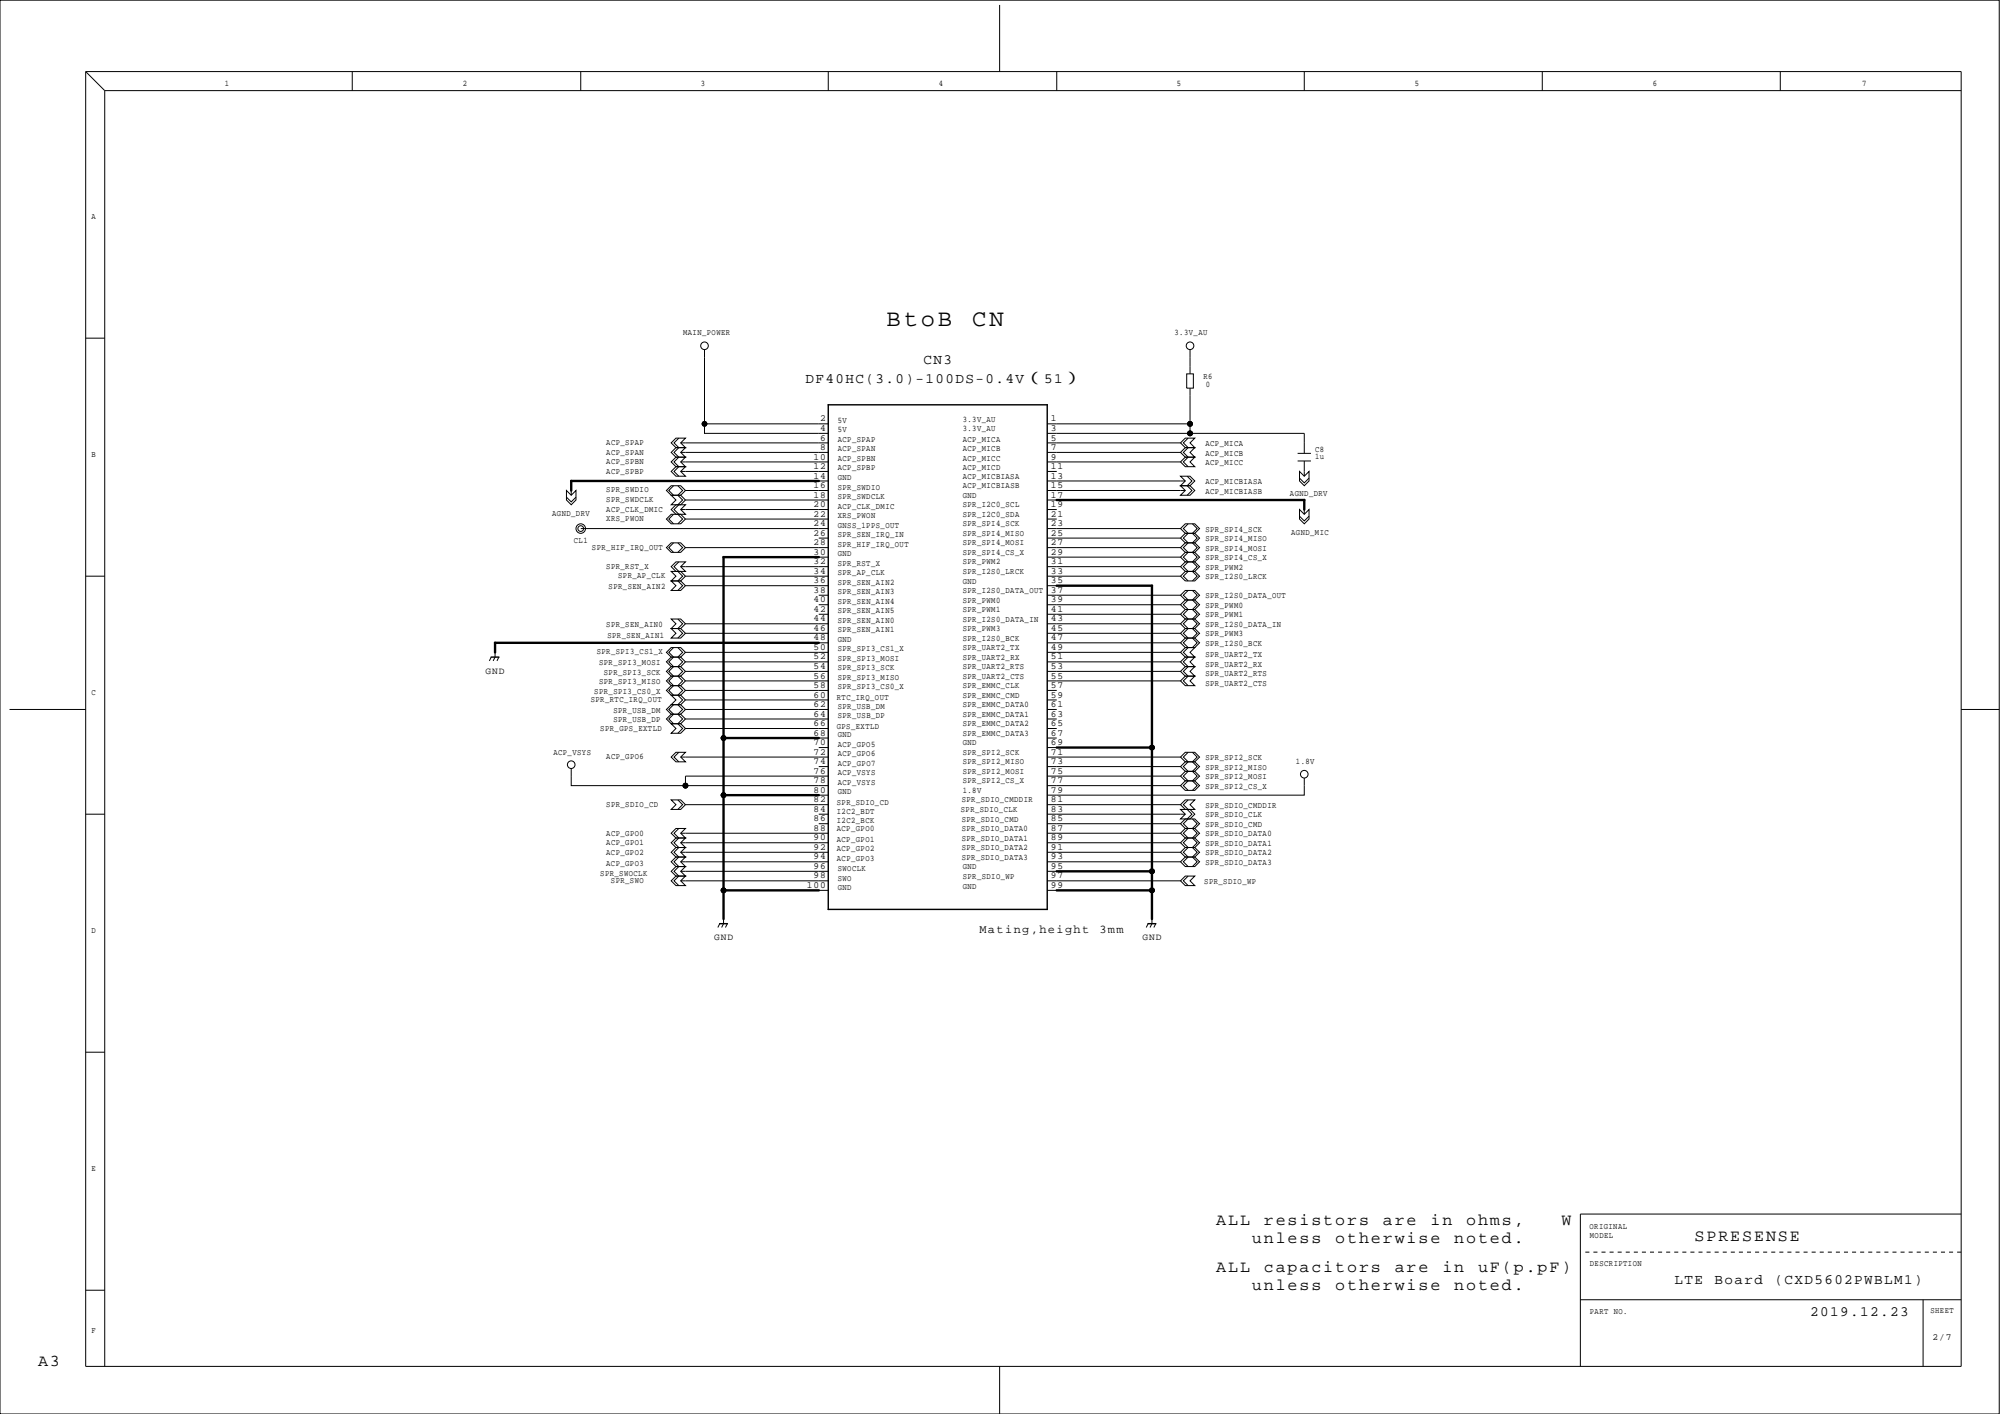
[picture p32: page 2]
SHEET; ORIGINAL; MODEL; DESCRIPTION; SPRESENSE; LTE Board (CXD5602PWBLM1); ALL resistors are in ohms,; ACP_MICB; SPR_SWDCLK; ACP_MICA; SPR_SDIO_CD; SPR_GPS_EXTLD; SPR_RTC_IRQ_OUT; SPR_AP_CLK; SPR_UART2_CTS; SPR_UART2_RTS; ACP_MICC; SPR_SEN_AIN2; SPR_SDIO_CMDDIR; SPR_UART2_RX; SPR_UART2_TX; SPR_SEN_AIN0 SPR_SEN_AIN1; SPR_SDIO_WP; ACP_GPO2; ACP_CLK_DMIC; ACP_MICBIASA; SPR_SWO; ACP_GPO3; ACP_GPO1; ACP_GPO6; SPR_SDIO_CLK; ACP_SPBP; ACP_MICBIASB; AGND_MIC; AGND_DRV; ACP_GPO0; ACP_SPAP ACP_SPAN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

unless otherwise noted.
ALL capacitors are in uF(p.pF)

# Microphone I/F

CN6

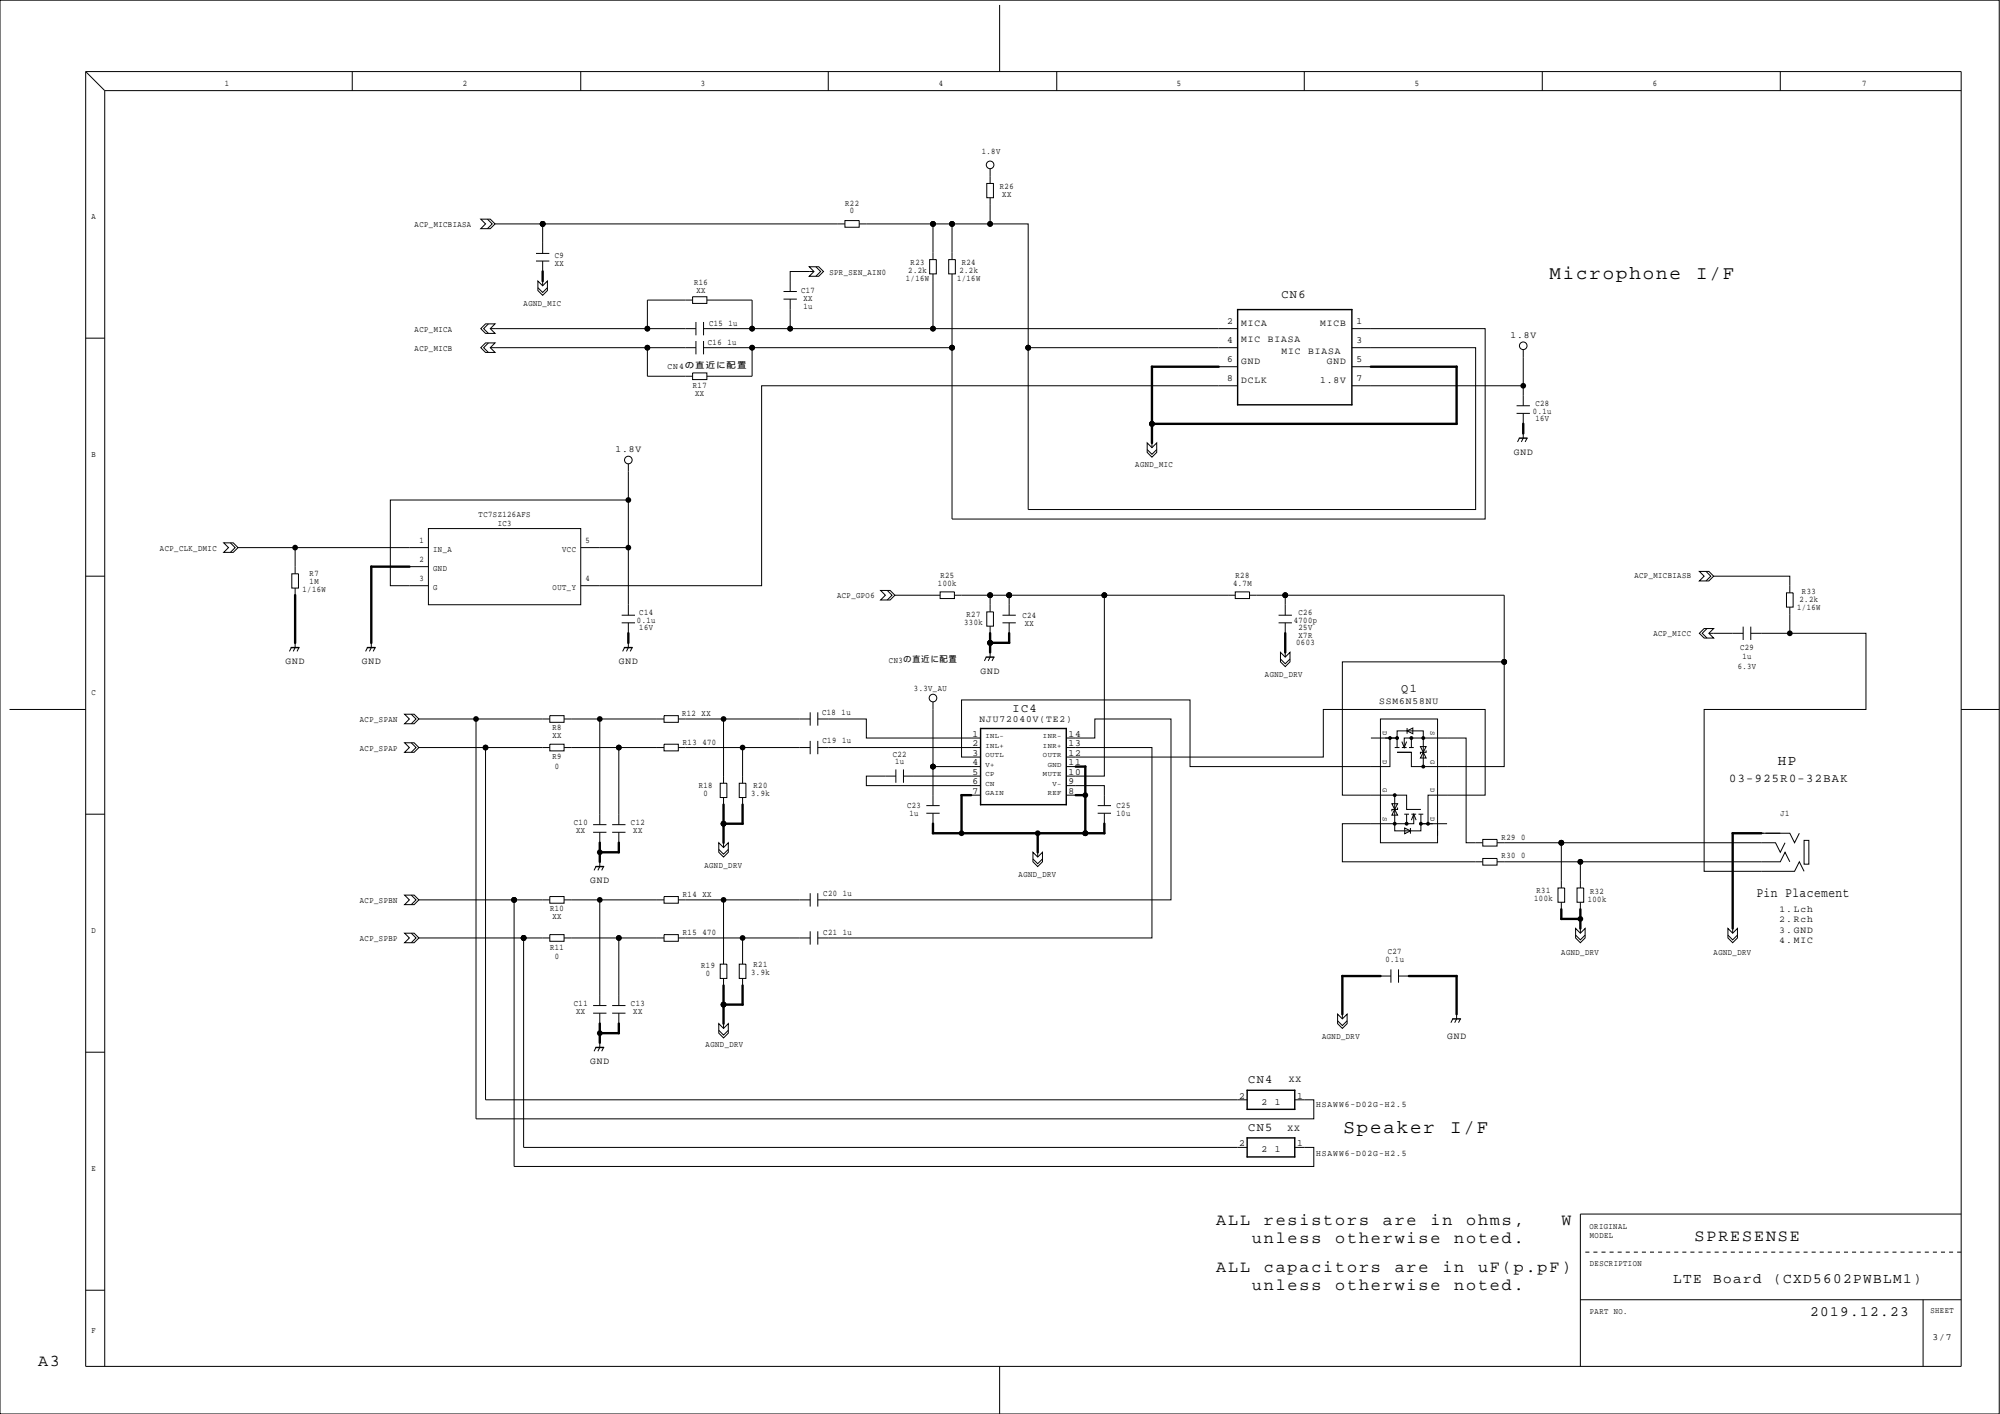
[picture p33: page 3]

unless otherwise noted.
ALL capacitors are in uF(p.pF)

# CLE9108-2A08E

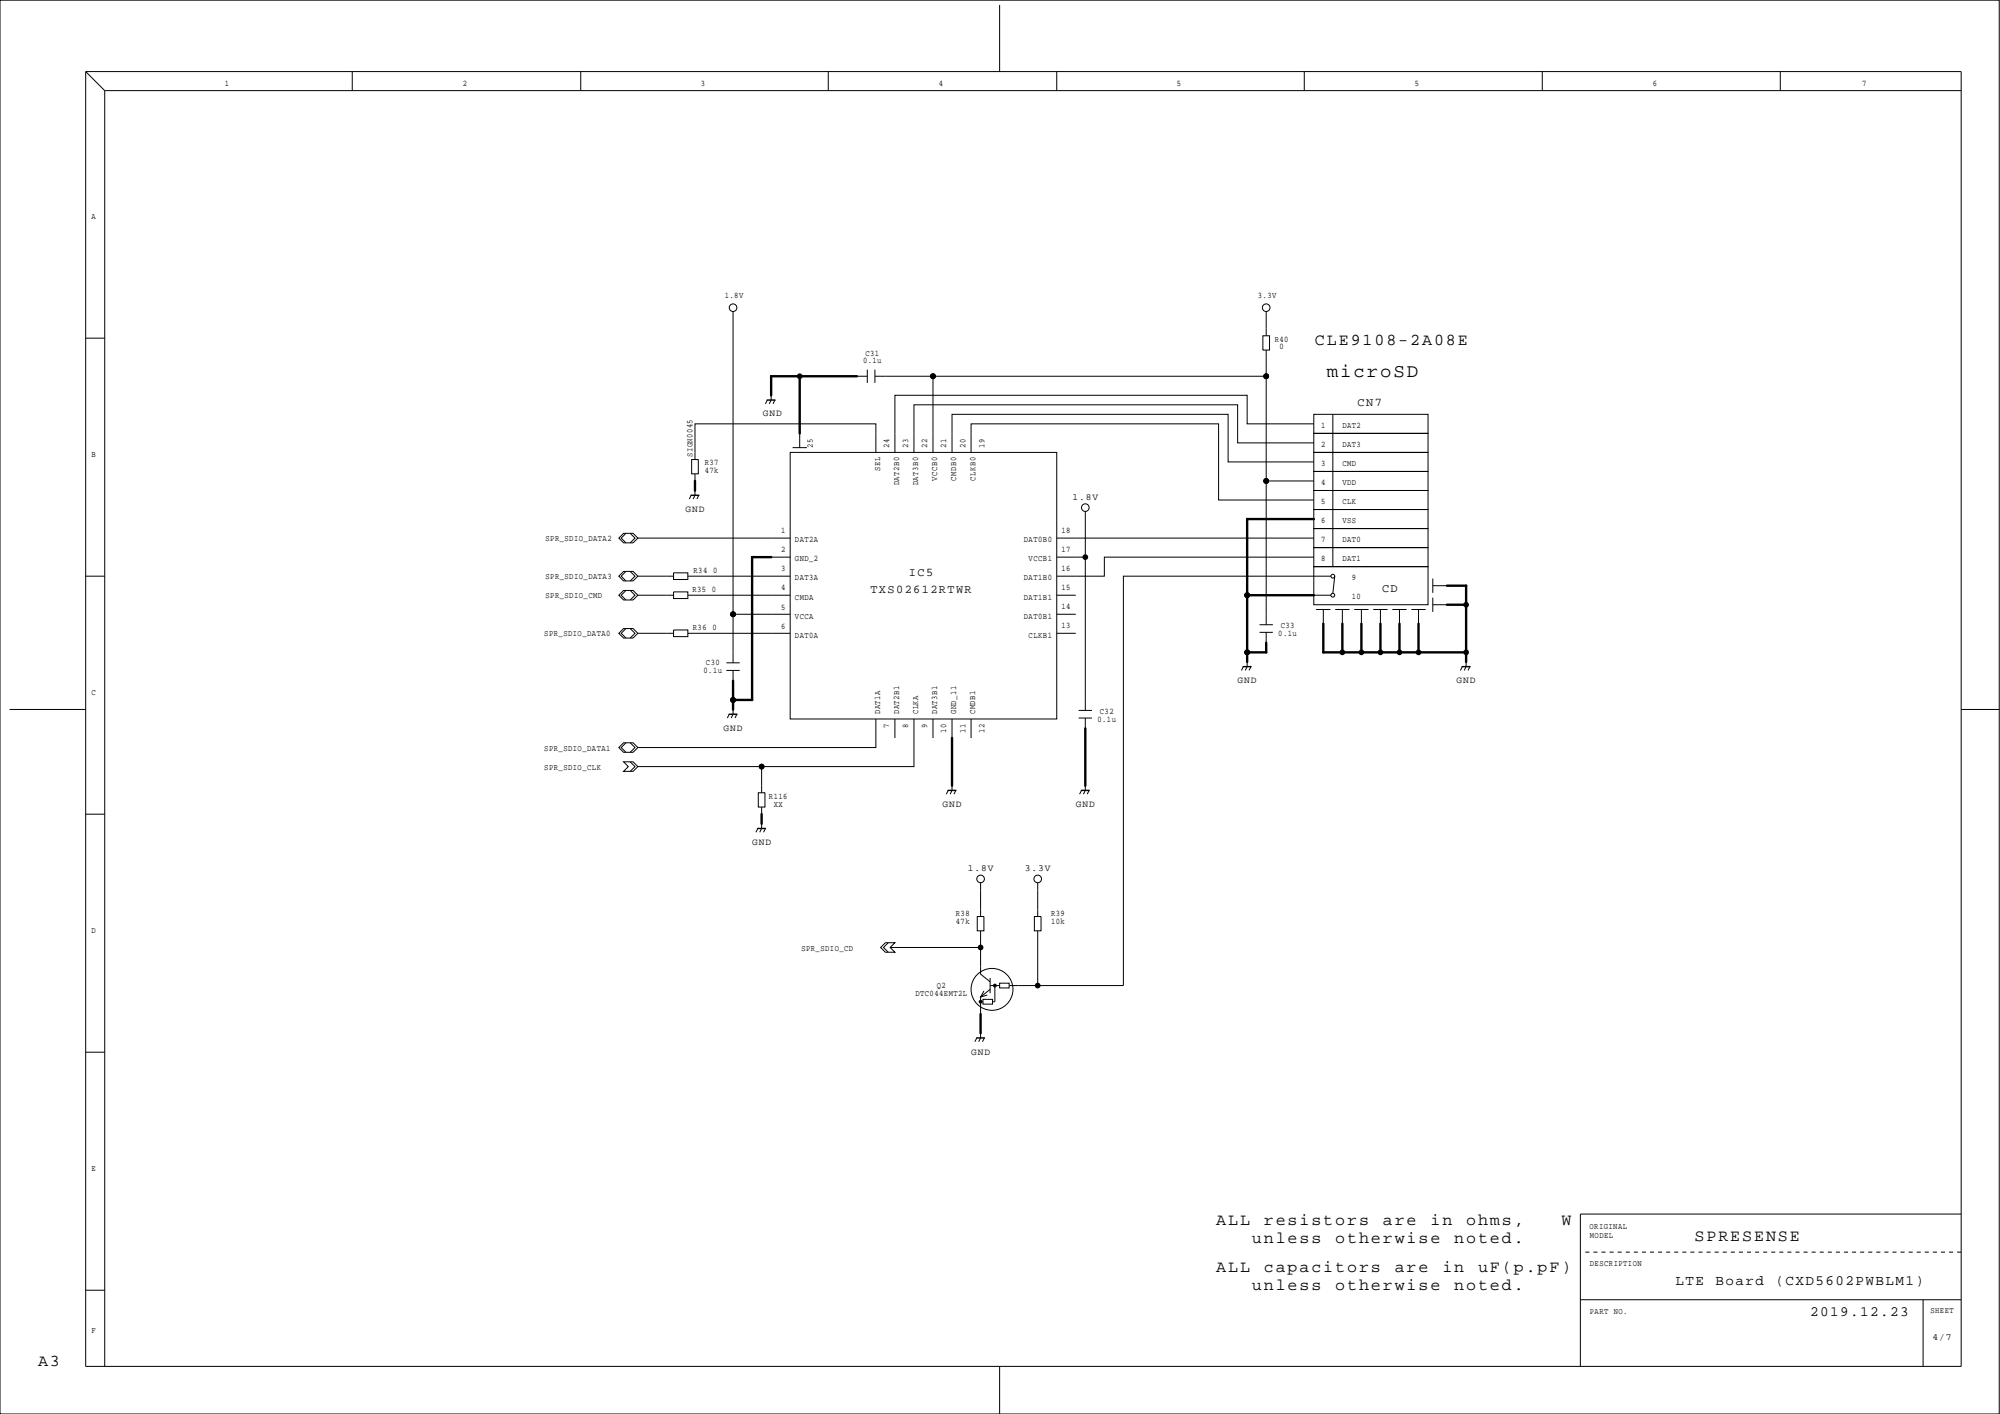
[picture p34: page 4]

1 | DAT2

2 | DAT3

4 | VDD

5 | CLK

6 | VSS

7 | DAT0

8 | DAT1

unless otherwise noted.
ALL capacitors are in uF(p.pF)

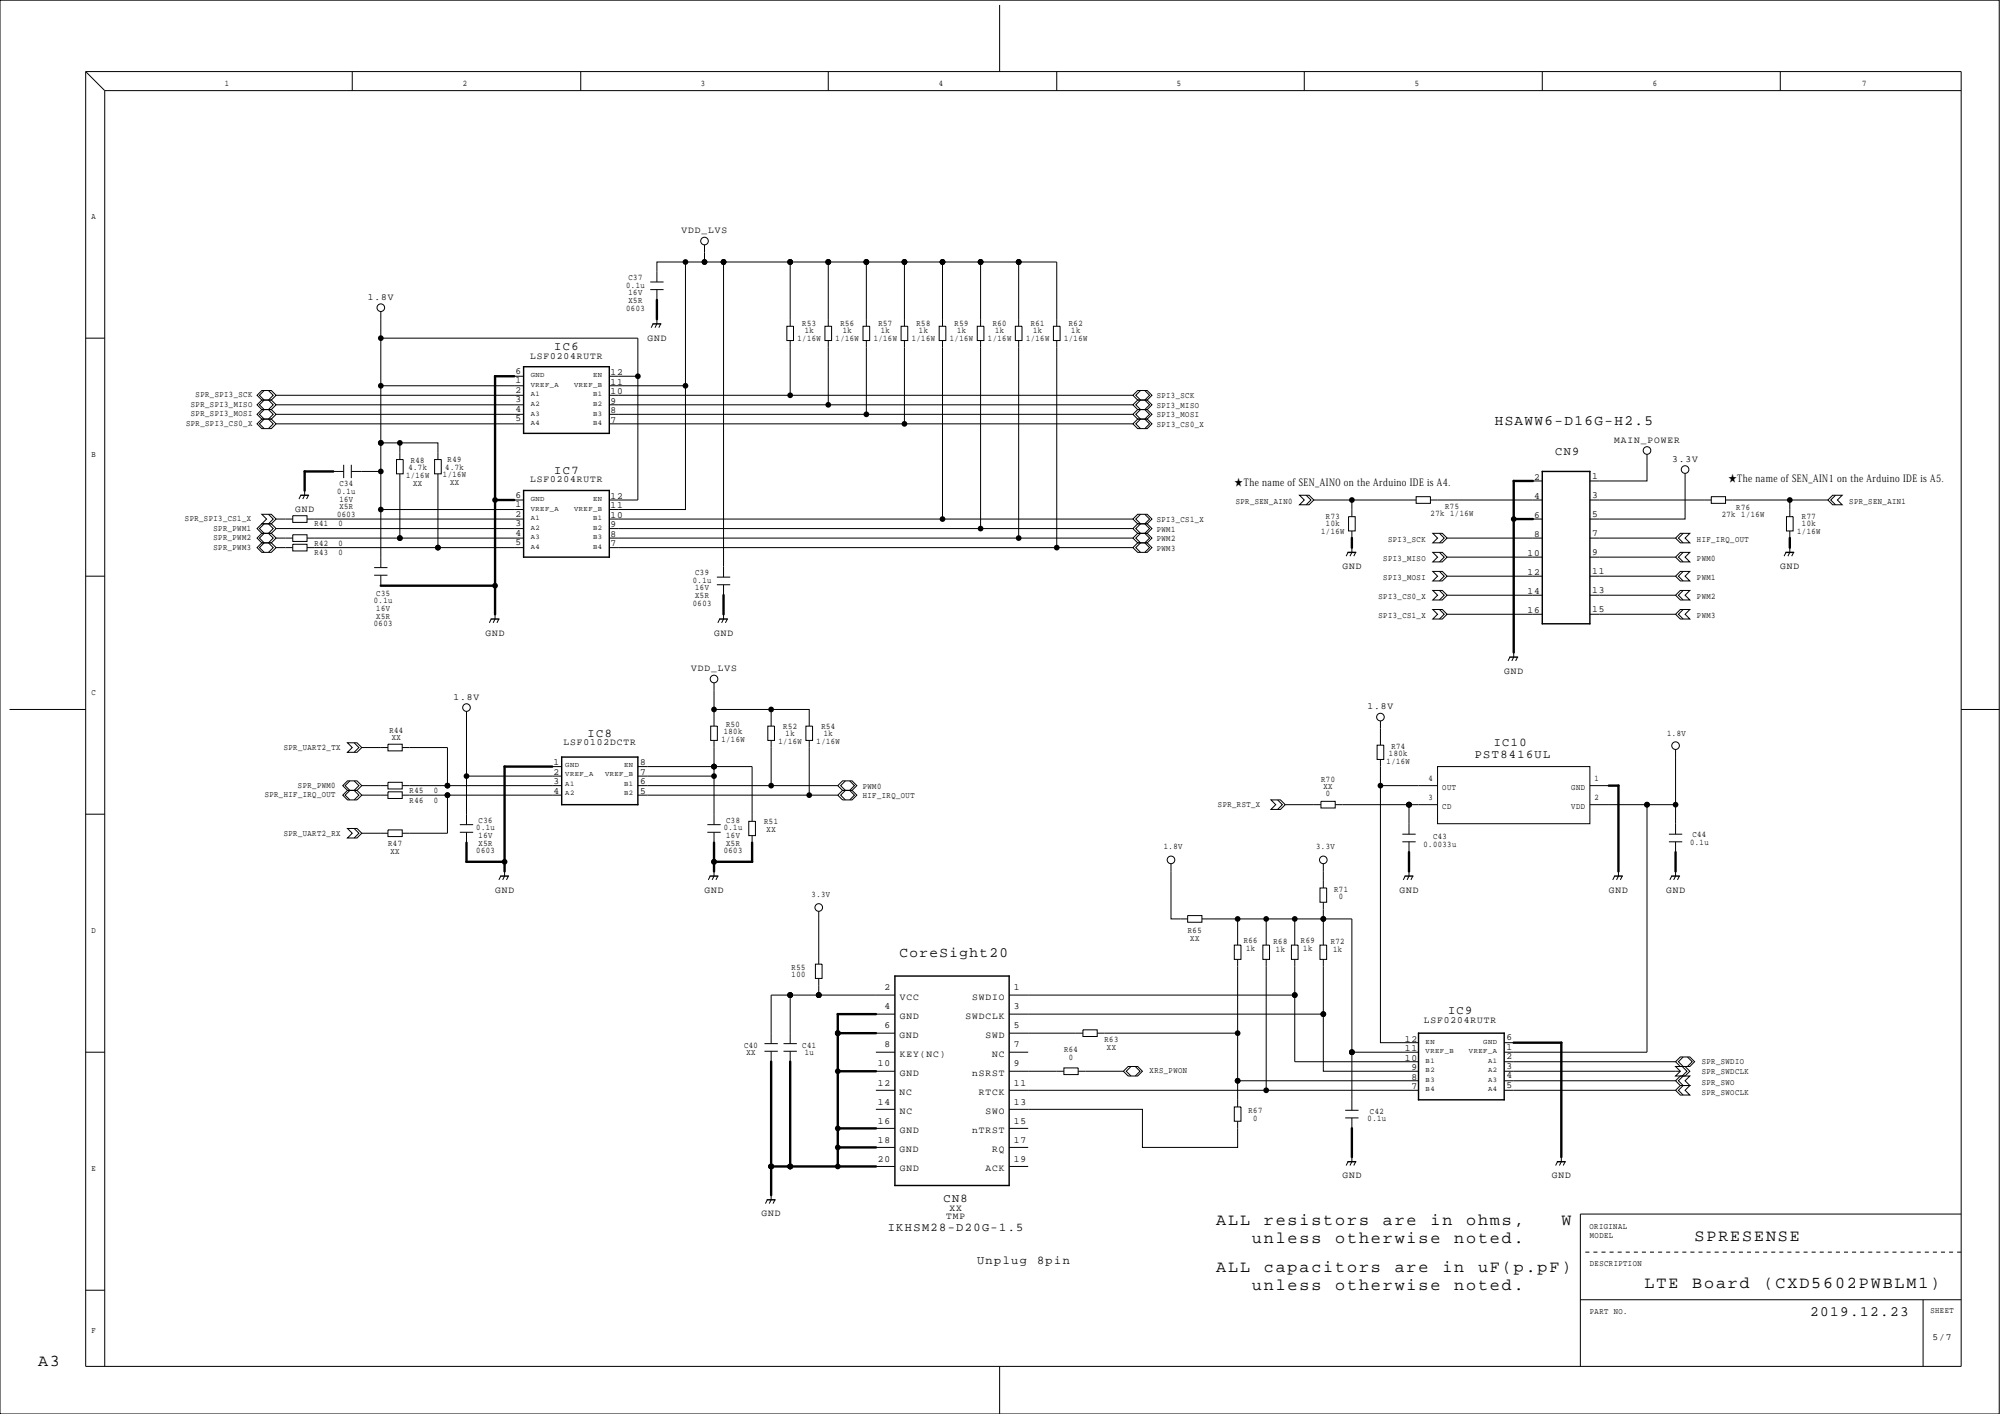
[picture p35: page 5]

unless otherwise noted.
ALL capacitors are in uF(p.pF)

# LBAD01XX1SC

CP1


unless otherwise noted.
ALL capacitors are in uF(p;pF)

IC13


Open end according to antenna layout instructions

1 | VCC(C1)

2 | RST(C2)

3 | CLK(C3)

5 | GND(C5)

6 | VPP(C6)

unless otherwise noted.
ALL capacitors are in uF(p;pF)

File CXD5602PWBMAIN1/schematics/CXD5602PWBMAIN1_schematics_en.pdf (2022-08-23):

# CXD5602GG 1/5

# SPI FLASH 8MB


Note) "XX" stands for NM

IC1

# CXD5602GG 3/5


ALL resistors are in ohms,
unless otherwise noted.
ALL capacitors are in uF(p.pF)


ALL resistors are in ohms,
unless otherwise noted.
ALL capacitors are in uF(p.pF)


ALL resistors are in ohms,
unless otherwise noted.
ALL capacitors are in uF(p.pF)

# POWER LED(Blue)

# CXD5247GF 2/3


ALL resistors are in ohms,
unless otherwise noted.
ALL capacitors are in uF(p.pF)

# USB-UART

# MICRO USB CN TYPE-B


GPIO.3/WAKEUP 11 GPIO.2/RS485 12 GPIO.1/RXT 13 GPIO.0/TXT 14
CTS 18 RTS 19 RXD 20 TXD 21 DSR 22 DTR 23 DCD 24

ALL resistors are in ohms,
unless otherwise noted.
ALL capacitors are in uF(p.pF)

# BtoB CN

ORIGINAL MODEL; DESCRIPTION; SPRESENSE; Main Board (CXD5602PWBMAIN1); SPR_SEN_AIN5; SPR_SEN_AIN1; SPR_SEN_AIN0; ACP_MICD; ACP_MICC; ACP_MICB; ACP_MICA; SPR_SEN_AIN4; SPR_SEN_AIN3; SPR_SEN_AIN2; SPR_SWDCLK; AGND_MIC; ACP_CLK_DMIC; ACP_GPO6; ACP_GPO5; ACP_GPO7; ACP_MICBIASB; ACP_SPBP; ACP_SPBN; ACP_SPAN; ACP_SPAP; AGND_DRV; ACP_MICBIASA; ACP_GPO2; ACP_GPO1; ACP_GPO3; ACP_GPO0; SPR_SPI3_SCK SPR_SPI3_MISO SPR_SPI3_CS0_X SPR_RTC_IRQ_OUT SPR_USB_DM SPR_USB_DP SPR_GPS_EXTLD; SPR_GNSS_1PPS_OUT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

ALL resistors are in ohms,
unless otherwise noted.
ALL capacitors are in uF(p.pF)

I2S0_LRCK; GPIO; UART2_TX; PIN SOCKET [L]; SPI5_SCK; I2C0_SDA; PIN SOCKET [R]; UART2_RTS; UART2_RX; I2S0_DATA_OUT; SPR_SPI5_MISO; I2S0_BCK; XRST; I2C0_SCL; SEN_IRQ; GND; UART2_CTS; SPI5_CS_X; SPR_SPI5_MOSI; SEN_AIN4; I2S0_DATA_IN; SEN_AIN5; 08FHA-SM1-GAN-ETB; IS_DATA7 IS_DATA0; IS_DATA2; I2C_SCL I2C_SDA GND; IS_DATA3; LDO_EN; IS_DATA6; PWDN; IS_HSYNC; IS_DATA1 IS_VSYNC; IS_DATA5; XRS; IS_DATA4 VDD_3.7V; MCLK; IS_CLK GND; HSCSW-S13G-H3.5; ORIGINAL MODEL; DESCRIPTION; 3 SPI3_MOSI; 6 SDIO_CMDDIR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

★XRST(SPR_RST_X) is Output.
(Voltage level is 1.8v.)

★The name of SEN_AIN5 on the Arduino IDE is A3.

★The name of SEN_AIN4 on the Arduino IDE is A2.

For Sensor Backup CN

For Imager CN

20FHT-SMR-GAN-TF

ALL resistors are in ohms,
unless otherwise noted.
ALL capacitors are in uF(p.pF)

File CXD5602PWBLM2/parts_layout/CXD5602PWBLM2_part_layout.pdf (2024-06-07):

# Side-A


# Side-B


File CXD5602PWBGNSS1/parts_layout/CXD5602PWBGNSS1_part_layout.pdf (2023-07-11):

CL7 | CL8 CL5 | CL6


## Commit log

2018-10-29 Add camera schematics etc.
    Add camera schematics etc.
2018-10-31 Temporarily add file name with old name
    Temporarily add file name such as schematics name of old name.
2019-01-15 Add CP210x old driver for Windows10
    sonydevworld/spresense-docs#608
2019-08-30 Add DXF and Update board dimension.
    Add DXF and Update board dimension.
    [CXD5602PWBCAM1_side_a.dxf, CXD5602PWBCAM1_side_b.dxf, CXD5602PWBEXT1_side_a.dxf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]
2019-09-02 updated Camera board dimensions. [ja and en]
    updated Camera board dimensions.
2019-09-06 Added stp (3d CAD).
    Added stp (3d CAD).
    [CXD5602PWBCAM1.stp, CXD5602PWBEXT1.stp, CXD5602PWBMAIN1.stp]
2019-10-17 Update Camera board 3D data.
    Update Camera board 3D data.
    [CXD5602PWBCAM1.stp]
2019-12-17 Added LTE HW designs.
    Added LTE HW designs.
    [CXD5602PWBLM1_side_a.dxf, CXD5602PWBLM1_side_b.dxf]
2019-12-18 Update CXD5602PWBLM1_schematics.pdf
    Updated schematics.
2020-05-26 Added the characteristics of on board GNSS chip antenna. [ja & en]
    Added the characteristics of on board GNSS chip antenna. [ja & en]
2020-09-07 Added Pin List(xlsx). [ja]
    Added Pin List(xlsx). [ja]
    [Spresense_pin_function_ja.xlsx]
2020-09-11 Added pin list.[en]
    Added pin list.[en]
    [Spresense_pin_function_en.xlsx]
2020-11-13 Fixed pin mode. [ja & en]
    Fixed pin mode. [ja & en]
    At main board, I2C0 → I2S0.
    [Spresense_pin_function_en.xlsx, Spresense_pin_function_ja.xlsx]
2021-02-17 fixed LTE board dimensions.[ja]
    fixed LTE board dimensions.[ja]
2021-03-09 Add case design for the LTE board.
    [LTE-Board-Case-Sample.step, LTE-Board-Case-Sample_bottom.stl, LTE-Board-Case-Sample_top.stl]
2021-04-02 Fixed_GPO_Initial_data.
    Fixed_GPO_Initial_data.
    [Spresense_pin_function_en.xlsx, Spresense_pin_function_ja.xlsx]
2021-04-14 Minor correction.[ja & en]
    Minor correction.[ja & en]
    [Spresense_pin_function_en.xlsx, Spresense_pin_function_ja.xlsx]
2021-04-19 Add case images
2021-12-21 Fixed Camera MCLK pin function. [ja & en]
    Fixed Camera MCLK pin function. [ja & en]
    [Spresense_pin_function_en.xlsx, Spresense_pin_function_ja.xlsx]
2022-01-17 Added pin list pdf. [ja & en]
    Added pin list pdf. [ja & en]
2022-03-31 First release of HDR camera documentation .[ja]
    First release of HDR camera documentation .[ja]
    [CXD5602PWBCAM2_side_a.dxf, CXD5602PWBCAM2_side_b.dxf]
2022-04-19 Updated 3D stp files.
    Updated 3D stp files.
    [CXD5602PWBCAM1.stp]
2022-04-21 Update HDR Camera Schematics.
    Update HDR Camera Schematics.
2022-08-23 Updated Main & LTE Schematics.
    Updated Main & LTE Schematics.
2022-09-07 Corrected_pin_list.[ja&en]
    Corrected the name of SPR_SPI2_SCK on ArduinoIDE.
    [Spresense_pin_function_en.xlsx, Spresense_pin_function_ja.xlsx]
2022-11-15 Add CP210x driver v11.1.0 for Windows
2023-07-11 Add GNSS_Add-on data.[ja&en]
    Add GNSS_Add-on data.[ja&en]
    [CXD5602PWBGNSS1.stp, CXD5602PWBGNSS1_side_a.dxf, CXD5602PWBGNSS1_side_b.dxf]
2024-03-21 Added LED0 to 3 on the main board and S1 on the LTE extension board.
    Added LED0 to 3 on the main board and S1 on the LTE extension board.
    [Spresense_pin_function_en.xlsx, Spresense_pin_function_ja.xlsx]
2024-06-05 Add LM2 design.[ja]
    [CXD5602PWBCAM2_side_a.dxf, CXD5602PWBCAM2_side_b.dxf.dxf]
2024-06-05 fixed file name.[jp]
    [CXD5602PWBCAM2_side_b.dxf]
2024-06-07 Minor update.[ja]
    [Spresense_pin_function_ja.xlsx]
2024-06-13 Fixed file name.[ja]
    [CXD5602PWBLM2_side_a.dxf, CXD5602PWBLM2_side_b.dxf]
